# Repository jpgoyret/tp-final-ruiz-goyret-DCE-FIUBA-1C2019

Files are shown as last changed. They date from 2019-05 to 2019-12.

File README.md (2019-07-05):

# tp-final-ruiz-goyret-DCE-FIUBA-1C2019
Trabajo Práctico final de la materia Diseño de Circuitos Electrónicos en FIUBA - 1°C 2019

Integrantes del grupo:

  * Santiago Ruiz (98052)
  * Juan Pablo Goyret (99081)

## Resumen del trabajo práctico

El trabajo consiste en el diseño, simulación y armado en PCB de un amplificador de audio de potencia mayor a 40W. El tipo de amplificador diseñado es un clase H con etapa de salida en paralelo, realizando la conmutación propia de esta configuración mediante transistores MOSFET. Dada la necesidad de alimentar al amplificador clase H mediante dos valores distintos de tensión positiva y negativa, se diseñaron, por otra parte, dos fuente de switching de +12 y -12 V. 

## Descripción del repositorio

El repositorio de encuentra estructurado en 3 carpetas principales: 

- [Amplificador](https://github.com/jpgoyret/tp-final-ruiz-goyret-DCE-FIUBA-1C2019/tree/develop/Amplificador): documentación, simulaciones y proyecto en Kicad del amplificador.
- [Supply](https://github.com/jpgoyret/tp-final-ruiz-goyret-DCE-FIUBA-1C2019/tree/develop/Supply): documentación, simulaciones y proyecto en Kicad de las fuentes de switching.
- [DOC](https://github.com/jpgoyret/tp-final-ruiz-goyret-DCE-FIUBA-1C2019/tree/develop/DOC): referencias para el diseño de los circuitos, artículos útiles y hojas de datos de amplificadores comerciales que se usaron como referencia para el proyecto.

Cada subcarpeta cuenta con un archivo README.md propio describiendo su contenido y como debe ser analizado.

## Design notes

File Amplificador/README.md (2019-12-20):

## Amplificador

Para comenzar con la lectura de la documentación del circuito ir a [Resumen_y_especificaciones.md](Resumen_y_especificaciones.md). Si bien se recomienda comenzar con este útimo archivo, el cual irá dirigiendo al lector hacia otros documentos que permitirán comprender cada vez con mayor profudidad el diseño del circuito, a continuación se listan todos los archivos contenidos en esta carpeta relacionados con el desarrollo del circuito:

- [Resumen_y_especificaciones.md](Resumen_y_especificaciones.md): contiene un resumen de las características del amplificador y lista sus especificaciones. 
- [descripcion_detallada_amplificador.md](descripcion_detallada_amplificador.md): describe las etapas del amplificador y otros subcircuitos que lo componen.
- [determinacion_valores_componentes.md](determinacion_valores_componentes.md): detalla los criterios y cálculos utilizados en la determinación de los valores y tipos de componentes empleados en el circuito.
- [explicacion_conmutadores.md](explicacion_conmutadores.md): describe el funcionamiento de los conmutadores y la utilidad y valor de cada uno de los componentes involucrados en ellos.
- [Mediciones_salida_audio_celular.md](Mediciones_audio_celular.md): este documento no se encuentra relacionado directamente con el diseño del amplificador, pero en él se detallan mediciones que se realizaron con el fin de establece la especificación de ganancia a lazo cerrado del circuito.

Por otra parte, a continuación se listan las subcarpetas asociadas al diseño del amplificador:

- [simulaciones_amplificador](./simulaciones_amplificador): se encuentran los archivos para simular el amplificador completo por medio de LTSpice. Además, en [Mediciones_parametros_simulacion.md](simulaciones_amplificador/Mediciones_parametros_simulacion.md) es posible ver los resultados de las mediciones llevadas a cabo a partir de la simulación. Se han incluido simulaciones específicas para estudiar cada especificación del amplificador. Se han agregado también los modelos necesarios para realizar las simulaciones. Para que estas se lleven a cabo correctamente basta con descargar la carpeta completa y ejecutar los archivos localizados allí adentro. 
- [pcb_amplificador](./pcb_amplificador): diseño del PCB del amplificador. 
- [mediciones_amplificador](./mediciones_amplificador): registro de las mediciones que se realizaron durante el armado del amplificador
- [imagenes_amplificador](./imagenes_amplificador): imágenes varias para la elaboración de documentos como [Resumen_y_especificaciones.md](Resumen_y_especificaciones.md) y [Mediciones_parametros_simulacion.md](simulaciones_amplificador/Mediciones_parametros_simulacion.md) .
- [datasheets_componentes_amplificador](./datasheets_componentes_amplificador): hojas de datos de los transistores y diodos utilizados en el diseño del amplificador.
- [disipadores_amplificador](./disipadores_amplificador): se encuentra la información de los disipadores utilizados y sus fundamentos.

## Resumen de especificaciones
En la siguiente tabla se comparan las especificaciones que se habían establecido como objetivos de diseño con los resultados de las simulaciones y las mediciones. En los títulos de cada columna se encuentra un link a los archivos donde se detallan las especificaciones, y la forma en la que fueron realizadas las simulaciones y las mediciones.

| Parámetro| [Diseño](Resumen_y_especificaciones.md) | [Simulación ](simulaciones_amplificador/Mediciones_parametros_simulacion.md)| [Medición](mediciones_amplificador/mediciones_finales.md) |
|---|---|---|---|
| Potencia máxima |  (No especificado, solo se dio el valor nominal, que es 45W)  | 48W | 51W |
| Eficiencia máxima | 73% | 75% | 77% |
| Alimentación |+-30V/+-12V |  +-30V/+-12V |  +-30V/+-12V  |
| Resistencia de entrada  @1kHz | >20kΩ | 26kΩ | 25KΩ |
| Resistencia de salida | 0,04Ω  	| 0,001Ω | 0,01Ω |
| Máxima tensión de entrada  | 1,2V  | 1,2V  | 1,2V |
| Ganancia de lazo cerrado | 22,8 | 22,8 | 23  |
| Consumo sin señal | <2W | 1,8 | 1,9 |
| Ancho de banda | 10Hz-400kHz | 0,8Hz-1,4MHz |  2Hz-550kHz |
| Ancho de banda de potencia sin conmutación | 40kHz | 150kHz | 53kHz |
| THD (8Ω@1khz/10%potencia)  | 0,01% |  0,0009% | 0.009% |
| Factor de amortiguamiento (8Ω@1kHz)  |	200	| 8000 | 727 |
| PSNR| >-75dB | -76dB | >-66dB |

## Fotos del prototipo

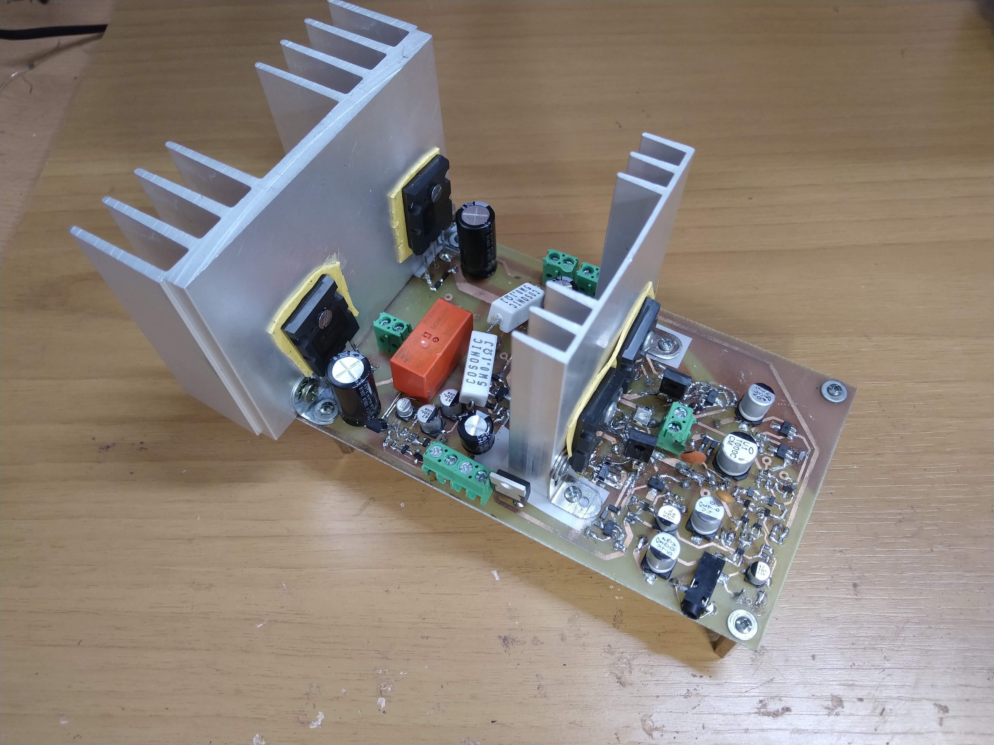
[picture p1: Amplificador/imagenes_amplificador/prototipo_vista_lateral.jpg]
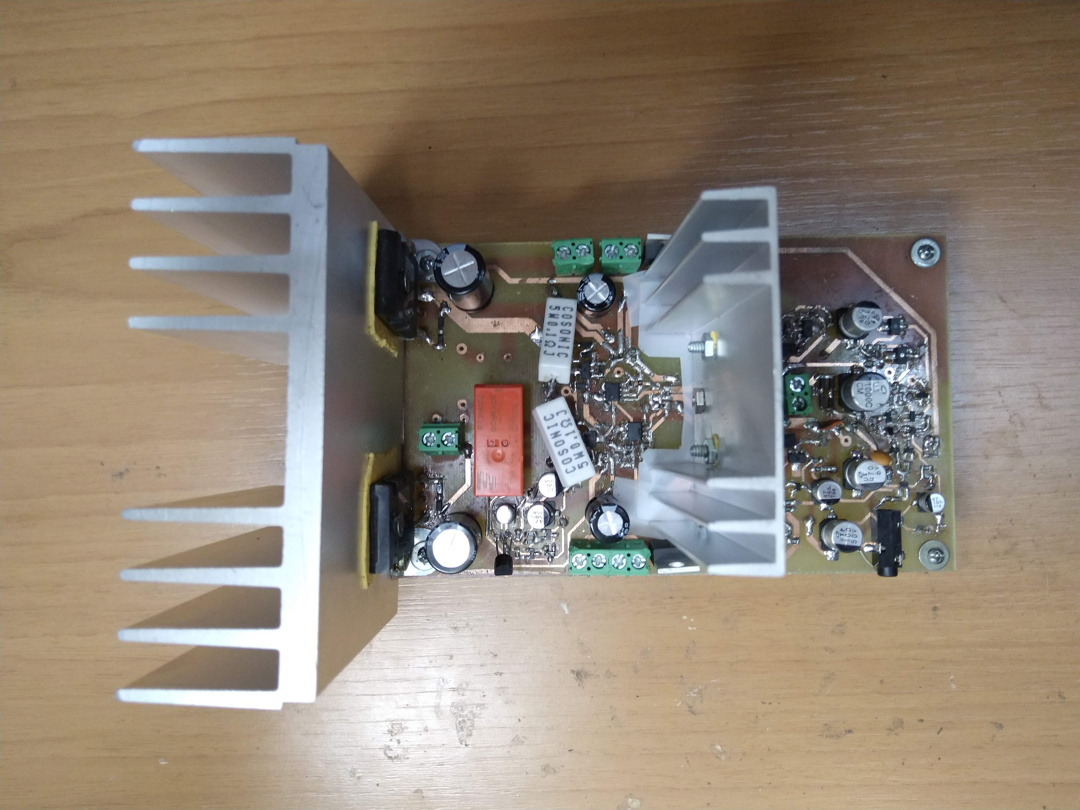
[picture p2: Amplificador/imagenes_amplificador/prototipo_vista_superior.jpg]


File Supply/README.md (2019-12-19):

## Fuente de alimentación

En esta carpeta podrán encontrase todo lo relacionado con el diseño de la fuente de alimentación. Para ver un resumen de la descripción del amplificador junto con sus especificaciones ir a [Resumen_y_especificaciones.md](Resumen_y_especificaciones.md):

- [simulaciones_supply](./simulaciones_supply): se encuentran los archivos para simular fuente de conmutación completa por medio de LTSpice.
- [mediciones_supply](./mediciones_supply): se encuentran los resultados de las mediciones del circuito armado y funcionando, al igual que mediciones intermedias durante el desarrollo. 
- [pcb_supply](./pcb_supply): proyecto en Kicad con el diseño del PCB de la fuente switching. Se incluyen las bibliotecas de componentes y "footprints" necesarios. Para visualizar correctamente el proyecto es suficiente con descargar la carpeta completa y ejecutar los archivos localizados allí adentro.
- [imagenes_supply](./imagenes_supply): imágenes varias para la elaboración de documentos como [Resumen_y_especificaciones.md](Resumen_y_especificaciones.md).

A continuación se resumen las especificaciones principales, comparando los valores en etapa de diseño, en simulación y en la medición del circuito armado:

| Parámetro | [Diseño](Resumen_y_especificaciones.md) | [Simulación](./simulaciones_supply) | [Medición ](./mediciones_supply) |
|---|---|---|---|
| Tensión de salida | 10V-20V | 0.8V-60V | 0.8-32V |
| Corriente máxima | 5A | 5.5A | 5.2A |
| Tensión de entrada | 30V | 3.5V-60V | 3.5V-32V |
| Eficiencia máxima | >80% | 98% | 92% |
| Ripple con carga (8ohm) | <100mVpp | 85mVpp | 40mVpp |
| Ripple sin carga | <100mVpp | (Despreciable) | 106mVpp |
| Frecuencia de operación | >100kHz | 350kHz | 300 - 340kHz |

## Fotos del prototipo

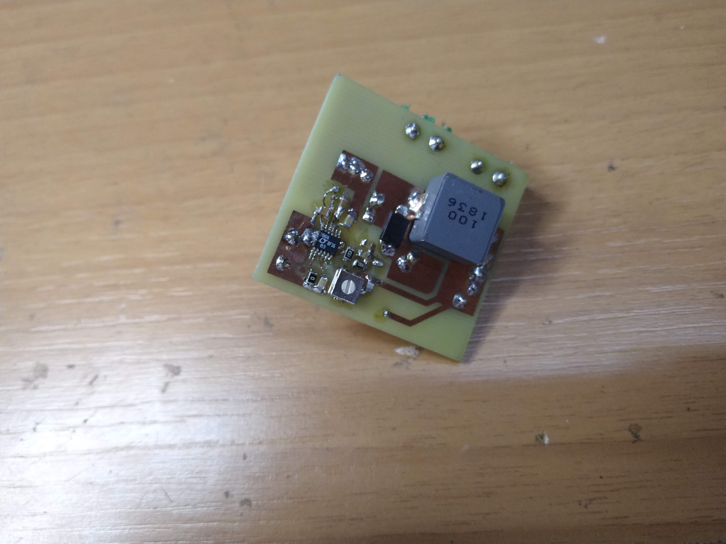
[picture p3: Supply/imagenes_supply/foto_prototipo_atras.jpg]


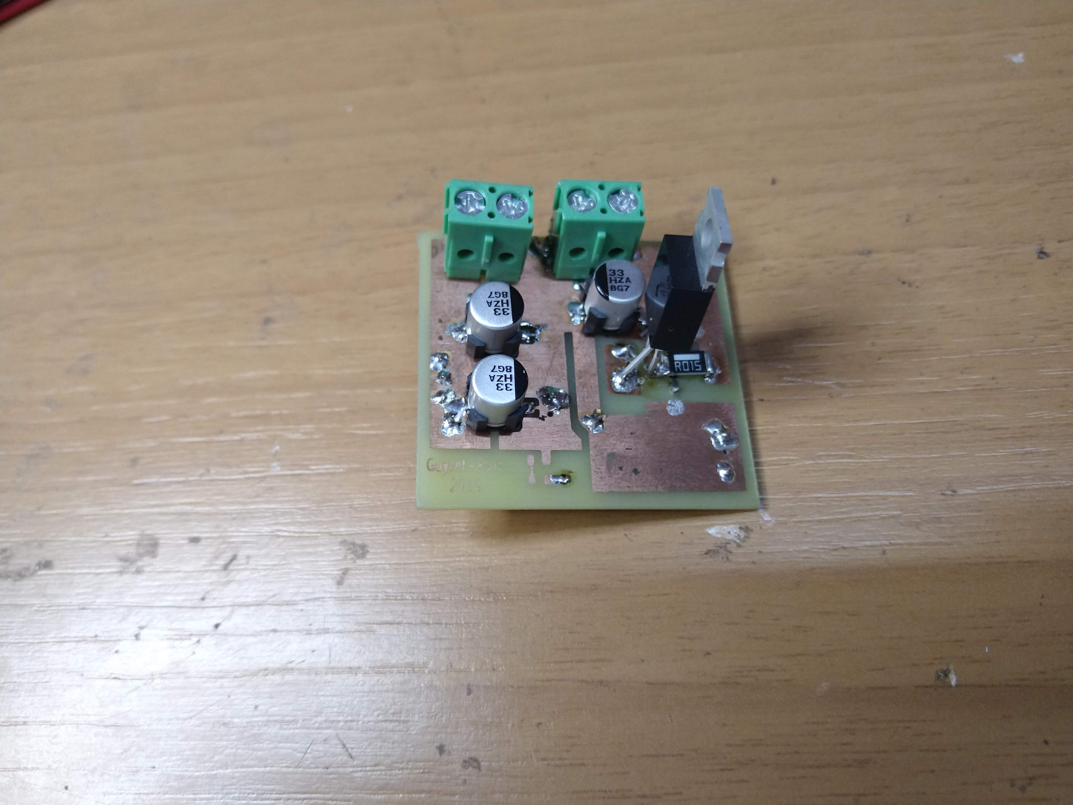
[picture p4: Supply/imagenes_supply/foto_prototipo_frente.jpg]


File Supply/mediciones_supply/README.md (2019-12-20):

## Registro de las mediciones realizadas durante el diseño de la fuente conmutadora

En esta carpeta se incluye un registro de las mediciones realizadas durante el armado de la fuente conmutadora, identificadas por fecha según el progreso realizado. Las fechas de las mediciones fueron las siguientes:

- [5/7/19](Mediciones_supply_5_7_19.md)
- [15/7/19](Mediciones_supply_15_7_19.md)

## Mediciones finales

### Regulación de linea
Se midió la salida de la fuente para distintos valores de alimentación. Las mediciones fueron realizadas con un multímetro UNI-T UT39B, con una incertidumbre de 0,5% + 3 dígitos.
Se obtuvieron los siguientes resultados:

| V_in | E(V_in) | V_out | E(V_out) |
| --- | --- | --- | --- |
| 29,9V | 0,5V | 12,00V | 0,1V  |
| 24,9V | 0,4V | 11,96V | 0,1V |
| 19,9V | 0,4V |  11,88V  | 0,1V |
| 16,9V | 0,4V |  11,83V | 0,1V |
| 12,98V | 0,1V |  11,83V | 0,1V |

Donde E(X) denota la incertidumbre del parámetro X.

Realizando el cálculo de la regulación de linea con la primer y la tercer fila de la tabla (ya que si se usara la segunda diferencia de los valores obtenidos caería dentro de la incertidumbre de medición) se obtiene:

 

No se reporta la incertidumbre del porcertaje de ripple ya que este resulta demasiado grande en comparación con el valor medio calculado.

### Regulación de carga
Se midió la tensión media de salida con una carga de 9,3ohm y con la salida en vacío. Las mediciones se llevaron a cabo con un multímetro UNI-T UT39B, con una incertidumbre de 0,5% + 3 dígitos. 
Con una tensión de alimentación de 30V se obtuvo:

- Sin carga:  
- Con carga:   

Se tuvo entonces una diferencia en la tensión media de salida de:

 

No se reporta una incertidumbre ya que esta mayor que el valor medido en sí. Entonces, el resultado obtenido solo representa una impresión de como se comporta la fuente conmutada en cuanto a su regulación de carga.

### Ripple
Se realizaron dos pruebas: en la primera se midió el ripple a la salida en vacio, es decir, sin carga. Las mediciones se realizaron con un osciloscopio RIGOL DS1302CA, con punta X10, filtro de 20MHz y modo de adquisición promediador en 8.

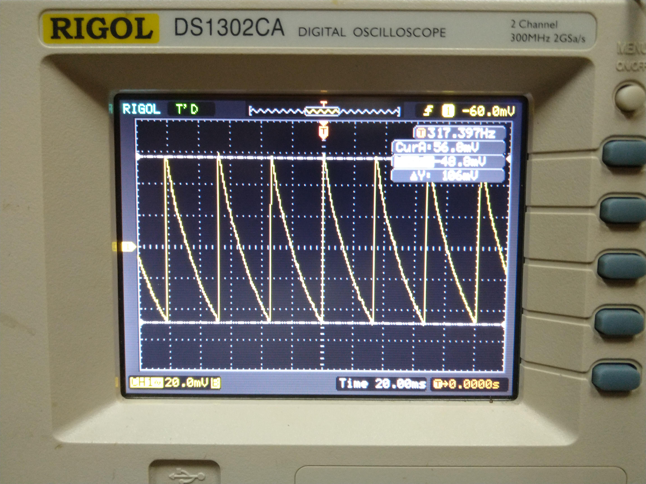
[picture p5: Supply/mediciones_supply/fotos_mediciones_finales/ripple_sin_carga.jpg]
 

Se obtuvo un ripple de  .

Luego, se midió el ripple con una carga de 8ohm.

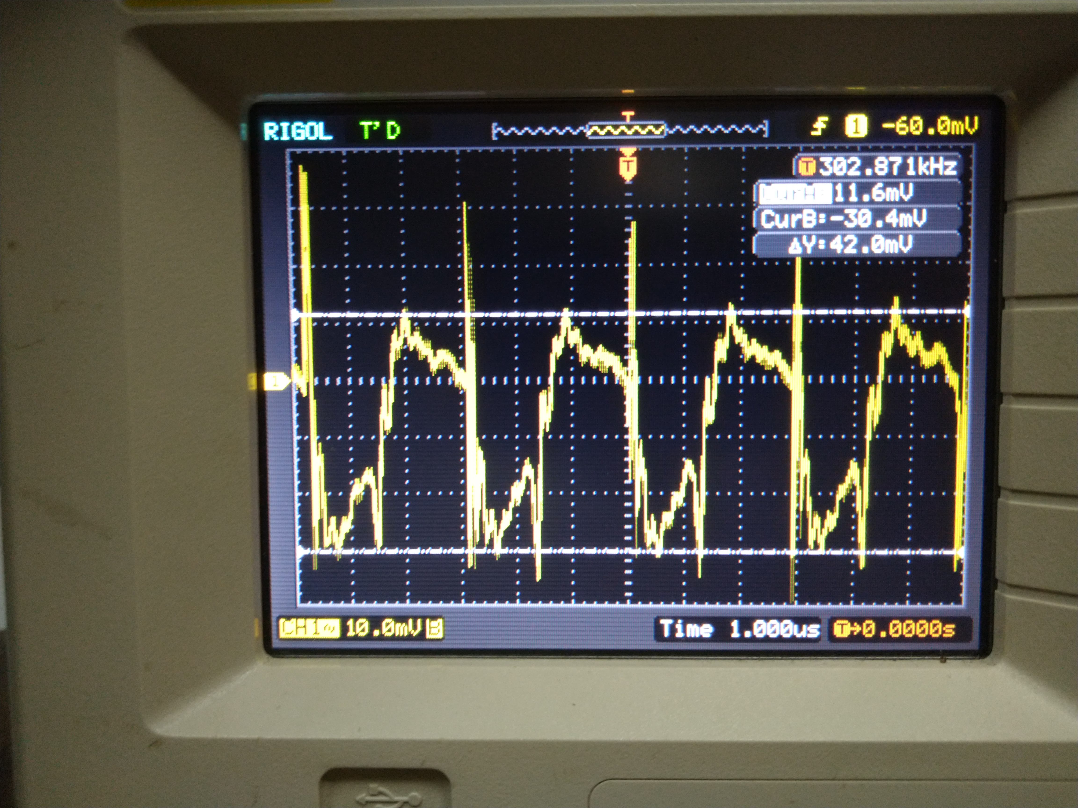
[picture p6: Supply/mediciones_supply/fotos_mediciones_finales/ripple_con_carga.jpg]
 

Se obtuvo un ripple de  .

### Eficiencia
Condición de medición: R_out=10.1ohm 25W

| V_in | I_in | V_out | I_out | Eff |
| --- | --- | --- | --- | --- |
| 29V | 0.59A | 11.98V | 1.19A | 83% |
| 20V | 0.83A | 12.1V  | 1.2A  | 87% |
| 15V | 1.1A  | 12.27V | 1.21A | 90% |
| 13V | 1.25A | 12.3V  | 1.22A | 92% |

### Emisiones
Se probó medir a simple vista y comparar las emisiones de la fuente cuando se encontraba cargada con 8ohm o sin ella. Para ello se conectó la punta del osciloscopio con si misma para formar una antena y se la acerco a 5cm del transistor de la fuente aproximadamente. Los resultados obtenidos fueron los siguientes:

Para emisiones con carga:

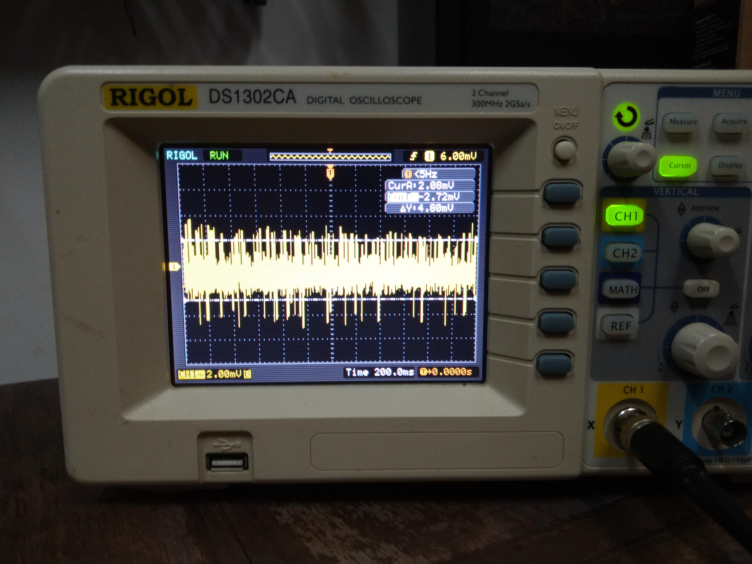
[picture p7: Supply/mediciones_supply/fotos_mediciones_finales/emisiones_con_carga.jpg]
 

Para emisiones con carga:

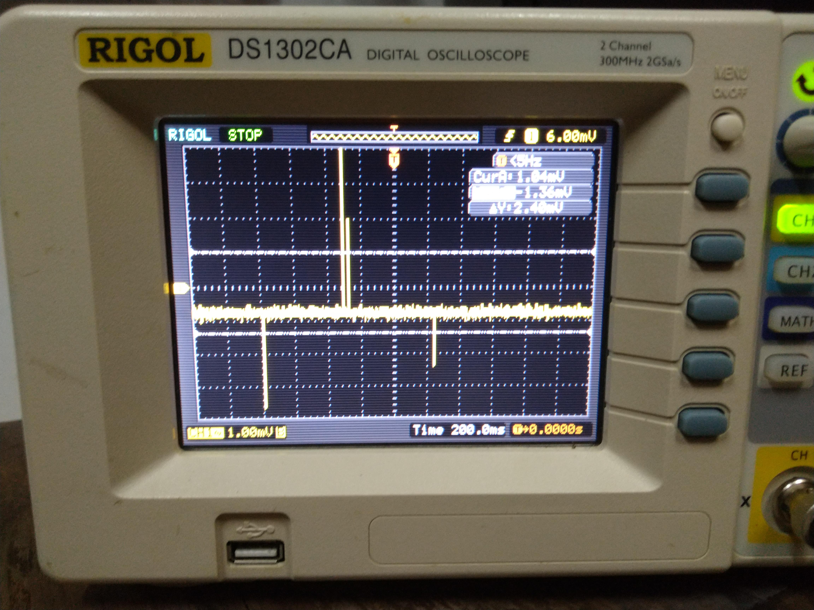
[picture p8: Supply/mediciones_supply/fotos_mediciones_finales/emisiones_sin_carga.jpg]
 

Se ve que las emisiones son mucho mayores en el primer caso ya que el consumo de corriente de la fuente es mucho menor. En consecuencia, el integrado que controla a la switching entra en un modo donde deja intervalos de tiempo en los que no conmuta, ya que no es necesario cargar al capacitor de salida. Por esto es que en la segunda imagen se obvservan pulsos espaciados, y no continuos como en la primer foto.

### Frecuencia de operación
Se realizaron varias mediciones y se observó que, con carga, la frecuencia de operación variaba entre aproximadamente 300kHz y 350kHz. Por ejemplo, en la imagen del ripple con carga que se mostró anteriormente, este era de 320kHz. Por otra parte, para mediciones sin carga, la fuente disminuye su frecuencia de operación ya que la corriente que se le pide a la salida es muy baja. Como se puede ver en la captura del ripple sin carga, esta frecuencia ronda los 300Hz.

Los valores de las frecuencias fueron obtenidos utilizando el contador interno de un osciloscopio RIGOL DS1302CA

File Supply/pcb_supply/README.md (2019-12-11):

## Fuente de alimentación

En esta carpeta se encuentra el proyecto de diseño del PCB realizado en _KiCad_.
Se observa a continuación el esquemático circuital y el diseño final del PCB.

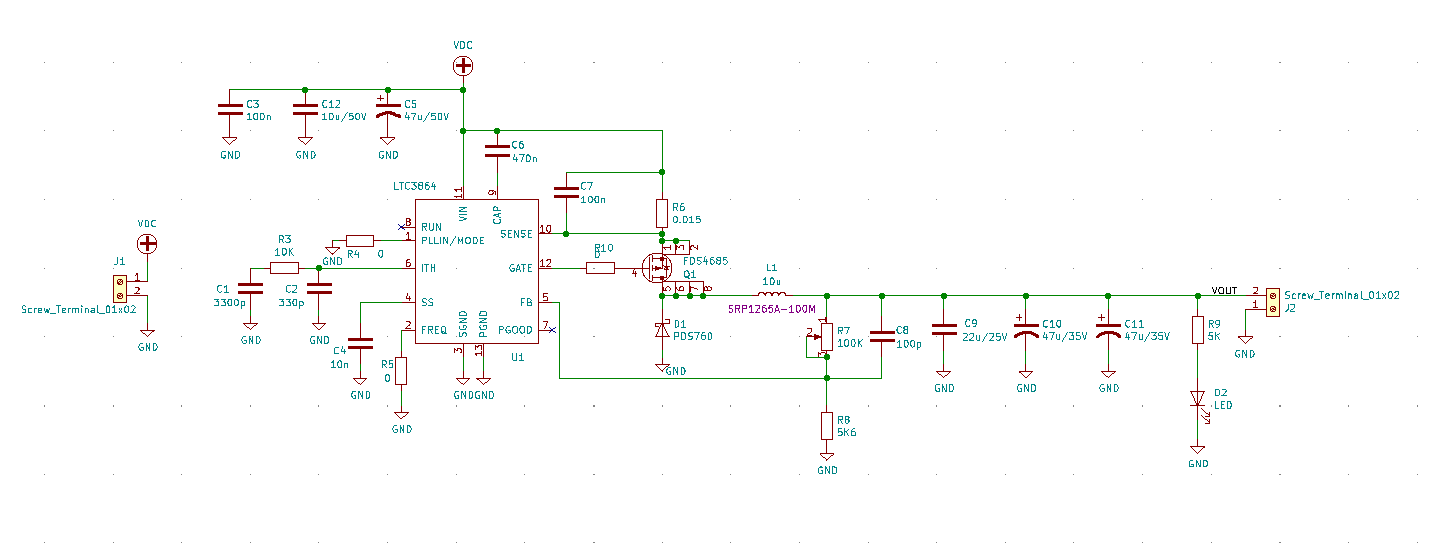
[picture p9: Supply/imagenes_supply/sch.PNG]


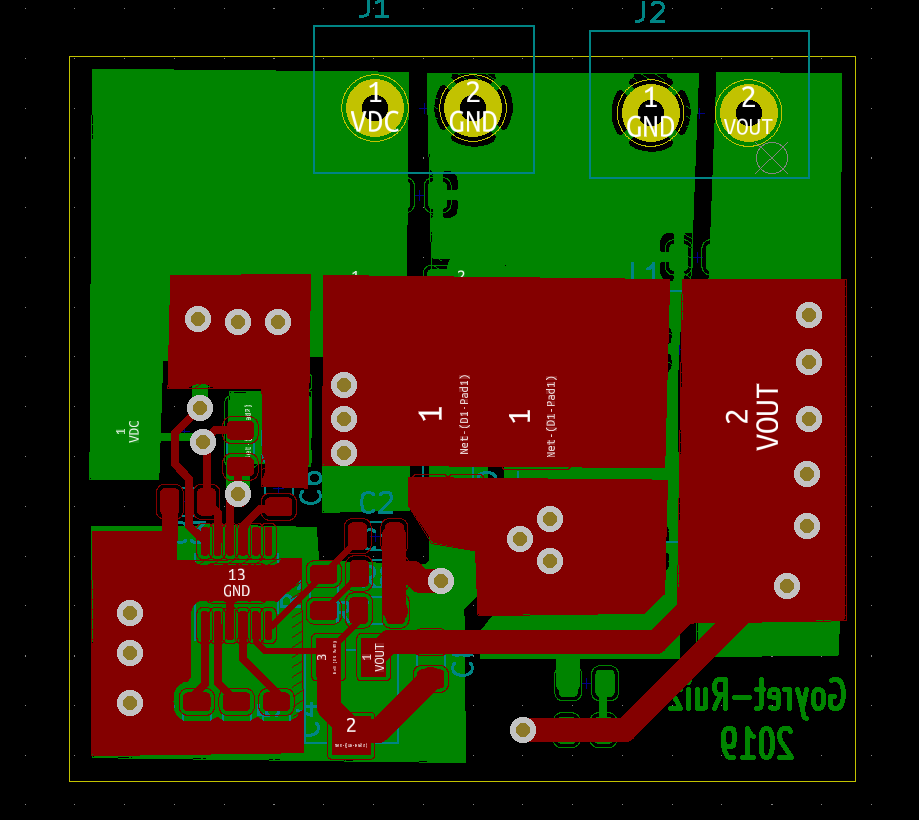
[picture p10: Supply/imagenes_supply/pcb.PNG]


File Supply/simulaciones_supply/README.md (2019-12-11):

## Mediciones de parámetros

### Regulación
Se realiza la simulación para Vin=28V, Vout=12V, RL=8Ω y se grafica Vout en función del tiempo:

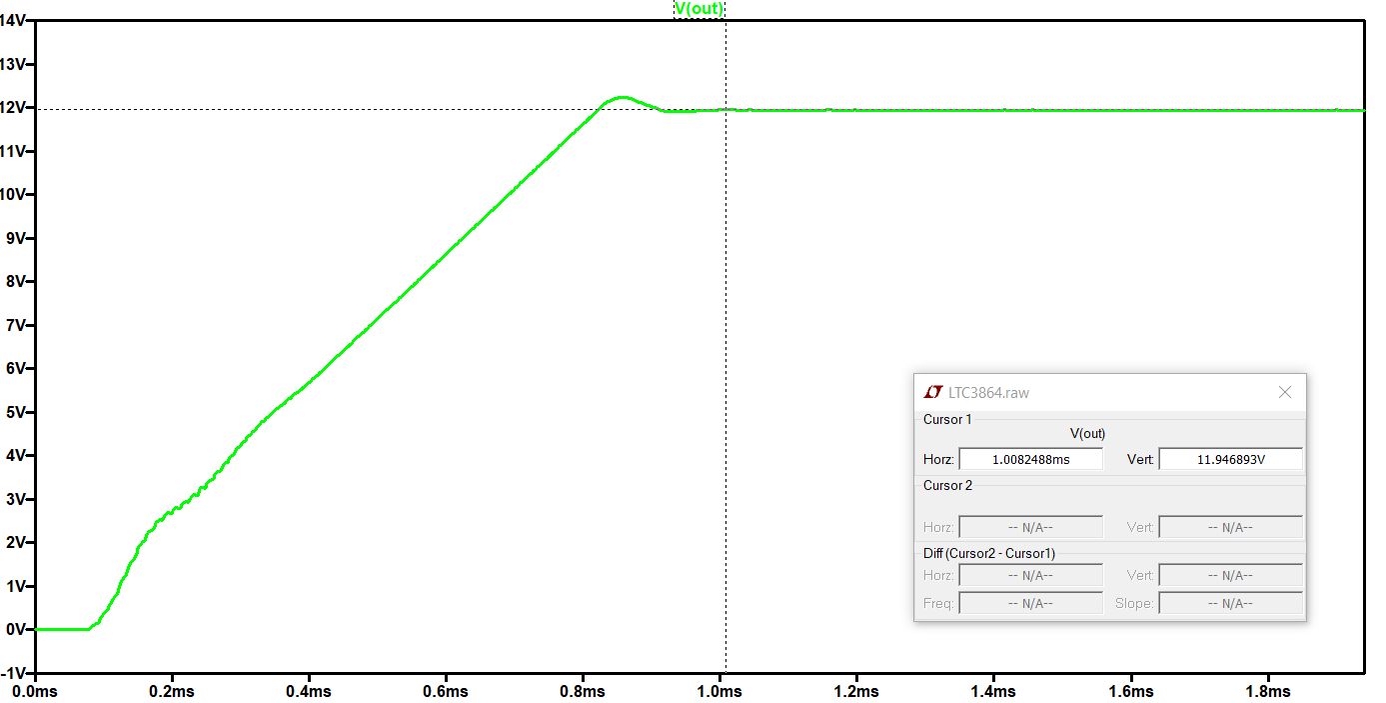
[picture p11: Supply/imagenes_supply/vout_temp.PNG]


Se observa una tensión de salida de 12V, con un tiempo de *soft-start* de 1ms. 

### Ripple
Se aumenta en el sector estable de Vout y se mide el ripple de salida para RL=8Ω

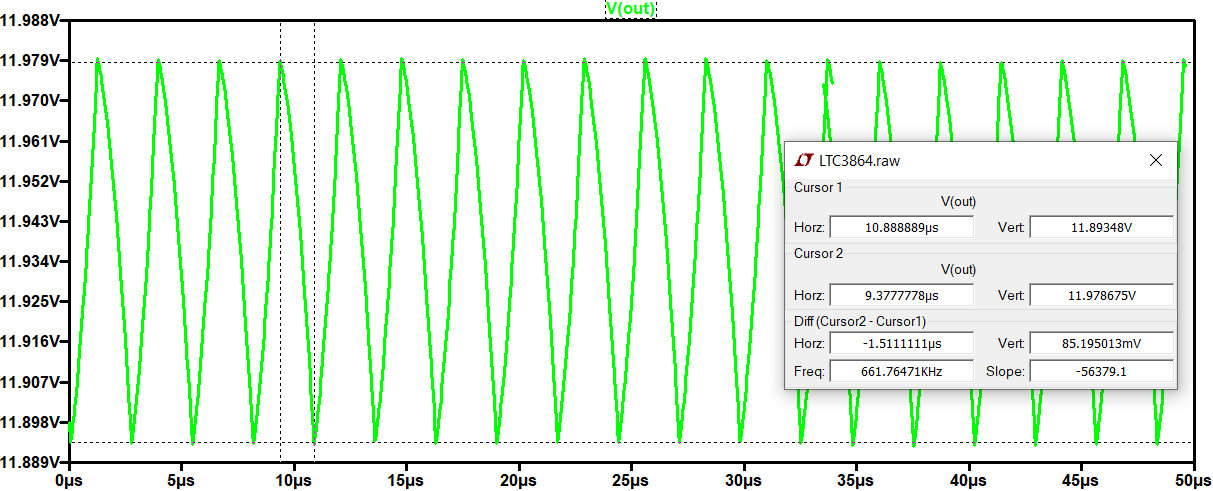
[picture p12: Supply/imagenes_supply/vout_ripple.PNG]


Se observa un ripple de 85mVpp.

### Corriente máxima
Para la siguiente simulación se colocó una carga de 0.001Ω (cortocircuito) y se graficó la corriente de salida:

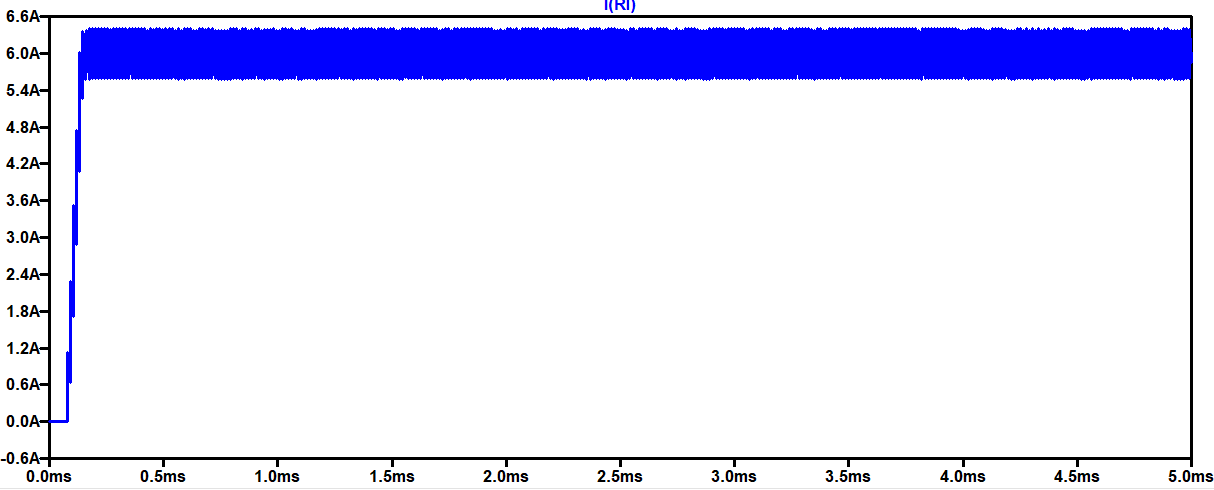
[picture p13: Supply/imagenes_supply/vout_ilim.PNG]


Se observa que la corriente de salida es de Iout=6A

### Eficiencia

Luego se mide la eficiencia del circuito con lel metodo explicado por *LTSpice* para este tipo de circuito ([link](https://www.analog.com/en/technical-articles/ltspice-using-meas-and-step-commands-to-calculate-efficiency.html)). Se obtienen los siguientes resultados:

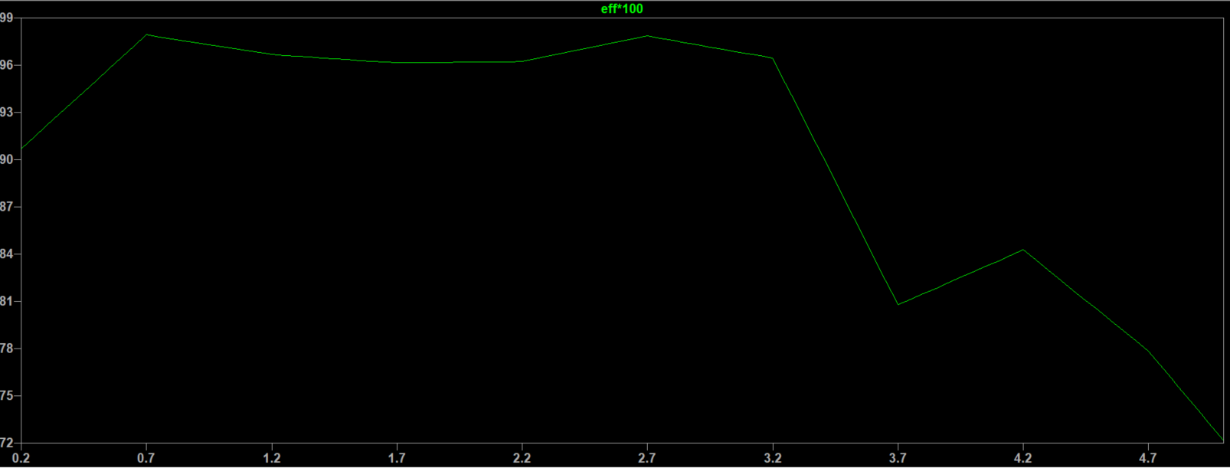
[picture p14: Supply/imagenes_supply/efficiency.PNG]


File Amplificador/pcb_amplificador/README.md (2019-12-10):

## Diseño del PCB del amplificador

En la carpeta [proyecto_kicad](./proyecto_kicad) se encuentran los archivos del proyecto en Kicad donde se diseñó el PCB del amplificador al mes de junio de 2019. Se incluyen las bibliotecas de componentes y "footprints" necesarios. Para visualizar correctamente el proyecto es suficiente con descargar la carpeta completa y ejecutar los archivos localizados allí adentro.

Por otra parte, en la carpeta [proyecto_kicad_actualizado](./proyecto_kicad_actualizado) se encuentra el proyecto de Kicad donde se han ido incluyendo las modificaciones hechas sobre el prototipo en un PCB rediseñado. El objetivo es que este sea una segunda resivisión del amplificador.

El diseño del PCB del amplificador fue realizado queriendo conservar el eje de simetría del amplificador con el fin facilitar su análisis. 

Los transistores de potencia que funcionan alimentados con +12V y -12V se encuentran colocados en la parte central de la placa, asociados a un mismo disipador (identificado por las líneas azules en el centro de placa en la captura que se observa más abajo) que el del multiplicador de Vbe para evitar un embalamiento térmico. Por otra parte, los transistores de potencia alimentados con +30V y -30V se situan  la derecha de la placa, asociados al disipador de mayores dimensiones. 

En entre unos y otros transistores de potencia se han colocado los conmutadores, cuyos transistores MOSFET son los integrados que se pueden observar en el PCB. A pesar de introducir mayores complejidades en el diseño del PCB, se han utilizado transistores MOSFET complementarios integrados con el fin de evitar distorsión por el hecho de que los NMOS y PMOS tuvieran distintas características e introdujeran asimetrías en el comportamiento de los conmutadores para el semiciclo positivo con respecto al negativo y viceversa.

La protección contra DC, incluyendo el relé, se encuentra a la derecha de los conmutadores y a la izquierda de los transistores de potencia que funcionan con +30V y -30V.

A la izquierda de la placa se encuentra el par diferencial, estando a su derecha la VAS.

En cuanto a los conectores, arriba a la izquierda se encuentra en puerto de audio de 3,5mm junto con con 3 pines para conectar un generador de funciones. En eje horizontal de placa y del lado izquierdo del disipador pequeño se encuentra una bornera utilizada para la conexión a tierra. Luego, sobre el eje vertical, arriba y abajo de la placa se encuentran las borneras de alimentación por las cuales ingresan +12V y +30V (arriba), y -12V y -30V (abajo). Finalmente, entre los transistores de potencia conectados a +30V y -30V se encuentra la bornera de salida de señal a el parlante. 

A continuación, de muestra una captura del PCB realizado en Kicad:

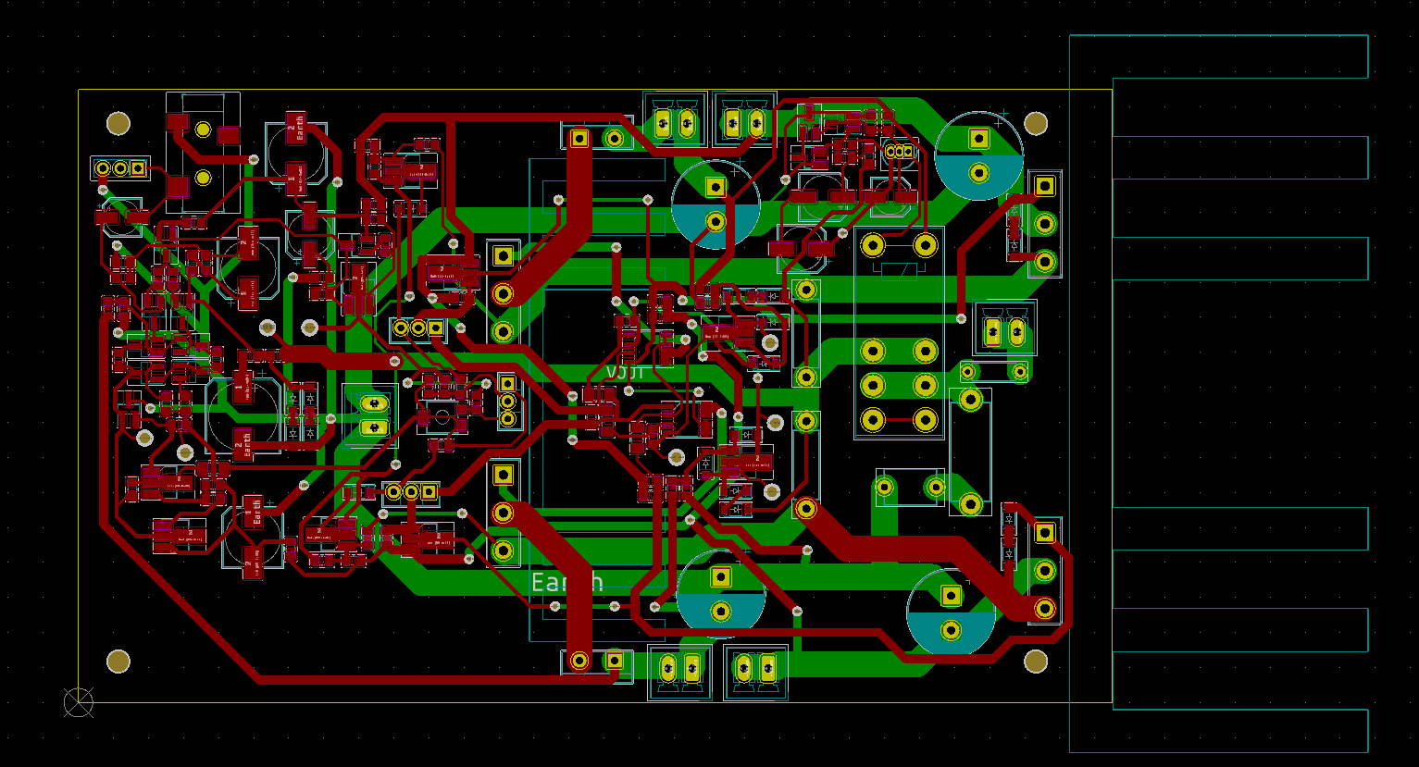
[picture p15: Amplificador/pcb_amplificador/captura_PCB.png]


Y una vista 3D:

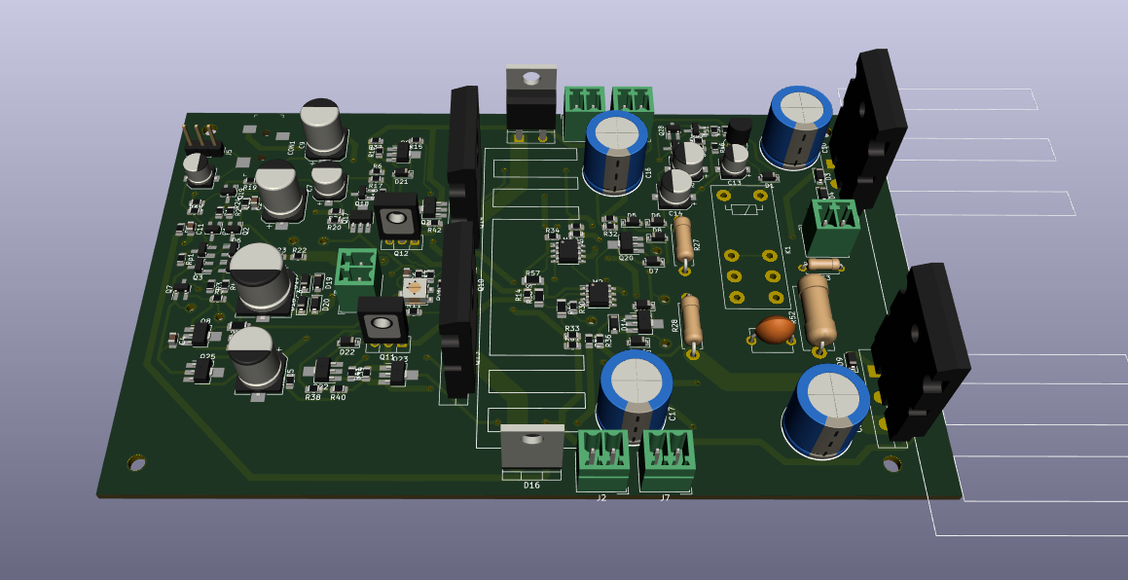
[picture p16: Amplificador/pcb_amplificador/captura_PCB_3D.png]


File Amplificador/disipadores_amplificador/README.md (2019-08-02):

## Disipadores del amplificador

Los disipadores fueron elegidos en función de los valores de máxima disipación en los transistores hallados a partir de la simulación en [Mediciones_parametros_amplificador.md](../simulaciones_amplificador/Mediciones_parametros_simulacion.md). De allí se obtuvo:

- Pot_max_U1 = 3,3W (transistores alimentados con +12V y -12V)
- Pot_max_U2 = 17W (transistores alimentados con +30V y -30V)

La resistencia térmica juntura-encapsulador de los transistores elegidos es 0,8°C/W y la máxima temperatura de juntura tolerable es 150°C. En consecuencia, los valores mínimos de resistencia térmica de un disipador para cada transistor deben ser:

- Res_U1 = 36 °C/W
- Res_U2 = 5,5 °C/W

Utilizando un solo disipador en común para los dos transistores alimentados con +12V y -12V (ya que deben ir acoplados térmicamente con el multiplicador de Vbe para evitar su embalamiento), se debe dividir la resistencia térmica por 2. De este modo, se requiere un disipador de como mínimo 18 °C/W.

Haciendo lo mismo para los transistores alimentados con +30V y -30V ya que se decidió darles un único disipador a los dos por motivos de espacio en el PCB a la hora de montarlos, se llega a que se requiere un disipador de como mínimo 2,75°C/W.

Analizando las opciones comerciales disponibles, se decidió optar por la siguientes alternativas:

###### Disipador baja potencia

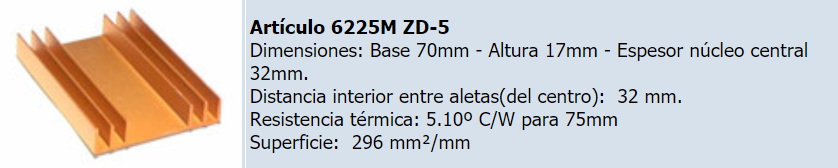
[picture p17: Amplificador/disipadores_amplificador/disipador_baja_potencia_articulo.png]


Con ello, la máxima temperatura alcanzada en los transistores de baja potencia será:

T = 3,3W x (0,8 °C/W + 2 x 5,1 °C/W) = 36°C

Se eligió este disipador ya que sus dimensiones a lo ancho permiten colocar los dos transistores de baja potencia y el del multiplicador de Vbe uno al lado del otro para mayor acoplamiento térmico.

###### Disipador alta potencia



Con ello, la máxima temperatura alcanzada en los transistores de alta potencia será:

T = 17 W x (0,8 °C/W + 2 x 1,8 °C/W) = 75 °C

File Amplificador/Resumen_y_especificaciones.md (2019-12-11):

# Resumen del amplificador amplificador diseñado y sus especificaciones

A continuación se hace una descripción del amplificador diseñado junto con sus especificaciones. Para ver las simulaciones en base a las cuales se fundamentan dichas especificaciones ir a [Mediciones_parametros_simulacion.md](simulaciones_amplificador/Mediciones_parametros_simulacion.md). Por otra parte, para una explicación más detallada de cada etapa y subcircuitos del amplificador ir a [descripcion_detallada_amplificador.md](descripcion_detallada_amplificador.md). Finalmente, en el archivo [determinacion_valores_componentes.md](determinacion_valores_componentes.md) se encuentran fundamentados los valores de los componentes utilizados en cada etapa/subcircuito del amplificador según se lo presenta en [descripcion_detallada_amplificador.md](descripcion_detallada_amplificador.md).

Se recomienda leer la documentación del amplificador comenzando por este archivo, para luego ir a [determinacion_valores_componentes.md](determinacion_valores_componentes.md) con el fin de obtener una perspectiva general de los componentes del amplificador, y finalmente a [descripcion_detallada_amplificador.md](descripcion_detallada_amplificador.md).

## Características generales del amplificador

 - Clase H con transistores de salida en paralelo y conmutación entre los drivers y los transistores de potencia realizada con transistores MOSFET.
 - Diseñado para recibir señal por medio de un celular o reproductor de música por medio de un conector de audio analógico de 3.5mm.
 - Apto para cargas de 4 u 8ohm. Los limitadores de corriente fueron diseñados para una carga de 3ohm como margen de seguridad para la correcta operación del amplificador.

## Esquema
Como base para el diseño se ha utilizado el amplificador clase G perteneciente a la página 307 del libro "Audio Power Amplifier Handbook" de Douglas Self.

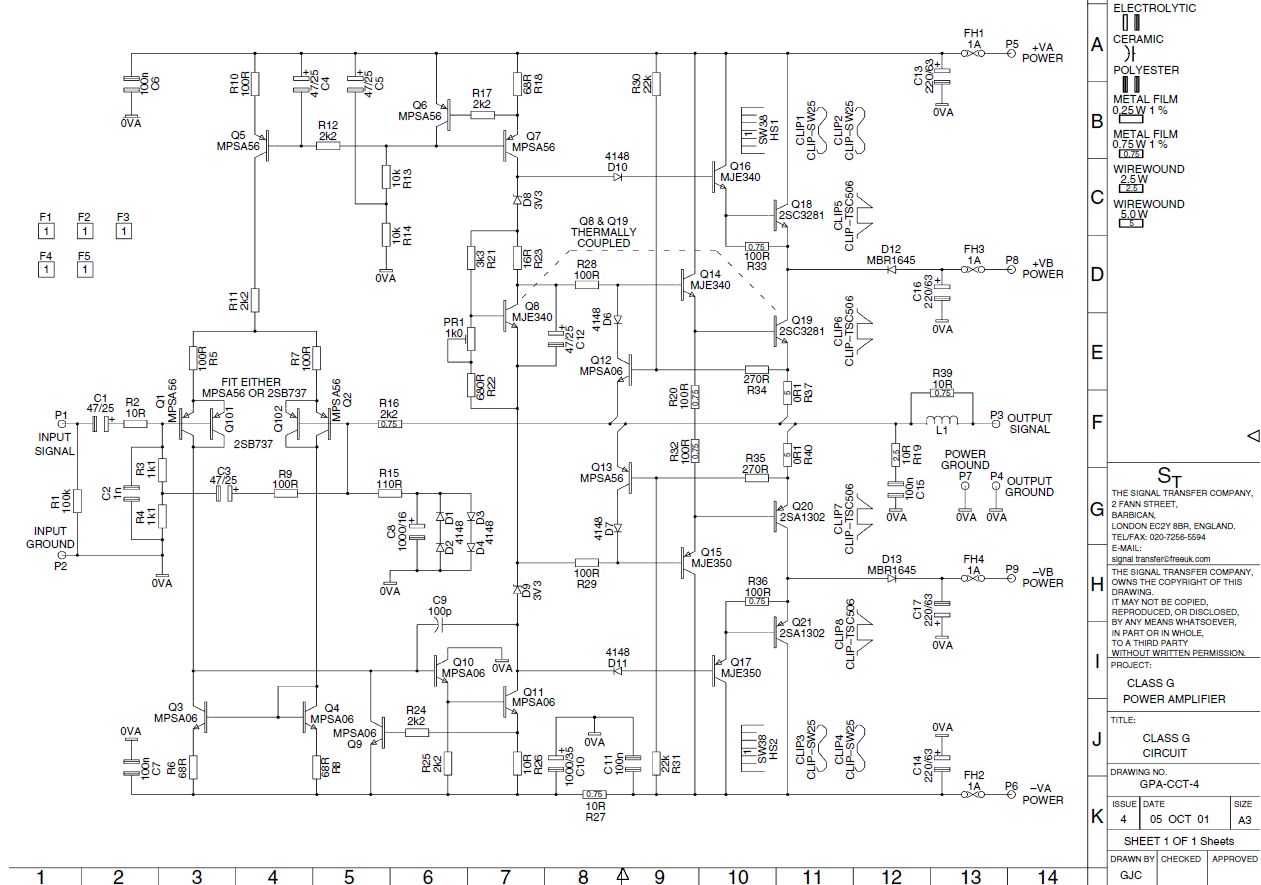
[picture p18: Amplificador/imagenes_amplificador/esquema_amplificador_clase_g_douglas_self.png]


A dicho amplificador se le ha reemplazado la etapa de salida serie clase G por una etapa clase H donde los transistores de salida que utilizan las tensiones de alimentación más baja y más alta operan en paralelo. También se modificó al etapa diferencial y se la hizo cascode para mejorar la PSRR con respecto a la fuente de alimentación de -30V  (-Vmax en la imagen) .  El diagrama original del amplificador diseñado se presenta a continuación (sin añadir la protección de DC, ni colocar la carga en el nodo de salida Vout):

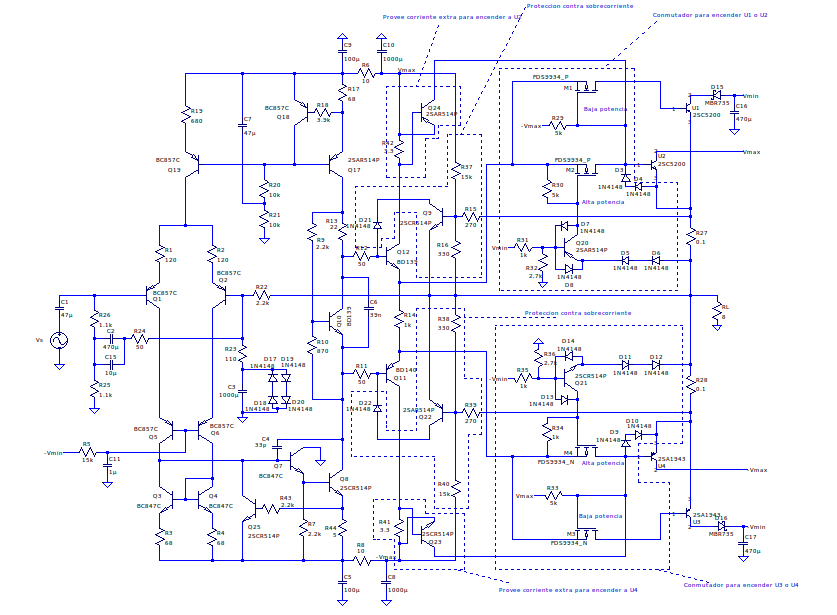
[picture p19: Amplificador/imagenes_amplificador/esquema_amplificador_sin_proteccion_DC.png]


En el esquema:
Vmax = 30V
-Vmax = -30V
Vmin = 12V
 -Vmin = -12V

## Especificaciones del amplificador
 - Máxima entrada de tensión: 1.2V. Se estima que la salida de audio máxima de un celular tiene un valor de 1V rms. Para realizar esta estimación se usaron las referencias en [5], [6] , [7] y [8] en el archivo [Referencias.md](../DOC/Referencias.md) y las mediciones en [Mediciones_salida_audio_celular.md](Mediciones_salida_audio_celular.md). En función de estos datos se decidió que el amplificador tendría una ganancia a lazo cerrado mayor a la necesaria para tener máxima excursión con 1Vrms a la entrada debido a la posibilidad de que algunos celulares no sean capaces de alcanzar este valor (ver el caso del Samsung Galaxy Note 4 en [Mediciones_salida_audio_celular.md](Mediciones_salida_audio_celular.md)).

 - Ganancia a lazo cerrado: 22.8.

 - Consumo sin señal: menor a 2 W (contemplando todas las corrientes consumidas por el circuito; incluyendo la polarización de los conmutadores de la etapa de salida y las protecciones).

 - Protecciones: 

      - Limitación de corriente de salida en función de la tensión máxima de salida. Esto protege a los transistores de potencia. En [Mediciones_parametros_simulacion.md](simulaciones_amplificador/Mediciones_parametros_simulacion.md) se presenta una análisis del comportamiento de estos limitadores. A continuación se presenta una esquema del limitador para los transistores de salida que operan con +12 y +30 V:
      
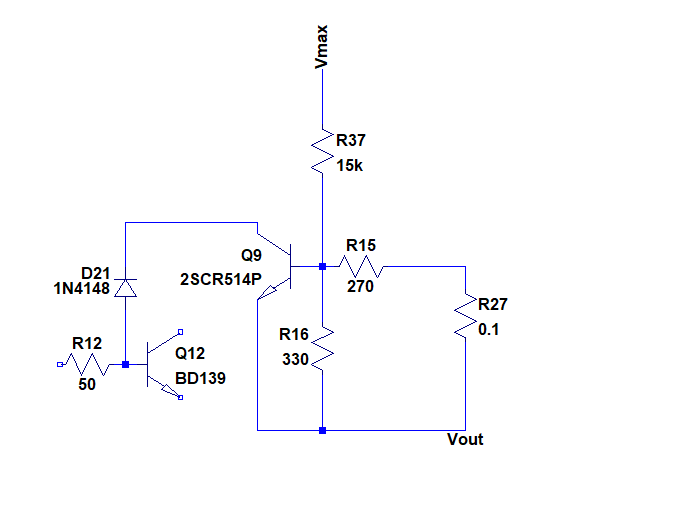
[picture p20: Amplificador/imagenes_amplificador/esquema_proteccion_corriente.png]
      
      
      - Contra la componente de continua en el nodo de salida. Esto protege a los parlantes de una eventual tensión de continua en dicho punto en caso de una falla del amplificador. Tensión de DC a a partir de la cual actúa el limitador: aproximadamente 0.6 V. Velocidad de respuesta del limitador: al menos 100ms. A continuación se muestra un esquema de dicha protección, la cual se conecta al nodo de salida del amplificador:

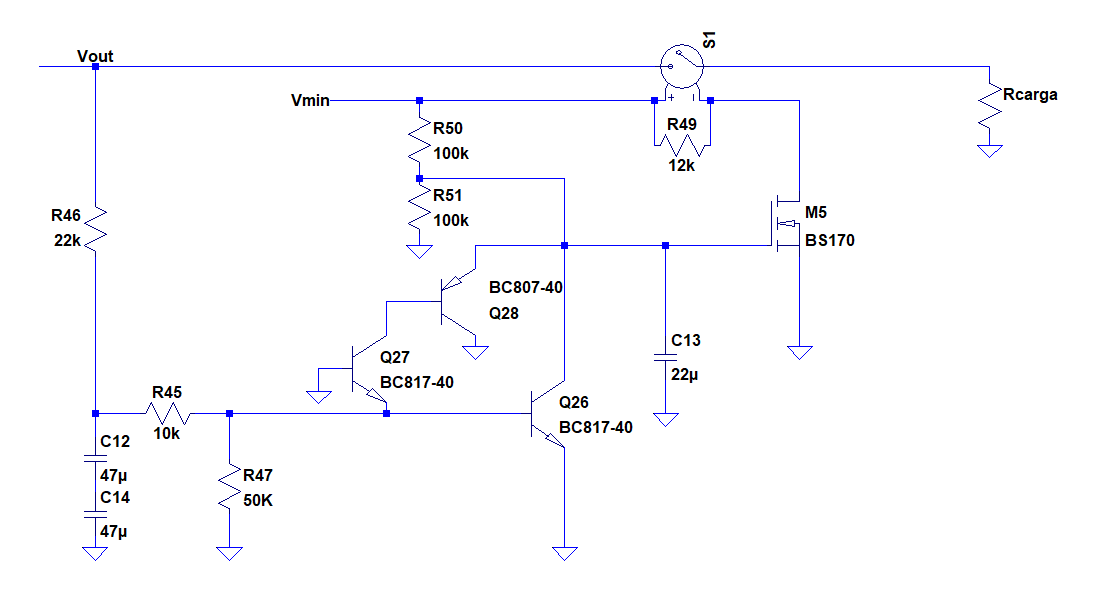
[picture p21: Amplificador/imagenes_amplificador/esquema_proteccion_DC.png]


 - Tensiones de alimentación:
	- V1 = 30 V
	- V2 = 12 V
	
 - Potencia nominal para las cargas especificadas:
    - 4ohm --> Pnom = 85 W
    - 8ohm --> Pnom = 45 W
    
 - Eficiencia máxima (carga de 4ohm): 73% (valor obtenido mediante simulación: 75%).

 - Factor de amortiguación (en el rango de 20Hz a 20kHz): 
   
     - 4ohm: 400 (valor simulado: 360)
     - 8ohm: 200 (valor simulador: 180).
     
 - Resistencia de entrada: al menos R_i = 20 kohm para frecuencias entre 20Hz y 20kHz (se simuló y se obtuvo este resultado).

 - Ancho de banda: f_i = 10Hz, f_h = 400KHz (valores simulados: f_i = 0.8Hz, f_h = 1.4MHz).

 - Ancho de banda de potencia: 40kHz  (valor simulado: 150kHz. No es posible determinarlo con precisión por análisis de la FFT porque antes se presenta la distorsión por la conmutación de la etapa de salida). Ver nota al final de este archivo para ver los motivos de la diferencia entre la especificación y el valor obtenido por simulación.

 - TDH: valores simulados entre paréntesis. La simulaciones se realizaron con una corriente de colector de la etapa de salida Ic = 10mA. Se utilizaron los primeros 9 armónicos de 5 periodos consecutivos de la señal de salida.
	- 8ohm y 1kHz:
	  - 90% pot. nominal (V_i = 1.16V): 0,05% (0.001591%)
	  - 50% pot. nominal (V_i = 860mV): 0.02% (0.002027%) 
	  - 10% pot. nominal (V_i = 385mV): 0,01% (0.0009%) 
	- 8ohm y 10kHz:
	  - 90% pot. nominal (V_i = 1.16V): 0,2% (0.021011%) 
	  - 50% pot. nominal (V_i = 860mV): 0,08% (0.030388%) 
	  - 10% pot. nominal (V_i = 385mV): 0,05% (0.008930%) 
	- 4ohm y 1kHz:
	  - 90% pot. nominal (V_i = 1.12V): 0,05% (0.001918%) 
	  - 50% pot. nominal (V_i = 840mV): 0.02% (0.002363%) 
	  - 10% pot. nominal (V_i = 375mV): 0.01% (0.001492%) 
	- 4ohm y 10kHz:
	  - 90% pot. nominal (V_i = 1.12V): 0.25% (0.027886%) 
	  - 50% pot. nominal (V_i = 840mV): 0.16%  (0.039084%) 
	  - 10% pot. nominal (V_i = 375mV): 0.08%  (0.014913%)
	
 - Distorsión por intermodulación: 0,02 % a 1W/8ohm (valor medido: 0.0092% ; señales de prueba de 100Hz-182 mV y 5kHz-46mV)

 - PSNR:  menor a -75dB para el rango de frecuencias medias. 

     Las simulaciones reportaron un valor de al menos -76dB para este rango. Este último valor se corresponde con el rechazo de ruido con respecto a la fuente de alimentación inferior suponiendo una resistencia nula en el cable que conecta la fuente de alimentación con el amplificador. Si se asume que dicha resistencia es de 1Ohm, la PSNR máxima es -79dB. El resto de las fuentes de alimentación reportan una PSNR menor a -90dB.

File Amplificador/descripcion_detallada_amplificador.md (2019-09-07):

# Descripción de las etapas y subcircuitos del amplificador

En este archivo se realiza una descripción más detallada y cualitativa de cada una de las etapas del amplificador y sus funciones. La justificación de los valores de los componentes del circuito llevadas a cabo tanto desde la teoría como desde la simulación puede verse en [determinacion_valores_componentes.md](determinacion_valores_componentes.md)

## Etapas

#### Etapa diferencial

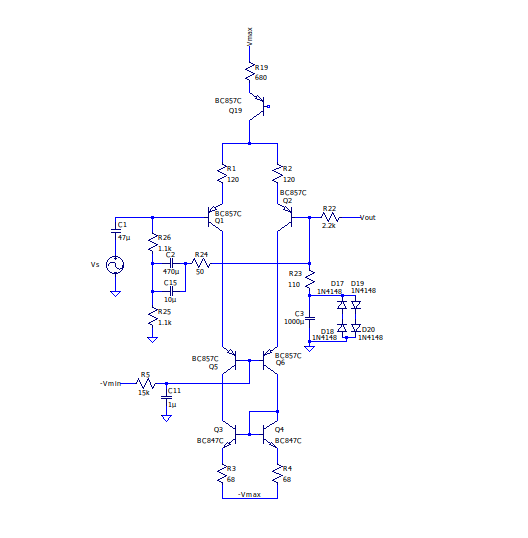
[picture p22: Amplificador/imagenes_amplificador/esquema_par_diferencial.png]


La etapa diferencial constan de un par cascode PNP con degeneración de emisor (mediante R1 y R2) para reducir la alinealidad de la etapa, disminuyendo la distorsión. Dicho par posee una carga espejo simple con emisores degenerados (mediante R3 y R4). 

Se eligió un par cascode debido a que se caracteriza por una mejor PSNR a bajas frecuencias con respecto a las alimentación de -30V.

La corriente de cola del par diferencial es de aproximadamente 1mA y no mayor (lo que permitiría mejorar, por ejemplo, la velocidad de crecimiento) para reducir los ruidos originados en la etapa.

#### Etapa de amplificación (VAS)

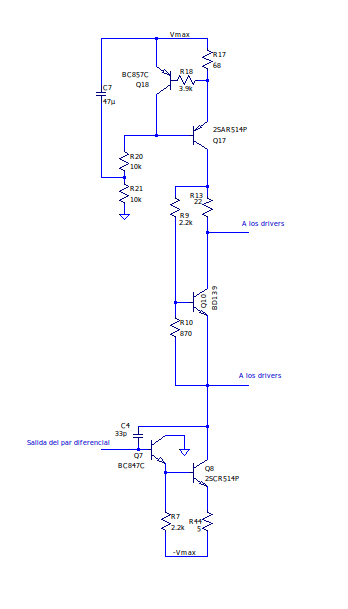
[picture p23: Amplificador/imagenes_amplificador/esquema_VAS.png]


Para esta etapa se eligió emisor común (Q7) seguido por un colector común (Q8) con carga activa (Q17). Esta configuración permite incrementar la ganancia a lazo abierto, ya que la relación entre la tensión  del nodo de salida de la VAS y la corriente de salida de la etapa diferencial es proporcional a la resistencia que ve esta última etapa hacia Q7. Entonces, la presencia de este último transistor, que incrementa dicha resistencia, logra aumentar la ganancia a lazo abierto. Además, esta configuración logra una baja alinealidad (frente una etapa sin un emisor común antecediendo al Q8, o sin tener carga activa) ya que consigue una alta ganancia de lazo en la realimentación negativa creada por C4.

#### Drivers

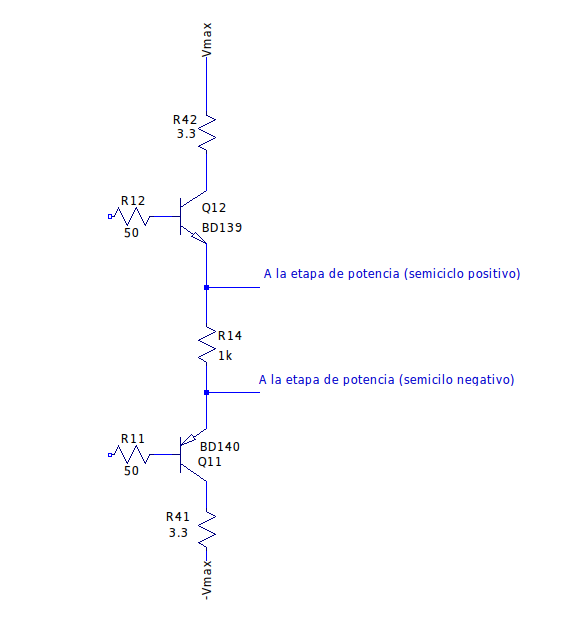
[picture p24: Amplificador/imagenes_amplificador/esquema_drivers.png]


Los drivers (Q11 y Q12)  poseen resistencias de base de 50ohm que permite reducir la variación de Vbe con la temperatura y protegen las bases de sobrepico de tensión, sin ser lo suficientemente grandes como para reducir la ganancia a lazo abierto por las caídas generadas por las corriente de base de Q11 y Q12.

#### Etapa de salida



Para la etapa de salida se eligió una clase H con los transistores de salida en paralelo. En esta configuración, dos llaves conmutan redirigiendo el camino de la señal a la base un transistor conectado a 12V en su colector o a otro conectado a 30V según la excursión de salida. De esta forma, se optimiza el consumo en señal ya que se logra que esta se dirija solamente a la base del transistor alimentado con 30V cuando se requiera una excursión de salida mayor a 12V aproximadamente.

Las llaves de conmutación fueron realizadas por medio de transistores MOSFET de baja resistencia Rds, que a diferencia de los TBJ posee un caída despreciable entre source y drain al activarse. Esto permite maximizar la excursión con los valores de alimentación disponibles y minimizar la disipación de potencia en las llaves. El circuito de comparación se realizó un transistor TBJ, que satura cuando se excede un valor de tensión ligeramente inferior a 12V, el cual está ajustado por el divisor resistivo que se encuentra en su base.

Los conmutadores emplean diodos rápidos 1N4148 para conseguir las diferencias de potencial Vgs suficientes (aproximadamente 2V) como para lograr que los transistores MOSFET conduzcan completamente.

Se eligió una salida paralelo ya que posee una máxima excursión mayor a la que brinda una salida serie. Esto se debe a que en esta última, la máxima excursión esta limitada por la saturación de 2 transistores. Estos, por la relación de corrientes entre su base y su colector requerida por la etapa de salida, saturan con una tensión Vce del orden de los 1,5V. En consecuencia, la máxima excursión obtenible con 30V de alimentación serían aproximadamente 27V (si considerar las caídas en resiistencias en el camino de la señal y la saturación/corte de otros transistores). Con una salida paralelo la limitación está impuesta por la saturación de un solo transistor, por lo que la máxima excursión ronda los 28,5V (con carga de 8ohm).

Los diodos Schottky D15 y D16 separan las alimentaciones de +12  y -12V respectivamente cuando los conmutadores comienzan a actuar, evitando un cortocircuito de las fuentes, y que los transistores U1 y U3 conduzcan equivocadamente cuando debieran encontrarse desactivados. Se han elegido diodos Schottky ya que su baja caída al encontrarse activados reduce la disipación de potencia.

Los resistores de degeneración de emisor de 0.1ohm fueron elegidos siguiendo la guía presentada por Douglas Self en la página 153 de "Audio Power Amplifier Handbook". Allí se realizaron mediciones que demuestran que para este valor, con transistores de salida de similares características a los empleados en este trabajo, la alinealidad es minimizada.

Una explicación del funcionamiento de los conmutadores se encuentra en el archivo [explicacion_conmutadores.md](explicacion_conmutadores.md).

## Subcircuitos

#### Fuente de corriente



La VAS cuenta con una fuente de corriente definida por Q18 y Q17 , la cual crea una corriente de polarización de la etapa de 9,5mA aproximadamente. El resistor R18 permite reducir las variaciones de dicha corriente con la temperatura, mientras que R20 y R21 polarizan a Q18.

R17 define el valor de la corriente de reposo de la VAS (9,5 mA) ya que esta es aproximadamente VbeQ18/R17. Además, la relación entre R17 y R19 define la corriente de cola del par diferencial.

El capacitor C7 logra reducir la PSNR del amplificador con respecto a +30V, ya que en señal funciona como un componentes de baja impedancia que hace que la base y el emisor de Q19 y Q17 aumenten y disminuyan a la par con las variaciones de +30V.

#### Filtros de ruido de las fuente alimentación



Se han incorporado filtros para reducir la PSNR. Esto son C9 y R6 para +30V y C5 y R8 para -30V. R6 y R8 valen 10ohm y no poseen un valor mayor (mejorando el filtro) debido a que limitarían la máxima excursión obtenible por la VAS, la cual, en esta topología, es el factor limitante de la máxima excursión de todo el amplificador. Para una mejor justificación de los valores de estos componentes ver [determinacion_valores_componentes.md](determinacion_valores_componentes.md)

#### Multiplicador de Vbe

El multiplicador de Vbe elegido ha sido uno de tipo convencional, donde se ha incorporado R13 para aumentar la linealidad de este bloque con la excursión. También se añadió C6 para eliminar el pico en altas frecuencias de la impedancia equivalente del multiplicador.

#### Ayudas de corriente de los conmutadores



Los transistores Q23 y Q24 actúan durante la conmutación, donde los transistores alimentados con +30V y -30V requieren de cargas en un corto intervalo de tiempo para polarizarse y transmitir señal. Dichas cargas que deben ser entregadas de forma rápida se traducen en picos de corriente que exceden los máximo permitidos por los drivers. En consecuencia Q23 y Q24 aportan parte de esta corriente para compartir los picos de corriente con los drivers y reducir el estrés que estos puedan sufrir.

#### Entrada bootstrap



El uso de resistores de pequeño valor para la realimentación (R22 y R23) con el fin de minimizar el ruido inducido por estos lleva a que se tenga una resistencia entrada muy baja si se desea que las base de Q1 y Q2 vean la misma resistencia para reducir las disparidades por las corrientes por las corrientes de base de reposo. En consecuencia, se ha incorporado un "bootstrap" a la entrada, constituido por C2 y C15 (este último para mejorar la respuesta en altas frecuencias por ser cerámico) y R24. Este se aprovecha de que la diferencia de tensiones entre las bases de Q1 y Q2 es muy pequeña, incrementando la resistencia que se ve desde R26. De este modo, se logra que la impedancia vista desde la entrada del amplificador sea aproximadamente la de la entrada del par diferencial.

#### Capacitor de la realimentación y sus protecciones

A la capacidad de la realimentación C3, que genera realimentación unitaria en continua, se le ha dado un valor de 1000u con el fin de que la frecuencia de corte inferior a lazo cerrado sea aproximadamente 1Hz. De esta forma, el giro de fase asociado a esta frecuencia de corte llega hasta los 10Hz, sin afectar la región de frecuencias audibles, que comienza en 20Hz. 

A este capacitor se le han colocado protecciones con diodos rápidos 1N4148 para anclar la tensión en el nodo compartido con R23 en caso de que haya un problema en el amplificador, el lazo de realimentación se corte, y hayan 30V o -30V en el nodo de salida (lo cual dañaría definitivamente al capacitor sin estar protegido).

#### Limitadores de corriente de salida



Compuestos por Q9 y Q22, evitan que la corriente y la tensión Vce de los transistores de potencia exceda la permitida por su SOA. La red de resistores conectada a la base de los transistores (R15, R16 y R37) para el caso de Q9 garantiza el límite de corriente admisible en función de la Vce de los transistores de salida.

Los limitadores obtienen información de las corrientes y de la Vce a partir de los resistores de degeneración de emisor de la etapa de salida R27 y R28.

Por otra parte, los diodos D21 y D22 evitar la activación indeseada de los limitadores de corriente basados en Q9 y Q22 respectivamente, durante el semiciclo de salida opuesto a aquel en el que circula señal por la rama que deben proteger. Por ejemplo, si se observa el limitador de Q9, se verá que para cualquier señal de salida la tensión Vbe de Q9 será siempre mayor que cero sin importar el semiciclo. Por otro lado, la tensión Vce de Q9 debiera ser negativa y no activarse durante el semiciclo negativo. Sin embargo, debido a la presencia del multiplicador de Vbe (que hace que la base de Q12 posea una tensión de más de 2V mayor a la de Q11), la tensión Vce de Q9 sin el diodo D21 sería positiva para parte del semiciclo negativo, y esto podría llevar a la activación de los transistores. El diodo incrementa entonces la diferencia de potencial que debe existir entre la base de Q12 y la salida para que el transistor Q9 se active. Todo lo explicado anteriormente aplica también para el limitador de corriente del semicilo negativo

Una caracterización de los limitadores de corriente puede encontrarse en  [Mediciones_parametros_simulacion.md](simulaciones_amplificador/Mediciones_parametros_simulacion.md).

*Limitador de corriente de la VAS*



A lo explicado anteriormente se debería sumar que el limitador de corriente en el semiciclo negativo no funcionaría si no fuera por el segundo limitador compuesto por Q25, R43 y R44. 

El funcionamiento del limitador de Q9 en el semiciclo positivo está fundamentado en el hecho de que, al conducir este transistor circula por su colector toda la corriente corriente disponible en la VAS para entregar al driver (aprox. 10mA). Por lo tanto, los drivers dejan de tener corriente para activar a los transistores de potencia y la excursión queda recortada. 

Por el contrario, en el semiciclo negativo, el transistor Q22 toma corriente de la salida, la cual puede ser absorbida por la VAS sin una limitación propia de esta etapa. Es entonces que el límite es impuesto por la red de Q25, R43 y R44. Cuando circula una corriente del orden de los 100mA por R44, se forma una diferencia de potencial en ella de modo de activar a Q25, quien le quita corriente a la entrada de la VAS, logrando limitar la excursión de salida.

Es entonces que la limitación de sobrecorriente en el semiciclo negativo depende de dos variables: 

- La corriente necesaria en R44 para activar a Q25 (la cual queda definida por el valor de R44)
- La corriente necesaria en la etapa de salida para que Q22 deje circular la corriente del item anterior. Cuanta corriente a la salida activará a Q22 está determinada por R38, R39 y R40.

R44 no puede tomar valores demasiado elevados ya que conduce a: reducir la ganancia de la VAS en señal; recortar la máxima excursión obtenible a la salida en un modo de funcionamiento normal. Tampoco puede ser demasiado baja ya que ello elevaría el umbral de activación de la limitación, al igual que haría que demasiada corriente circulase por la VAS (generando un daño en Q8) en el caso de un cortocircuito a la salida.

#### Protección contra DC en el nodo de salida



Su entrada se encuentra constituida por un filtro pasa bajos conformado por R46, C12 y C14, de forma que solamente se active la protección para la componente de DC o para frecuencias por debajo del rango audible. La componente de DC filtrada de dirige al nodo que conecta R45 con R47, activando a Q27 y Q28 si es negativa y  menor a aproximadamente  -900mV, o a Q26 si es positiva y mayor a aproximadamente 900mV. En cualquiera de los casos, esto coloca a tierra el nodo de base de M5, llevándolo a corte y desactivando el relé, que acto seguido desconecta la carga de la salida del amplificador.

Los resistores R45 y R46 limitan la corriente que circula por Q26 y Q27, así como la tensión en ese nodo (ya que la salida del amplificador, fuera de la operación normal, podría llegar a los +30V o -30V).

Una caracterización de la protección dee DC puede encontrarse en  [Mediciones_parametros_simulacion.md](simulaciones_amplificador/Mediciones_parametros_simulacion.md).

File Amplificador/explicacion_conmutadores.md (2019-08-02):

# Funcionamiento de los conmutadores
La finalidad de este documento es explicar el funcionamiento de los conmutadores de la etapa de salida del amplificador. Una introducción sobre su funcionamiento de encuentra en [descripcion_detallada_amplificador.md](descripcion_detallada_amplificador.md), pero aquí se muestra en detalle el proceso de conmutación.

A continuación se muestra el esquema del conmutador de la rama que funciona durante el semiciclo positivo:

 

El transistor Q20 tiene como finalidad comparar la tensión que se encuentra en su base y la del nodo de salida. Cuando la tensión del nodo de salida menos tres caídas de diodo (la tensión en el emisor de Q20) es mayor a la tensión en la base de Q20, entonces este satura y la tensión en su colector (el gate de M2) pasa a ser aproximadamente Vout - 2,1V. Se dice que la salida "menos tres caídas de diodo" debe ser mayor a la tensión en el nodo de base debido a que se tienen dos diodos 1N4148 entre el emisor y Vout (que totalizan aproximadamente 1,4V de caída) y, a su vez, la tensión base-emisor de Q20 debe ser aproximadamente -0,7V para que el transistor pueda saturar. 

Mientras Q20 no haya saturado, la tensión en el gate de M2 dependerá no de la salida, sino de aquella en el source de este transistor. Debido a que en este caso Q20 se encuentra en corte, no circula corriente por R30 y, por lo tanto, la tensión en el gate de Q20 es igual a la del source. Entonces, la tensigón Vgs de M2 es nula y este no conduce corriente. Debido a esto, la tensión en su source dependerá de la rama compuesta por -Vmax, R29, los diodos D3 y D4 y la salida. Como el amplificador se encuentra en el semiciclo positivo de salida (porque estamos tratando el conmutador de los transistores que actuan en este semiciclo), Vout es necesariamente mayor a -Vmax. de esta forma, circulará una corriente a través de los diodos y pasando por R29 hasta -Vmax. Además, U2 se encontrará en corte, ya que su tensión Vbe será menor a cero por la diferencia de potencial inducida por los diodos. Por otra parte, la tensión en el gate de M1 será la tensión del nodo de salida menos dos diodos (aproximadamente 1,4V). A su vez, suponiendo que U1 se encuentra conduciendo porque M1 está activado (que es lo que se desea cuando todavía Vout no ha superado el umbral de conmutación), la tensión en el nodo de salida será aproximadamente 0,7V menor a la del source de M1, ya que al estar este último conduciendo, su diferecia de potencial drain-source será aproximadamente nula y U1 induce una diferencia de potencial de aproximadamente 0,7V entre su base y su emisor (el nodo de salida) al conducir. Entonces, la tensión Vgs de M1 será de -2,1V, de forma que se asegura que este entrará en modo de conducción (como se lo había supuesto inicialmente).

El valor elegido para R29 depende de una relación de compromiso entre la corriente consumida por el conmutador (y la potencia disipada por este) cuando el amplificador se encuentra en reposo y la velocidad con la que pueden actuar los conmutadores. A menor valor de R29, mayor será la corriente por ella y mayor el consumo y disipasión en reposo del amplificador. Sin embargo, al forzarse más corriente por los diodos D3 y D4, la tensión entre estos será mayor, por lo que la tensión Vgs de M1 tenderá a ser mayor cuando se desee que este transistor conduzca, lo que acelerará la conmutación; y cuanto más rápida sea la conmutación, menor tenderá a ser la distorsión generada en la señal de salida. En base a esta relación de compromiso se adoptó R29=5kohm ya que garantiza los valores de distorsión deseados en las especificaciones, al igual que mantiene la disipación en ella por debajo de los 0,25W en reposo, y conseva el consumo de todo el amplificador en reposo por debajo de los 2W. 

Volviendo sobre el transistor Q20 que actua como comparador, cuando este sature porque la salida menos 2,1V haya sobrepasado la tensión en su base, la tensión en el gate de M2 será Vout - 2,1V. Suponiendo ahora que M2 y U2 conducen porque se ha producido la conmutación, se tiene que la tensión Vgs de M2 será -2,1V ya que su tensión de Vds es nula y recorriendo la malla desde el drain hasta el gate de M2 se tienen tres caídas de diodo (la Vbe de U2 y los dos diodos D5 y D6). Como la tensión Vgs es -2,1V, se comprueba que M2 debe conducir (y además habrá una corriente por R30). Además, como se supuso que U2 conduce, los diodos D3 y D4 no lo harán y puede establecerse el camino de señal que comunica los drivers con el nodo de salida a través de U2.

El valor de R30 establece cuanta corriente circulará desde el colector de Q20 al source de M2 cuando el comparador sature. Si esta corriente es muy baja, la corriente por los diodos D5 y D6 también lo será, de forma que, del mismo modo que para D3 y D4, la tensión de los diodos en directa no crecerá con la suficiente rapidez y se introducirá distorsión en la señal de salida. Si, en cambio, la corriente es muy alta, esta influye sobre la que circula por el canal de M2 hacia U2 y afecta considerablemente al camino de señal, introduciendo nuevamente distorsión. Por lo tanto, el punto adecuado para el valor de R30 se encuentra entre estos dos casos, y por simulación se llegó a que este se da para R30=1kohm. Por lo tanto, ese fue el valor que se le dió a esa resistencia.

Dado que cuando Q20 no se encuentra saturado está, en cambio, en corte y su base no conduce corriente, el divisor compuesto por R31 y R32 define el umbral que el comparador contrastará con la salida. Para los valores R31=1kohm y R32=2,7kohm, este umbral se encuentra en 9V aproximadamente. Si bien este valor es 3V menor a la tensión de alimentación inferior, la conmutación de los transistores M1 y M2 se completará para valores de excursión de salida mayores a 9V porque algunos componentes de los conmutadores (por ejemplo, lo diodos D5, D6) se polarizan totalmente para una excursión de salida algo mayor a la necesaria para que Q20 sature. Entonces, la activación/desactivación de los transistores U1 y U2 tendrá lugar para el rango de tensiones entre 11V y 12V de salida. En la siguiente imagen se muestran las corrientes de emisor de U1 (verde) y U2 (rojo) en función de la tensión de salida para una simulación realizada sobre los conmutadores:

 
 
Las corrientes son negativas ya que la referencia de las corrientes de emisor se considera entrante al terminal.

Por último, el diodo D8 protege la juntura base-emisor de Q20 de la ruptura cuando la salida se encuentra en el semiciclo negativo. D7, en cambio, ha sido colocado ya que se determinó por simulación que mejora la distorsión para amplitudes de salida de valores cercanos a los correspondientes a la potencial nominal sobre la carga.

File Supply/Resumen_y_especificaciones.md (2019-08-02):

# Diseño fuente de alimentación
---
En base a las especificaciones del diseño del amplificador clase G, se extraen especificaciones para la fuente de alimentación:

## Caracteristicas clase G:
* **Potencia:** 100W para 4Ω. De este valor se sabe que se exige a la fuente una tensión de 28V (RMS) y una corriente de 7A (RMS). La alimentación se puede lograr con las fuentes lineales disponibles en el laboratorio de electrónica de la FIUBA. Estas fuentes son capaces de 32V a 10A. Como la fuente es partida (+-28V), es necesario utilizar dos de estas fuentes. Entonces, el diseño a realizar es para la fuente de alimenteación de menor tensión del clase G. Esta fuente tiene que ser capaz de entregar una tensión menor, de aproximadamente 8V. Como este último valor no está fijado aún, la fuente debe ser capaz de ser ajustable de 3V hasta 15V aproximadamente. Entonces la corriente a entregar debe ser  de 15V/4Ω=3.75A. 
* **PSNR** Entendiendo que el diseño alimentará a un amplificador de audio, se busca que el ripple en la salida sea el menor posible, preferentemente menor de 50mV para la carga de 4Ω. 
* **Espacio** Se buscara lograr un diseño que ocupe poco espacio fisico, debiendo conseguir un alta eficiencia (>90%) para reducir el tamaño de los componentes disipativos.

A partir de las caracteristicas se opta por una fuente de tipo *switching* por los siguientes motivos:
* Eficiencia muy superior a fuentes lineales
* Menor tamaño debido a la utilización de dispositivos más chicos
* Alto rango de tensión de entrada y de salida

Sin embargo vale aclarar las siguientes desventajas:
* Mayor complejidad de diseño
* Mayor ruido a la salida
* Mayor costo
---
## Opciones de controladores switching
Luego de investigar la amplia oferta de controladores swithching por distintos fabricantes, se reduce las opciones a las ofertas de ***Linear Technology*** (actualmente Analog Devices). Este fabricante ofrece muchas opciones viables, hojas de datos bien documentadas (diseño de PCB, aplicaciones típicas) y modelos de *SPICE* de alta calidad (mejor proceso de simulación). La elección se realiza en base al catalogo  [*High Performance DC/DC Controllers*](https://www.analog.com/media/en/news-marketing-collateral/solutions-bulletins-brochures/linear_highperformancedc-dc_controllers_2015.pdf) .
Entre los parámetros a elegir para reducir las opciones, se prioriza:
* Salida única
* Corriente de salida máxima de 5A
* Tensión de entrada de al menos 32V
* Tensión de salida de al menos de 3V hasta 15V
* Encapsulado fácil de soldar: *SO*, *SSOP*, etc de bajo *count-pin*

Luego de evaluar las opciones, se elige el controlador *switching* ***LTC3864***.
### Caracteristicas LTC3864
* Controlador *BUCK*
* Salida positiva y negativa
* Vin de 3.5V a 60V
* Vout de 0.8 a Vin
* Frecuencia *switching* de 50kHz hasta 850Khz
* 12-MSOP
* Soft-start programable
* Protección de sobretensión
* Resistencia de sensado para protección por sobrecorriente
* Protección por tensión de entrada baja
* Eficiencia mayor al 90%

---
## Circuito
A partir del [datasheet](https://www.analog.com/media/en/technical-documentation/data-sheets/3864fa.pdf) se extrae la topología que funciona con las características requeridas:

Para la elección de los componentes se acude a la sección de diseño del *datasheet* (pag.10). El diseño se realiza en base a las siguientes especificaciones:
* Vin = 16V a 30V
* Vout = 15V
* Iout(max)=5A
* f=350kHz

La tensión de salida se programa como:



Por este motivo se elige RFB1=56K y RFB2=100K (variable). Entonces la tensión de salida es de 15.1V a 800mV.

El pin FREQ se une a masa para configurarlo en f=350Khz, aunque se deja la posibilidad de cambiar el valor con una resistencia serie.
Luego se selecciona el tamaño del inductor segun la siguiente fórmula:



Considerando un ripple máximo del 60% como peor caso se obtiene un valor de L1 de 7.1uH, el cual se lo lleva a 10uH ya que es un valor estandar. 
La corriente de ripple máxima es entonces:



Entonces ∆IL=2.7A.
Luego se selecciona Rsense para que el controlador pueda entregar la maxima corriente de 5A considerando márgen suficiente por la variacion de los componentes y considerando las peores condiciones de trabajo. Usando un márgen de error del 15% y con la siguiente fármula se obtiene que Rsense=13mΩ. La resistencia se lleva a Rsense=15mΩ por ser este último un valor comercial, se recalcula la corriente máxima y se obtiene Ilimite=5.3A.



El siguiente paso es hallar el transistor PMOS-FET correcto. Entre los parámetros que se deben considerar esta la tensión de ruptura BVDSs, corriente máxima de drain, la resistencia RDSon. Luego es necesario comprobar que la tensión V_DS que soporte el MOSFET sea mayor que la tensión de entrada del regulador. Por último hay que tener en cuenta la inductancia de los pines asociada con el *package* del MOSFET. La *datasheet* ofrece valores estandar, que se muestra a continuación:

| *Package* | Inductancia de pines |
| --- | --- |
| TO-220 | 4nH a 12nH |
| D2PAK | 4nH |
| DPAK | 1.5nH |
| SO-8 | 1nH |

Luego de examinar entre la basta oferta de transistores se optó por ***FDS4685***, cuyas características son:
* BVDSs = -40V
* ID = 8.2A continuo, 50A pulsado
* RDSon = 27mΩ
* Package: SO-8

La potencia disipada esperada se calcula como:

Como capacitancia se eligió una combinación de capacitor electrolítico y cerámico, en paralelo. Para la capacitancia de salida se utiliza el mismo diseño. En este caso, se observa que es vital la ESR del capacitor equivalente ya que definirá el ripple de la tensión de salida:



Luego de realizar cálculos y simulaciones se llegó a que la mejor opción son dos capacitores electrolíticos de 47uF y uno cerámico. Si bien se sabe que el valor del ESR del cerámico es mucho más bajo, para elegir el valor de la capacitancia que debe tener dicho capacitor se investigó y se halló un [sitio](https://www.powerelectronictips.com/how-mixed-type-output-capacitors-affect-dcdc-converter-stability/) que investigo esta relación. Del mismo se extrae que la capacitancia del cerámico, para que se observe el fenómeno de baja del ripple de salida, debe ser de al menos del 20%, como se observa en el siguiente gráfico:


Por eso es que se opta por un capacitor cerámico de 22uf.
El controlador permite un arranque suave proporcional al capacitor conectado al pin SS (*soft-start*):



Se elige un capacitor de 10nF, teniendo una arranque suave de aproximadamente 1 mS.
Luego se realiza un divisor resistivo de la tensión de alimentación, unido al pin RUN, el cual se utiliza como protección por tensión baja.

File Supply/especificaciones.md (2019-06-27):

# Diseño fuente de alimentación
---
En base a las especificaciones del diseño del amplificador clase G, se extraen especificaciones para la fuente de alimentación:

## Caracteristicas clase G:
* **Potencia:** 100W para 4 ohm. De este valor se sabe que se exige a la fuente una tensión de 28V (RMS) y una corriente de 7A (RMS). La alimentación se puede lograr con las fuentes lineales disponibles en el laboratorio de electrónica de la FIUBA. Estas fuentes son capaces de 32V a 10A. Como la fuente es partida (+-28V), es necesario utilizar dos de estas fuentes. Entonces, el diseño a realizar es para la fuente de alimenteación de menor tensión del clase G. Esta fuente tiene que ser capaz de entregar una tensión menor, de aproximadamente 8V. Como este último valor no está fijado aún, la fuente debe ser capaz de ser ajustable de 3V hasta 15V aproximadamente. Entonces la corriente a entregar debe ser  de 15V/4Ω=3.75A. 
* **PSNR** Entendiendo que el diseño alimentará a un amplificador de audio, se busca que el ripple en la salida sea el menor posible, preferentemente menor de 50mV para la carga de 4ohm. 
* **Espacio** Se buscara lograr un diseño que ocupe poco espacio fisico, debiendo conseguir un alta eficiencia (>90%) para reducir el tamaño de los componentes disipativos.

A partir de las caracteristicas se opta por una fuente de tipo *switching* por los siguientes motivos:
* Eficiencia muy superior a fuentes lineales
* Menor tamaño debido a la utilización de dispositivos más chicos
* Alto rango de tensión de entrada y de salida

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

Luego de evaluar las opciones, se elige el controlador *switching* ***LTC3864***.
### Caracteristicas LTC3864
* Controlador *BUCK*
* Salida positiva y negativa
* Vin de 3.5V a 60V
* Vout de 0.8 a Vin
* Frecuencia *switching* de 50kHz hasta 850Khz
* 12-MSOP
* Soft-start programable
* Protección de sobretensión
* Resistencia de sensado para protección por sobrecorriente
* Protección por tensión de entrada baja
* Eficiencia mayor al 90%

---
## Circuito
A partir del [datasheet](https://www.analog.com/media/en/technical-documentation/data-sheets/3864fa.pdf) se extrae la topología que funciona con las características requeridas:

Para la elección de los componentes se acude a la sección de diseño del *datasheet* (pag.10). El diseño se realiza en base a las siguientes especificaciones:
* Vin = 16V a 30V
* Vout = 15V
* Iout(max)=5A
* f=350kHz

La tension de salida se programa como:

Por este motivo se elige RFB1=56K y RFB2=100K (variable). Entonces la tensión de salida es de 15.1V a 800mV.

El pin FREQ se une a masa para configurarlo en f=350Khz, aunque se deja la posibilidad de cambiar el valor con una resistencia serie.
Luego se selecciona el tamano del inductor segun la siguiente formula:

Considerando un ripple maximo del 60% como peor caso se obtiene un valor de L1 de 7.1uH, el cual se lo lleva a 10uH ya que es un valor estandar. 
La corriente de ripple maxima es entonces:

Entonces ∆IL=2.7A.
Luego se selecciona Rsense para que el controlador pueda entregar la maxima corriente de 5A considerando margen suficiente por la variacion de los componentes y considerando las peores condiciones de trabajo. Usando un margen de error del 15% y con la siguiente formula se obtiene que Rsense=13mΩ. La resistencia se lleva a Rsense=15mΩ por ser este ultimo un valor comercial, se recalcula la corriente maxima y se obtiene Ilimite=5.3A.

El siguiente paso es hallar el transistor PMOS-FET correcto. Entre los parametros que se deben considerar esta la tension de ruptura BVDSs, corriente maxima de drain, la resistencia RDSon. Luego es necesario comprobar que la tension V_DS que soporte el MOSFET sea mayor que la tensión de entrada del regulador. Por último hay que tener en cuenta la inductancia de los pines asociada con el *package* del MOSFET. La *datasheet* ofrece valores estandar, que se muestra a continuación:

| *Package* | Inductancia de pines |
| --- | --- |
| TO-220 | 4nH a 12nH |
| D2PAK | 4nH |
| DPAK | 1.5nH |
| SO-8 | 1nH |
 Luego de examinar entre la basta oferta de transistores se opto por ***FDS4685***, cuyas caracterisiticas son:
* BVDSs = -40V
* ID = 8.2A continuo, 50A pulsado
* RDSon = 27mΩ
* S0-8 Package

La potencia disipada esperada se calcula como:

Como capacitancia se eligió una combinación de capacitor electrolítico y cerámico, en paralelo. Para la capacitancia de salida se utiliza el mismo diseño. En este caso, se observa que es vital la ESR del capacitor equivalente ya que definirá el ripple de la tensión de salida:

Luego de realizar cálculos y simulaciones se llegó a que la mejor opción son dos capacitores electrolíticos de 47uF y uno cerámico. Si bien se sabe que el valor del ESR del cerámico es mucho más bajo, para elegir el valor de la capacitancia que debe tener dicho capacitor se investigó y se halló un [sitio](https://www.powerelectronictips.com/how-mixed-type-output-capacitors-affect-dcdc-converter-stability/) que investigo esta relación. Del mismo se extrae que la capacitancia del cerámico, para que se observe el fenómeno de baja del ripple de salida, debe ser de al menos del 20%, como se observa en el siguiente gráfico:

Por eso es que se opta por un capacitor cerámico de 22uf.
El controlador permite un arranque suave proporcional al capacitor conectado al pin SS (*soft-start*):

Se elige un capacitor de 10nF.
Luego se realiza un divisor resistivo de la tensión de alimentación, unido al pin RUN, el cual se utiliza como protección por tensión baja.

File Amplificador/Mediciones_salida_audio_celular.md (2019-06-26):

## Mediciones de la tensión pico de salida de un celular a máximo volumen

Las siguientes mediciones fueron realizadas con el fin de determinar la ganancia a lazo cerrado del amplificador partiendo de la especificación de una tensión de alimentación máxima de 30V (habiendo entonces una excursión máxima de 28V aproximadamente). Si bien se consultaron fuentes que se pueden ver en el archivo [referencias.md](../DOC/Referencias.md).

Se realizaron mediciones con dos modelos distintos de celular:

1. Samsung Galaxy Note 4
2. Motorola Moto G7 Plus

Realizaron pruebas reproduciendo tonos de distintas frecuencias al volumen máximo que permitía el terminal.

Las mediciones se realizaron con osciloscopio conectando plug a la salida de 3.5mm del celular y luego conectando una resistencia de 47kOhm de carbón (tolerancia 5%) entre la masa del conector y una de la señales (izquierda o derecha). El conexionado fue realizado en una "protoboard".

Mediciones realizadas con osciloscopio Atten ADS1102CAL+. Configuración: Promedio X4, filtro pasabajos de 20MHz. Amplitud del ruido ruido medido al no aplicar señal 8 Vpico_pico.

##### Samsung Galaxy Note 4

Impedancia de salida medida entre uno de los terminales de señal y masa del plug: 200ohm. Medición realizada con multímetro UNI-T UT33A.

| Frecuencia | Tensión pico a pico |
| --- | --- |
| 40 Hz | 1.05 V |
| 50 Hz | 1.24 V |
| 1 kHz | 1.2 V |

Las mediciones con 50Hz y 1kHz se llevaron a cabo reproduciendo un tono de 0dB, el cual se debiera traducirse en 1Vrms = 1.41V (pico) a la salida. Sin embargo, se midieron valores menores de aproximadamente 1.2V pico_pico, es decir, 0.6Vpico. Por lo tanto, se estima que el límite de amplitud de tensión a la salida de este celular se encuentra en ese valor.

##### Motorola Moto G7 Plus

| Frecuencia | Tensión pico a pico |
| --- | --- |
| 50 Hz | 2.9 |
| 1 kHz | 2.6 |

El tono de 50 Hz se correspondió con el mismo armónico de 0dB que se utilizó para medir con el Samsung Galaxy Note 4. En este caso, se obtuvo una salida de 2.9 Vpico_pico , es decir, 1.45 Vpico = 1Vrms. Entonces, para este dispositivo se logró obtener efectivamente la tensión esperada para un señal de 0dB. 

A continuación se muestra una captura del osciloscopio de la señal medida para la armónica de 50Hz.



##### Conclusiones

Si bien podrían haberse llevado a cabo un mayor número de mediciones con más modelos distintos de celular, a lo que las realizadas no garantizar que 1Vrms sea efectivamente el mayor valor obtenible a la salida en un celular; ante la imposibilidad de encontrar documentación/estándares de los cuales obtener un valor exacto de dicha tensión, se decidió adoptar el mayor valor obtenido en estás mediciones. En consecuencia, se determinó la ganancia del amplificador suponiendo que la señal máxima de salida de jack 3.5mm de un celular es una amplitud de 1Vrms.

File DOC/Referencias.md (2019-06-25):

## Referencias

1. D. Self. "Audio Power Amplifier Design Handbook", 4ta edición. Newnes, 2006
2. P.R. Gray,  R.G. Meyer. "Analysis and Design of Analog Integrated Circuits", 5ta edición. Wiley, 2009.
3. F. H. Raab. "Average efficiency of Class-G power amplifiers".  IEEE Transactions on Consumer Electronics, vol. CE-32, no. 2, p. 145-150, 1986.
4. T. Sampei, S. Ohashi, Y. Ohta and S. Inoue, "Highest Efficiency and Super Quality Audio Amplifier using MOS Power FETS in Class G Operation," IEEE Transactions on Consumer Electronics, vol. CE-24, no. 3, p. 300-307, 1978.
5. E. Winer, "The Audio Expert: Everything You Need to Know About Audio". Elsiever, 2012.
6. R. Elliott. "Class-G Amplifiers". 2009. Disponible en: <http://sound.whsites.net/articles/class-g.htm>. Accedido: 25/6/19
7. "Understanding Audio Levels", Geoff the Grey Geek. Disponible en: https://geoffthegreygeek.com/audio-levels/. Accedido: 25/6/19
8. "Commonly used Voltage and Audio Levels". Disponible en: <https://www.kfs.oeaw.ac.at/manual/3.8/html/userguide/461.htm>. Accedido: 25/6/19.
9. B. Mak. "Basics of Load Switches", Application Report, Texas Instruments, 2009.
10. "Features of the AAT4285 12V Slew Rate Controlled Load Switch", Application Note, Skyworks, 2012.
11. "Using MOSFETs in Load Switch Applications". Application Note, On Semiconductor, 2014.

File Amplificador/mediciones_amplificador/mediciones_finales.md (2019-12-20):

## Mediciones finales del amplificador
En este archivo se incluyen las mediciones finales llevadas a cabo para caracterizar el amplificador.

#### Polarización
Se midieron las corrientes y tensiones de polarización con su respectivo error. Dichas mediciones fueron realizadas con un multímetro Proskit MT-1707 con una incertidumbre de 0,5% + 3 dígitos para las mediciones de tensión continua y 0,5% + 3 dígitos para las de alterna. 

###### Corrientes
| Referencia | Teórico [mA] | Simulado [mA] | Medido [mA] | Error del valor medido [mA] |
| ---- | ---- | ---- | ---- | ---- |
| Ivas/Icq17  | 10,2 | 9,5 | 9 | 0,05 |
| Icola/Icq19 | 1 | 0,98 | 0,87 | 0,005 |
| Icq1 | 0,5 | 0,49 | 0,43 | 0,005 |
| Icq2 | 0,5 | 0,49 | 0,43 | 0,005 |
| Icq3 | 0,5 | 0,49 | 0,37 | 0,006 |
| Icq4 | 0,5 | 0,48 | 0,41 | 0,006 |
| Icq18 | 1,4 | 1,4 | 1,44 | 0,009 |
| Ieq7 | 0,3 | 0,34 | 0,30 | 0,003 |
| Ir14 | 1 | 1,1 | 1,08 | 0,009 |
| IcU1 | 10 | 9,4 | 20 | 0,2  |
| IcU3 | 10 | 9,4 | 20 | 0,2 |

###### Tensiones
| Referencia | Teórico [V] | Simulado [V] | Medido [mA] | Error del valor medido [mA] |
| ---- | ---- | ---- | ---- | ---- |
| Vo | 0 | 0,2m | 0,3m |  |
| VbeQ18 | -0,7 | -0,64 | -0,61 | 0,003 |
| VbeQ17 | -0,7 | -0,62 | -0,56 | 0,003 |
| VbeQ19 | -0,7 | -0,6 | -0,57 | 0,003 |
| VbeQ7 | 0,7 | 0,59 | 0,56 | 0,003 |
| VbeQ8 | 0,7 | 0,63 | 0,58 | 0,003 |
| VbeQ10 | 0,7 | 0,63 | 0,61 | 0,003 |
| VbeQ12 | 0,65 | 0,57 | 0,55 | 0,003 |
| VbeQ11 | -0,65 | -0,57 | 0,57 | 0,003 |
| VbeU1 | 0,5 | 0,56 | 0,54 | 0,003 |
| VbeU3 | -0,5 | -0,54 | -0,54 | 0,003 |

#### Potencia máxima de salida
Se introdujo una señal armónica de 1kHz a la entrada del amplificador y se la aumentó hasta observar en el osciloscopio que la señal de salida sufriera un achatamiento producto de una limitación en la excursión. 
La tensión pico fue medida con un tester Proskit MT1707 de incertidumbre 0.8% + 3 dígitos. 
Esto ocurrió para:

 

Por lo tanto, la potencia máxima obenible sobre una carga de 8ohm s:

 

A continuación se muestra una captura de la meódicin de la potencia máxima obtenible sobre la carga:

 

#### Sensibilidad
Se buscó hallar la tensión de entrada tal que se obtuviera la potencia nominal especificada para una carga de 8ohm. Siendo la potencia nominal igual a 45W, la tensión de entrada obtenida para conseguir dicha potencia fue de:

 

Este valor fue medido con un osciloscopio RIGOL DS1302CA.

Dicho valor transformado a valor eficaz implica que:

 

#### Distorsión armónica
Esta medición fue realizada utilizando el programa SpectraPLUS-RT para PC. Se generó una señal de salida desde el "line out" de la PC, la cual fue introducida a la entrada del amplificador por medio de un cable hallado con conectores de 3.5mm. Por otra parte, se hizo pasar a la señal de salida del amplificador a través de un divisor resistivo variable generado con un _preset_, el cual permitía que las amplitudes de salida de hasta 28V pudieran ser dirigidas a la entrada "line in" de la PC, con el fin de que la distorsión de las señales fuera calculada por el programa SpectraPLUS.

Las mediciones se realizaron con una carga de 8ohm en el amplificador.

Con una armónica de 1kHz:

| Porcentaje de la potencia máxima | Distorsión |
| ---- | --- |
| 10% | 0,009% |
| 50% | 0,020% |
| 90% | 0,024% |

Con una armónica de 10kHz:

| Porcentaje de la potencia máxima | Distorsión |
| ---- | --- |
| 10% | 0,023% |
| 50% | 0,032% |
| 90% | 0,030% |

El piso de distorsión medido con SpectraPLUS-RT conectando el line out de la PC a su propio line in fue de 0,006%.

#### Linealidad
Se midió la variación de ganancia del amplificador con la amplitud de la señal de entrada para una frecuencia fija de 1kHz. Las mediciones fueron realizadas con una carga de 8ohm.

La tensiones fueron medidas con un tester Proskit MT1707 de incertidumbre 0.8% + 3 dígitos. 

A continuación de muestra una tabla con los resultados 

| Vin[V] | Vo[V] | Ganancia |
| ---- | --- | --- |
| 0,033 | 0,778 | 23,56 |
| 0,168 |  3,8534 | 22,94 |
| 0,338 |  7,778 |  23,01 |
| 0,506 |11,625 |  22,97 |
| 0,672 |  15,449 | 22,99 |

#### Ancho de banda
Se conectó una señal a la entrada del amplificador y se fue variando su frecuencia para observar el cambio en la ganancia. La medición fue realizada con una carga de 8ohm conectada a la salida.
Las mediciones se realizaron con un osciloscopio RIGOL1302CA de 300MHz de ancho de banda.

Los resultados se muestran en la tabla a continuación:

| Frecuencia[Hz] | Vout[V] | Vin[mV] | Ganancia |
| ---- | --- | --- | ---- |
| 2 | 1,1 | 60 | 18,3  |
| 20 | 1,1 | 58 | 19 |
| 200 | 1,1 | 55 | 20 |
| 500 | 1,1 | 55 | 20 |
| 600 | 1,1 | 55 | 20 |
| 1k | 1,1 | 57 | 20 |
| 2k | 1,1 | 55 | 20 |
| 5k | 1,1 | 55 | 20 |
| 10k | 1,1 | 55 | 20 |
| 15k | 1,1 | 55 | 20 |
| 20k | 1,1 | 55 | 20 |
| 30k | 1,1 | 55 | 20 |
| 50k | 1,1 | 46 | 24 |
| 100k | 1,2 | 58 | 21 |
| 200k | 1,4 | 86 | 16 |

Por otra parte, se buscaron las frecuencias de corte inferior y superior observando los puntos donde se producía un desfase de 45° entre la señal de entrada y la de salida. Ambas mediciones se hicieron con el modo de captura del osciloscopio como promediador de 32 muestras.

Por último, la ganancia resultó ser aproximadamente de 20 para estas mediciones, lo que la hace menor a los valores medidos para linealidad y los estimados teóricamente y por simulación, aunque aproximadamente constante a lo largo del todo el ancho de banda. Se atribuye esto a un error sistemático de medición, que aun así permite conocer el alcance del ancho de banda del amplificador.

##### Frecuencia de corte baja
No se llegó a observar la frecuencia de corte inferior debido a que el relé de la protección contra DC actuaba y desconectaba a la carga del amplificador. Sin embargo, se llegó a observar que a 2Hz todavía no se producía la rotación de fase de 45°. Esto es suficiente como para afirma que la frecuencia de corte inferior se halla por debajo de los 20Hz, que es lo que se desea.

Foto de la pantalla del osciloscopio con una señal de 2Hz:

 

##### Frecuencia de corte alta
Dado que conseguir amplitudes menores con el generador de entrada no era posible, para frecuencias mayores a los 200kHz se comenzó a notar el efecto del slew rate. Es por esto que resultó dificil observar la frecuencia donde se daba el desfase de 45° con claridad. Sin embargo, esta se estimó en 550kHz, según como se ve en la imagen:

 

En la tabla agregada más arriba en esta sección se han removido los casos mayores a 200kHz debido a que la deformación en la señal de salida impedía obtener valores coeherentes de ganancia.

#### Slew rate
Se colocó una señal cuadrada a la entrada del amplificador y se observó la señal de salida. Debido a que el ancho de banda de potencia se encuentra limitado por el slew rate, por encima de cierta frecuencia de la cuadrada (con una amplitud lo suficientemente grande) se podrá ver que su pendiente a la salida es constante y de un valor que permite conocer el slew rate.

Las mediciones se realizaron con una carga de 8ohm y una señal de entrada de 20kHz. El osciloscopio empleado fue un RIGOL1302CA de 300MHz de ancho de banda.

Para una amplitud de entrada de 300mVpp (de forma que el amplificador no comutase) se obtuvieron los iguientes valores de slew rate:

-  
-  

Medicion del SR+ sin conmutar:
 

 

Medicion del SR- sin conmutar:
 

 

Y con una amplitud de entrada de 1,85Vpp (de modo que el amplificador sí conmutase):

-  
-  

Medicion del SR+ conmutando:
 

 

Medicion del SR- sin conmutando:
 

 

En las imágenes se ve que la conmutación complica la adopción de un criterio para definir cual es el slew rate. Es por esto que resulta complicado adoptar un criterio para determinar la incertidumbre de la medición, por lo que se interpreta a los valores obtenidos solamente como una aproximación al verdadero valor del _slew rate_.

#### Ancho de banda de potencia
De los valores medidos del slew rate se extrae, por el mismo método que el utilizado en los cálculos teóricos del amplificador, que el ancho de anda de resolución en conmutación y fuera de conmutación es:

- Sin conmutación:  
- En conmutación:  

Donde para cada caso se ha utilizado el peor _slew rate_, que en ambos resultó ser el del flanco ascendente. Además, se ha aproximado a la excursión máxima del amplificador como de 30V (aunque se ha concluido de las mediciones que esta no supera los 28V).

Notar que para el ancho de banda de potencia en conmutación no se ha reportado una incertidumbre por el hecho de que tampoco pudo hacérselo con seguridad en el apartado de SR. Finalmente, la incertidumbre para el caso sin conmutación resulta ser elevada y se deriva de la propagación de errores que se realizó. Sin embargo, dado que se llevaron a cabo varias mediciones del slew rate a lo largo del armado y puesta a prueba del amplificador, se confía en que el ancho de banda de potencia sea mayor a 40kHz.

#### Impedancia de entrada
Para medir la impedancia de entrada (que en adelante trataremos como resistencia de entrada debido a que se supondrá para los cálculos que esta es real) del amplificador se conectó en serie entre el generador de señal y la entrada en sí una resistencia de 9,9kohm como se muestra en la siguiente imagen:

 

Se utilizó dicho valor de resistencia ya que se encuentra en el mismo orden de magnitud que se espera que tenga la resistencia de entrada.

Colocando una armónica dentro del rango de frecuencias audibles como señal de entrada y comparando su valor pico o RMS con el de la misma armónica observada en el nodo entre la entrada del amplificador y la resistencia de 9,9kohm es posible despejar el valor de la resistencia de entrada de la siguiente forma:

 

La mediciones de las tensiones se realizaron con un multímetro Proskit MT1707 True RMS con una incertidumbre de 0.8% + 3 dígitos. A continuación se muestra una tabla con la resistencia de entrada medida entre 100Hz y 20kHz. No se logró alcanzar valores más bajos en frecuencia debido a que el generador experimentaba problemas para proveer una amplitud constante.

E(X) representa la incertidumbre del parámetro X.

| Frecuencia[Hz] | Vin[mV] |  E[Vin][mV] | Vn[mV] | E[Vn][mV] | Rin[kohm] | E(Rin)[kohm] |
| ---- | --- | ---- | --- | ---- | --- | ---- |
| 100 | 103 | 2 | 76 | 2 | 27 | 5 |
| 200 | 101 | 2 | 77 | 2 | 34 | 5 |
| 300 | 101 | 2 | 76 | 2 | 30 | 5 |
| 400 | 101 | 2 | 74 | 2 | 27 | 5 |
| 500 | 100 | 2 | 73 | 2 | 26 | 5 |
| 1k | 96 | 2 | 69 | 2 | 25 | 5 |
| 2k | 102 | 2 | 73 | 2 | 25 | 5 |
| 3k | 100 | 2 | 70 | 2 | 23 | 5 |
| 5k | 103 | 2 | 73 | 2 | 24 | 5 |
| 8k | 103 | 2 | 73 | 2 | 24 | 5 |
| 10k | 103 | 2 | 73 | 2 | 24 | 5 |
| 15k | 103 | 2 | 72 | 2 | 23 | 5 |
| 18k | 103 | 2 | 73 | 2 | 23 | 5 |
| 20k | 102 | 2 | 71 | 2 | 22 | 5 |

Se ve que la incertidumbre en las mediciones es grande producto de la cancelación que se da en el denominador de la expresión que se mostró anteriormente para realizar los cálculos.

#### Impedancia de salida

La medición de la impedancia de salida del amplificador consistió en suponer que este se comporta a su salida como el siguiente equivalente:



Donde Vg es función de señal de entrada del amplificador y Zo es su impedancia de impedancia de salida, la cual se desea hallar. En la imagen se han incluido resistencias para representar a las impedancias ya que para la medición se asumirá que estas son reales.  Al colocar una carga ZL se obtiene la situación:



Donde la tensión de salida Vo queda expresada por el divisor de tensión:



Y de allí puede despejarse la impedancia de salida como:



Colocando una señal armónica de entrada de amplitud determinada en el amplificador y dejando abierta su salida (sin carga), en el nodo de salida se mide tensión Vg (para esa dada tensión de entrada) ya que no hay corriente por la malla de la primera figura. Luego, con la misma señal de entrada del amplificador y colocando una carga ZL de forma de cerrar la malla en el nodo de salida se mide la tensión Vo para esa dada carga. Asumiendo que Vg se mantuvo igual para el segundo caso, se puede despejar Zo de la segunda ecuación. Para esta medición se supuso, además, que la impedancia de salida del amplificador es real.

Las condiciones de la medición fueron:

- Amplitud de entrada del amplificador 100mV
- Frecuencia de la señal de entrada: 100Hz, 1kHz, 10kHz.
- Carga de 8,6 ohm medida con multímetro Proskit MT1707. La incertidumbre del multímetro para esta medición es de 0.8% + 3 dígitos, entonces:



El instrumento utilizado para medir las tensiones fue un adquisidor de datos Agilent 34970A  y se midieron tensiones RMS. Los resultados fueron, sin considerar en un principio sus incertidumbres:

| Frecuencia [Hz] | V_open [V] | V_load [V] | Zo [ohm] |
|---|---|---|---|
| 100 | 1,536 | 1,533 | 0,017 |
| 1000 | 1,54 | 1,538 | 0,011 |
| 10000 | 1,535 | 1,533 | 0,011 |

#### Factor de amortiguamiento

El factor de amortiguamiento viene dado por:



Con los valores medios de la impedancia de salida obtenidos en el apartado anterior se llega a los siguientes valores medios del factor de amortiguamiento para una carga de 8ohm:

| Frecuencia [Hz] |F_amort_med |
| ---- | --- |
| 100 | 471 |
| 1000 | 727 |
| 10000 | 727 |

#### Overshoot de respuesta al escalón
Se introdujo una señal cuadrada a la entrada del amplificador tal que a la salida se produjeran escalones de 2V aproximadamente con el fin de observar el overshoot y el ringing ocasionados. A continuación se muestra una captura de la medición:

 

En la imagen se observa que el sobrepico es de 200mV aproximadamente, lo que denota un overshoot del 10%. A su vez, se llega a observar un poco más de un ciclo y medio de oscilación (ringing) sobre la cuadrada. Esto lleva a concluir que el margen de fase se ha de encontrar cercano a 60° pero algo menor, ya que dicha condición exige un overshoot del 10% y un solo ciclo completo de oscilación.

#### Eficiencia
Se conectaron multimetros en modo amperímetro en la salida de las fuentes de +30V y +12V, mientras que se midió la amplitud RMS de salida con un osciloscopio. De esta forma, variando la amplitud de salida se fue relevando la eficiencia para distintos valores de excursión.
La potencia entregada por cada fuente de puede calcular como:

 

Y la potencia entregada a la carga se calcula como:

 

Teniendo en cuenta que hay dos fuentes de cada valor de tensión (una positiva y otra negativa), y asumiendo que ambas entregan la misma corriente, se tiene que la potencia total entregada por todas las fuentes es:

![](https://latex.codecogs.com/gif.latex?P_{total}&space;=&space;2&space;\times&space;(12V&space;\times&space;I_{avg&space;\&space;12V}&space;&plus;&space;30V&space;\times&space;I_{avg&space;\&space;30V})) 

Y la eficiencia se calculó finalmente como:

 

A continuación se muestran fotos del banco de trabajo con los dos multímetros:

 

 

Finalmente, los valores relevados fueron:

| V_carga_rms [V] | I_avg_12V [A] | I_avg_30V [A] | P_fuentes [W] | E(P_fuentes) [W] | Eficiencia |
| ---- | --- | --- | --- | --- | --- |
| 3,0 | 0,08 | 0,03 | 3,7 | 1 | 26% |
| 4,0 | 0,10 | 0,03 | 4,2 | 1 | 41% |
| 5,0 | 0,12 | 0,03 | 4,7 | 1 | 57% |
| 6,5 | 0,32 | 0,03 | 5,4 | 1 | 56%  |
| 7,0 | 0,34 | 0,03 | 5,6 | 1 | 55% |
| 8,3 | 0,10 | 0,21 | 15,0 | 3 | 49% |
| 10,0 | 0,08 | 0,33 | 21,7 | 3 | 49% |
| 11,1 | 0,08 | 0,40 | 25,9 | 3 | 51% |
| 14,8 | 0,06 | 0,60 | 37,4 | 3 | 63% |
| 17,2 | 0,05 | 0,73 | 45,2 | 3 | 70% |
| 19,0 | 0,05 | 0,81 | 49,8 | 3 | 77% |

La carga para todas las mediciones fue de 9,3ohm.
E(x) representa la incertidumbre del parámetro X.

Y el gráfico asociado a la tabla es el siguiente:


Para las mediciones donde la tensión RMS sobre la carga era 6,5 y 7V se midió la corriente utilizando el display de la fuente de la laboratorio (UNI-T  UTP3315TFL) ya que los multímetros reportaban valores medios de corriente que derivaban en que la eficiencia calculada fuera superior al 80% y 90% en cada caso respectivamente; lo que no tenía sentido ya que la eficiencia máxima que se puede alcanzar en un clase B (que es como se comporta el amplificador al no estar conmutando, como con 6,5V y 7V RMS a la salida) es 78%. El hecho de utilizar el display de la fuente incrementó considerablemente la incertidumbre. Sin embargo, da una noción de como la eficiencia del amplificador aumenta a medida que la amplitud de salida se acerca hacia el umbral de conmutación (carca de 7V RMS), para luego disminuir por la activación de las fuente de 30V. A continuación, a medida que se sigue aumentando la tensión de salida, la eficiencia vuelve a aumentar, ya que la corriente que proveen las fuentes de 12V comienza a ser despreciable frente a las de 30V, y la eficiencia se comienza a asemejar a la de un clase B nuevamente.

Se ve que la eficiencia máxima que alcanza el amplificador es 77%, ocurriendo para la máxima excursión de salida como es de esperarse.

La eficiencia por debajo de la conmutación resulta ser menor al 60%, lo cual no es de esperarse dado que en este modo de operacaión el amplificador se asemeja a un clase B. Dos aspectos que podrían haber afectado son, la incertidumbre mencionada anteriormente para este rango de excursión, y la corriente consumida por el circuito de relé, la cual llega hasta 30mA aproxidamente.

Finalmente, para todas las mediciones de corriente mayores a 0,1A se asumió que la incertidumbre de las mediciones era de 0,05A producto de las incertidumbre de utilizar la escala de 10A del los multímetros. Para menores valores de corriente se despreció la incertidumbre porque predominaba la de la corriente de la otra fuente. Con este criterio se calculó la incertidumbre de la potencia provista por las fuentes.

#### PSNR
Para la medir la PSNR del amplificador se utilizò la documentación recomendada: [Medición de Rechazo de Ruido de la Fuente](mediciones_finales/Medición_de_Rechazo_de_Ruido_de_la_Fuente.pdf). La idea es colocar un generador de _ripple_ y sumarlo a la alimentación positiva del amplificador. El circuito se observa a continuación:
 
De esta manera se tiene una alimentación de +30V con rizado. 
En la siguiente figura se observa el resultado de la medición:
 
Ambos canales son acoplados en alterna. La amplitud de rizado máxima lograda es de 1Vpp a 10Hz, debido a los capacitores de _bypass_ del circuito del amplificador.  Debido a esto, la amplitud en la salida es de menos de 1mVpp. El rango minimo del oscilloscopio usado (Siglent SDS 1102CML) es de 2mV. Por ende, el valor calculado cuanta con mucha dispersión, pero sirve para marcar una cota. 
Según lo medido, se calcula la PSNR como:

Con esto se obtiene:

Esto es màs bien una cota inferior de la PSNR, ya que con mejores instrumentos se podría medir con mas detalle el valor del _ripple_ a la salida.

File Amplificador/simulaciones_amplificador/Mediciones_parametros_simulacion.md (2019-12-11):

## Mediciones de parámetros

En este archivo se presentan los valores/caracterización de los siguientes parámetros del amplificador obtenidos mediante la simulación por LTSpice:

- Valores de reposo
- Resistencia de entrada
- Resistencia de salida/ factor de amortiguamiento
- Ganancia de lazo/Margen de fase
- Respuesta en frecuencia (ancho de banda y ganancia a lazo cerrado)
- Limitación de corriente
- Protección contra DC
- Ancho de banda de potencia/"slew rate": este parámetro no se puede medir por seguridad ya que la conmutación de la llaves en la etapa de salida incrementa la distorsión a frecuencias mucho menores a aquellas a las que deberían verse los efectos de una limitada velocidad de crecimiento. Sin embargo, se proveen los cálculos teóricos para realizar una estimación del "slew rate" y el ancho de banda de potencia.
- PSNR
- Tensiones máximas a la salida para cargas de 4 y 8ohm.
- Corriente máxima a la salida para una carga de 4 ohm.
- Máxima potencia disipada en los transistores.
- Eficiencia máxima

En cada sección se incluye una imagen del circuito utilizado en el simulador para obtener los parámetros. Para poder observar los esquema con mayor resolución, puede hacerse clic en ellos y ser redireccionado al archivo en tamaño original alojado en este repositorio. 

##### Valores de reposo
A continuación se realiza una comparación entre los valores teóricos supuestos para las corrientes y tensiones más relevantes del circuito, y aquellos obtenidos por simulación. 

###### Corrientes
| Referencia | Valor teórico [mA] | Valor simulado [mA] |
| ---- | ---- | ---- |
| Ivas/Icq17  | 10,2 | 9,5 |
| Icola/Icq19 | 1 | 0,98 |
| Icq1 | 0,5 | 0,49 |
| Icq2 | 0,5 | 0,49 |
| Icq3 | 0,5 | 0,49 |
| Icq4 | 0,5 | 0,48 |
| Icq18 | 1,4 | 1,4 |
| Ieq7 | 0,3 | 0,34 |
| Ir14 | 1 | 1,1 |
| IcU1 | 10 | 9,4 |
| IcU3 | 10 | 9,4 |

Nota: en realidad, en la simulación, Icq1-Icq2 = 1uA.

###### Tensiones
| Referencia | Valor teórico [V] | Valor simulado [V] |
| ---- | ---- | ---- |
| Vo | 0 | 0,2m |
| VbeQ18 | -0,7 | -0,64 |
| VbeQ17 | -0,7 | -0,62 |
| VbeQ19 | -0,7 | 0,6 |
| VbeQ7 | 0,7 | 0,59 |
| VbeQ8 | 0,7 | 0,63 |
| VbeQ10 | 0,7 | 0,63 |
| VbeQ12 | 0,65 | 0,57 |
| VbeQ11 | -0,65 | -0,57 |
| VbeU1 | 0,5 | 0,56 |
| VbeU3 | -0,5 | 0,54 |

##### Resistencia de entrada



Se observa que la resistencia de entrada supera en todo el rango de frecuencias medias al valor de 25kohm, que el establecido como especificación para el amplificador.

El circuito utilizado para llevar a cabo la simulación fue:



##### Resistencia de salida

Resistencia de salida con carga de 8ohm*



Factor de amortiguamiento máximo: 8ohm/22mohm = 363.

*Resistencia de salida con carga de 4ohm* 



Factor de amortiguamiento máximo: 4ohm/22mohm = 181.

El circuito utilizado para llevar a cabo la simulación fue:



##### Ganancia de lazo/Margen de fase

Medición con carga de 8ohm



Frecuencia de corte a lazo abierto: 17Hz.

Ganancia a lazo abierto: 57,4K.

Margen de fase: 81°.



El circuito empleado para llevar a cabo la simulación fue:



##### Respuesta en frecuencia



Ganancia a lazo cerrado: 22,8.



Frecuencia de corte inferior: 830mHz.



Frecuencia de corte superior: 1,46MHz.

El circuito utilizado para la medición fue:



##### Limitación de corriente

En base a la simulación "test_proteccion_sobrecorriente.asc" se obtuvieron las combinaciones de tensiones y corrientes a la salida para las cuales actúa la protección de sobrecorriente.  A continuación se muestra una imagen del circuito utilizado:



*Semiciclo positivo*

El análisis realizado en esta subsección es solamente válido para el semiciclo positivo de señal ya que, como se verá luego, las condiciones de activación de la protección para el semiciclo negativo son distintas.

En la imagen previa, V1 representa la diferencia de potencial colector-emisor del transistor de potencia de salida, mientras que IR es equivalente a la corriente de colector de dicho transistor. Se variaron los valores de IR y V1 con el fin de obtener la recta IR-V1 para la cual se produce la activación de los limitadores por sobrecorriente. Los resultados presentan en una tabla a continuación. En dicha tabla, Iactivacion representa la corriente por R4 (el resistor de linealización de emisor de la etapa de salida) para la cual se da la activación total de  la protección, es decir, por el colector de Q1 circulan 10mA (la corriente de reposo de la VAS), estando este transistor en modo activo directo. Por otra parte, Iincipiente representa la corriente que debe circular por R4 para que la protección comience a activarse (a conducir). Como criterio para esto último se ha adoptado que la corriente de colector de Q1 sea de 100uA (dos órdenes menor a la corriente de reposo de la VAS) para asegurarse de que no se produzcan activaciones inesperadas en la práctica. En la tabla a continuacion se presentan los resultados simulados:

| V1[V] | Iactivacion[A] | Iincipiente[A] |
| ----- | --- | --- |
| 2 | 11.5 | 8.9 |
| 5 | 10.8 | 8.1 |
| 10 | 9.6 | 7.5 |
| 15 | 8.3 | 5.6 |
| 20 | 7.1 | 4.3 |
| 25 | 5.8 | 3 |
| 30 | 4.7 | 2 |

Por otra parte, se realizó un gráfico donde se observa que las rectas de tanto Iactivacion vs V1 como Iincipiente vs V1 quedan comprendidas dentro de la SOA (para valores de DC, es decir, no pulsados) del transistor de potencia, como a su vez por encima de la recta de corriente consumida por una carga de 3ohm dependiendo de la excursión de salida según simulación. Se ha considerado una carga de 3ohm ya que uno de los objetivos de diseño ha sido preparar al amplificador para tolerar a esta como la carga máxima. A continuación se muestra el gráfico:



Se puede observar que la curva de acticación total limita con el extremo de la región de la SOA para tensiones Vce mayores a los 20V. Sin embargo, debido a que el transistor de potencia conectado a Vmin por su colector se enciende para tensiones de salida menores de 12V y aquel conectado a Vmax lo hace para tensiones de salida mayores a 12V, la Vce del primero estando activado nunca será mayor a 12V, mientras que la Vce del segundo nunca superará los 18V. En consecuencia, la región en el limite de la SOA nunca será alcanzada. De todos modos, para evitar un mayor estrés en los transistores por corrientes demasiado altas para bajas Vce, se decidió no incrementar la recta de activación (que se hubiera realizado variando R1, R2 y R3). Por otra parte, se observa que la recta de activación incipiente cruza la recta de la corriente consumida por una carga de 3ohm para valores de excursión superiores a los 25V. Esto implica que los limitadores se activarán ligeramente para esta circunstancia. A continuación se muestra una simulación para este caso:



La señal blanca representa la tensión de salida, mientras que I(D21) es la corriente en el diodo (que se ha incluido en el amplificador final) que se encuentra conectado al colector del transitor de la protección.

Se puede observar como se producen picos de corriente de aproximadamente 150uA en el semiciclo positivo de saldia para esta situación. De todos modos, estos picos de corriente resultan ser mucho menores a la corriente requerida por la VAS para alimentar a los drivers (del orden de 1mA). Por lo tanto, estos picos no afectan al correcto funcionamiento del amplificador. 

Finalmente, con la resistencia R1 es posible regular la pendiente de la recta de activación de la protección, conservando su ordenada al origen. A menor valor de R1, mayor será la pendiente. Haciendo uso de esta propiedad, se podría haber variado esta resistencia para reducir las corrientes máximas a la salida en la región donde Vce es mayor a 15V. Sim embargo, para excursiones de salida mayores a los 12V, las conmutaciones de la etapa de salida producen picos de tensión que derivan en diferencias de potencial Vbe y Vce de Q1 mayores a las esperardas en un amplificador ideal. Dichas diferencias inducen la activación de la protección por cortos períodos de tiempo y no pueden ser eliminadas. Empero, a menor umbral de activación de la protección (menor recta de activación) dichos picos de corriente serán mayores. En consecuencia, al disminuir R1 se reducen las corrientes máxima obtenibles a la salida (protegiendo aun más a los transistores de saldida), pero se generan mayores picos de consumo de la corriente de la VAS. En esta línea, en la anterior imagen presentada se puede ver como, independientemente de los incrementos de corriente de forma cuasi-senoidal en el semiciclo positivo (relacionados con el umbral de activación incipiente de los limitadores como se presentó previamente), existen picos de duranción de microsegundos de mayor valor. Para esta configuración de los limitadores, a máxima excursión de salida, con 3ohm de carga y una frecuencia de 20kHz, dichos picos alcanzan el valor de 270uA. Fue entonces que, para evitar el aumento de dichos picos, se decidió no reducir R1. A continuación se incluye una captura de la simulación de este último caso:



*Semiciclo negativo*

Como se describe en [descripcion_detallada_amplificador.md](descripcion_detallada_amplificador.md), en el semiciclo negativo, al activarse la protección de Q22, circula por su colector una corriente del orden de los 100mA debido a que esta es incorporada por la VAS. La limitación para la corriente que esta puede incorporar está dada por R44, que para dada corriente activa a Q25, quien a su vez le quita corriente a la entrada de la VAS y limita la excursión de salida.

En la simulación, si se coloca una carga de 1ohm y se introduce a la entrada del amplificador una señal de 1,1V se obtiene una señal cuadrada en el nodo de salida cuyos extremos están dados por las corrientes a las que actuan los limitadores. Con R44 = 5ohm se obtiene a la salida:



Con lo que la limitación de corriente para el semiciclo negativo de encuentra en los 9,5A. Este valor es mayor que para el semicilo positivo, que ronda los 6A. Empero, debido a lo mismo que se expuso para el semiciclo positivo, como los transistores de potencia de salida tendrán una no mayor en módulo a 20V (porque solo actuan para una región de la excursión de salida), una corriente de 9,5A se encuentra dentro de la SOA, aunque en su límite. Por esto es que se decidió no alterar los valores de las resistencias que se conectan a la base de Q22. 

##### Protección contra DC
El circuito utilizado para llevar a cabo la caracterización de la protección contra DC fue el siguiente:



Vale tener en cuenta que todas las pruebas fueron realizadas con una tensión de DC > 0, salvo que se aclare lo contrario.

*Velocidad de respuesta medida con una tensión a la salida de 25V*



Tiempo hasta que se abre el relé: 27ms.

*Velocidad de respuesta medida con una tensión a la salida de 5V*



Tiempo hasta que se abre el relé: 120ms.

*Mínima tensión a la que actúa la llave*



Mínima tensión medida: 0,9V de continua a la salida.

*Frecuencia a partir de la cual se activa la llave*

Dado que el filtro pasa bajos de la llave deja de atenuar a frecuencias bajas, esto conllevará que esta se active a partir de una dada frecuencia de señal de entrada (lo cual también ocurrirá para todas las frecuencias menores a esta). Es consecuentemente de interés que dicha frecuencia se encuentre por debajo del espectro audible para no correr el riesgo de que se produzca la activación de la llave cuando el dispositivo se encuentra reproduciendo música.

Se realizaron simulaciones para determinar la frecuencia antes mencionada con dos valores distintos de amplitud a la salida 12V (excursión media) y 28V (excursión completa). Es esperable que la frecuencia de corte sea más alta cuanto mayor la amplitud de salida, ya que, para un dado porcentaje de atenuación creado por el filtro, en un caso llegará una mayor tensión a los transistores que deciden la activación de la protección que en el otro. Por lo tanto, el relé se activará a una frecuencia mayor con 28V de ammplitud que con 12V.

Los resultados de las simulaciones fueron los siguientes:

- Frecuencia de corte de la llave para una componente de DC de 12V:



Donde Vout es la tensión en la salida del amplificador (pero la entrada de la protección) y V(n001) la tensión en el nodo de al carga.

La frecuencia de V(n001) es de 6Hz, de modo que se puede ver que la frecuencia de corte tiene aproximadamente este valor. Esto se sabe porque el nodo de la resistencia de carga se encuentra puesto a tierra después de un transitorio inicial, es decir, no circula corriente por la carga; mientras que el nodo que conecta a las resistencias R28 y R27 sí posee tensión. A frecuencias mayores, Vout efectivamente presentaba la tensión, denotando que la protección no se activaba:



Esta última simulación se corresponde con una frecuencia de 7Hz, donde se ve que la protección no actúa.

- Frecuencia de corte de la llave para una componente de DC de 28V:



Se observa que, para una amplitud de 30V, la protección actua con una frecuencia de 15Hz aproximadamente. Sin embargo, con una de 16Hz ya no lo hace:



En consecuencia, las protección de DC actúa a frecuencias no audibles, lo que se considerá que no afectará el normal funcionamiento del amplificador.

*Mínima tensión de continua negativa con la que actua la protección*

Por último, se repitió la simulación de la mínima tensión a la que actua la protección pero con una tensión de DC negativa. El resultado fue que esta se activa para tensiones de entrada mayores a los 0,67V, como se puede ver a continuación: 



Se introdujo un pulso de tensión negativa a la entrada (Vout) y se observó que la tensión en la carga (Vcarga) caía antes de que el pulso a la entrada finalizara. 

Esto da como resultado que el umbral de activación para el caso negativo es menor que para el positivo. Dado que las contantes de tiempo del circuito son aproximadamente las mismas para el caso en el que se activa el sistema por DC negativa que aquel en el que lo hace por DC positiva, se concluye que es de esperarse que todos los otros parámetros medidos sean mejores para con DC negativa que positiva. Esto se corroboró luego en la práctica, como se puede ver en el documento [caracterizacion_proteccion_DC.md](../mediciones_amplificador/caracterizacion_proteccion_DC.md).

##### Ancho de banda de potencia/"slew rate"

La simulación de la respuesta del circuito a una señal cuadrada de entrada para la determinación de SR+ se muestra a continuación:



Se observa que la pendiente obtenida es de aproximadamente 26V/us, algo menor al calculado teóricamente, por la presencia de capacidades parásitas de los transistores. Con este valor se obtiene un ancho de banda de potencia de 150kHz.

Por otra parte, para SR-:



Donde se observa que la pendiente en la región central (no afectada ni por las conmutaciones ni por la velocidad en señal del circuito) es de aproximadamente 60V/us. De este modo, se confirma que el ancho de potencia está determinado por SR+.

El circuito utilizado para la medición fue:



##### PSNR

*Alimentación Vmax (30V)*



*Alimentación -Vmax (-30V)*



*Alimentación Vmin (12V)*



*Alimentación -Vmin (-12V)*



Para la simulación de la PSNR con respecto a las distintas fuentes de alimentación se utilizó el siguiente esquema: 



Donde se colocaron generadores sinusoidales en serie con las fuentes y se realizó la división entre la señal observada a la salida y la del generador en sí. Para la medición de la PSNR con respecto a cada fuente, solo su respectivo generador sinusoidal fue activo. En el caso de la PSNR con respecto a -Vmax (la peor al compararla con la del resto de las fuentes) se realizó una simulación extra colocando una resistencia de 1ohm en serie con el generador para representar a los cables no ideales que se conectarán a la placa en la práctica. De este modo, el capacitor de C8 (de 1000uF) actua como filtro llevando la cota superior de la PSNR de -76dB a -79dB con respecto a -Vmax.

##### Tensiones pico máximas a la salida

*Carga de 8ohm*



Vo_max =  27,8V.

*Carga de 4ohm*



Vo_max = 27,1 V.

##### Corriente pico máxima a la salida para una carga de 4 ohm



Io_max = 6,8 A.

##### Potencia máxima entregada a la carga

De los datos simulados para la máxima tensión pico obtenible a la salida se llega a que la máxima potencia entregable (no nominal) a la carga es:

- Con carga de 8ohm: 48 W.
- Con carga de 4ohm: 91 W.

##### Potencia disipada en los transistores

###### Transistores alimentados con las tensiones más altas en módulo (+30V y -30V)

Se varió la excursión de salida y se calculó la potencia media por medio de la simulación [amplificador_potencia.asc](amplificador_potencia.asc) para obtener:

| V_out [V] | Pot_transistores [W] |
| --- | --- |
| 19 | 16,7 |
| 20 | 16,9 |
| 21 | 16,8 |
| 22 | 16,6 |
| 25 | 14,9 |
| 27 | 13,9 |

Dado que esperable que la potencia disipada sea menor a valores de V_out menores a 19V (porque los transistores se encienden en una porción menor del semiciclo) y mayores a 27V (debido a que el amplificador tiende a un funcionamiento en clase B), se tiene que la potencia máxima dispada en los transistores será aproximadamente 17W.

Pot_max_alta_tension = 17 W.

###### Transistores alimentados con las tensiones más altas en módulo (+12V y -12V)

Se realizó el mismo procedimiento para los transistores alimentados con las tensiones de módulo más bajo y se obtuvieron los siguientes valores cuando la etapa de salida no conmuta (|V_out | < 12V):

| V_out [V] | Pot_transistores [W] |
| --- | --- |
| 5,5 | 3,2 |
| 6 | 3,3 |
| 7 | 3,3 |
| 7,3 | 3,3 |
| 7,6 | 3,3 |
| 9 | 3 |

Se ve que la máxima potencia disipada se alcanza para aproximadamente 7.6V de excursión, lo cual se condice con el valor de máxima potencia disipada en los transistores de un clase B alimentado con 12 V (a 64% de la excursión máxima).

Cuando la etapa de salida conmuta se tiene que los transistores alimentados con +12V y -12V disiparán menos que sin conmutar ya que se encienden durante una parte menor del semiciclo. 

En consecuencia, la potencia máxima disipada en los transistores alimentados con las tensiones más bajas es aproximadamente 3,3 W.

##### Eficiencia a máxima excursión
Se colocó una señal de entrada tal que se obtuviera la máxima excursión posible a la salida y se realizó la misma medición de las corrientes y tensiones relevantes que en las mediciones realizadas sobre el prototipo construido del amplificador (ver el archivo correspondiente de las mediciones). De esta forma, se obtuvo una eficiencia máxima de 75% a máxima excursión.

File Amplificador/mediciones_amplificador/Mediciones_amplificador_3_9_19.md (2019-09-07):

### Mediciones 19/7/19

#### Resumen

Para comenzar se realizaron mediciones de distorsión armónica con el amlpificador del mismo circuito que el de las mediciones del día 19/7/19, pero incluyendo capacitores de 330pF cortocircuitando juntura base-colector de los drivers. Esto se realizó ya que, tanto en la práctica como por simulación, este mecanismo demostró evitar oscilaciones no intencionadas en el circuito que ocurrían al entrarse en zona de conmutación de la etapa de potencia con excursiones en el nodo de salida superiores a los 20Vpp.

A continuación se muestra un esquema con dichos capacitores:



Luego, se procedió a agregar las protecciones por sobrecorriente de la etapa de salida y se realizaron nuevamente mediciones de distorsión. El esquema del circuito sobre el que se medió es:



Por último, se soldó al PCB la protección de DC y se corroboró que su funcionamiento fuera el apropiado, quedando el esquema circuital del siguiente modo:



#### Banco de trabajo

- Instrumental:
  - Osciloscopio: Siglent SDS 1102CML.
  - Fuentes de tensión: Protomax DC Power Supply HY3005D-3.
  - PC con software SprectaPLUS-SC para poder medir la distorsión a la salida del amplificador.
  - Generador de señales: se usó la salida de line-out de la propia PC.

Las mediciones de distorsión fueron realizadas enteramente con una carga de 8ohm.

Se introdujo a la entrada del amplificador la señal proveniente de la salida de line-out de la PC. Por otra parte,  la salida del amplificador fue conectada al puerto de line-in de la PC, colocó de por medio en paralelo un atenuador compuesto por un preset de 100ohm en serie con un resistor fijo de 1kohm (5% de tolerancia). La entrada de line-in fue conectada al nodo entre el preset de 100 ohm (cuyo otro terminal se encontraba puesto a tierra) y la resistencia de 1kohm. Dicho atenuador fue utilizado para que a grandes excursiones de salida no se saturase la entrada de line-in de la PC.

Se incluye una foto del amplificador durante la medición, si la protección de DC: 



Y una foto del amplificador con la protección de DC colocada:

AGREGAR_FOTO

#### Mediciones
A continuación se incluyen los resultados de las mediciones de distorsión para los casos sin limitadores y con limitadores. 

##### Sin limitadores
Los valores obtenidos fueron los más bajos que se logró conseguir luego de variar algunos valores del circuito como su compensación y los resistores que se conectan al gate de los MOSFET  M1 y M3.

Los porcentajes de "potencia a la carga" tabulados son con respecto a la potencia máxima otorgable. 

- Con una señal de 1kHz:

| Potencia a la carga | THD |
| --- | --- |
| 10% | 0.008% |
| 50% | 0.022% |
| 90% | 0.022% |

- Con una señal de 10kHz:

| Potencia a la carga | THD |
| --- | --- |
| 10% | 0.028% |
| 50% | 0.031% |
| 90% | 0.024% |
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

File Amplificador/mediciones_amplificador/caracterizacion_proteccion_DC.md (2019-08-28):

## Caracterización de la proteccion contra DC en el nodo de salida

Se procedió a caracterizar la protección contra DC en el nodo de salida.
El esquema del circuito armado fue el siguiente:



Se utilizó una resistencia de 100kohm como carga para el limitador y se colocó un diodo entre los contactos que activan/desactivan el relé para evitar sobrepicos de tensión ocasionados por el inductor de este último.
 
A continuación, se muestra una foto del circuito elaborado en una placa de prototipado:



### Banco de trabajo

- Instrumental:
 - Generador de funciones: Topward Function Generator 8140.
 - Osciloscopio: Siglent SDC1102CML.
 - Fuente de tensión: M10-380D-303E.

Se incluye una foto del banco de trabajo:


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

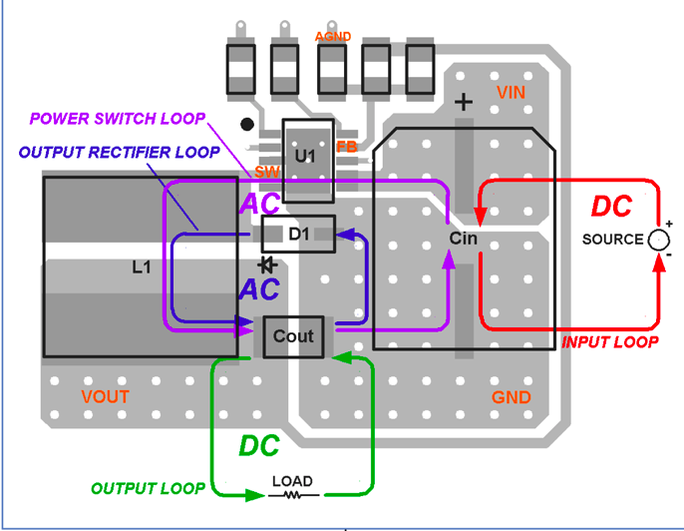
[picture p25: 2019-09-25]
DOC/Diseno_PCB_switching/ejemplo_buck_converter_PCB.png

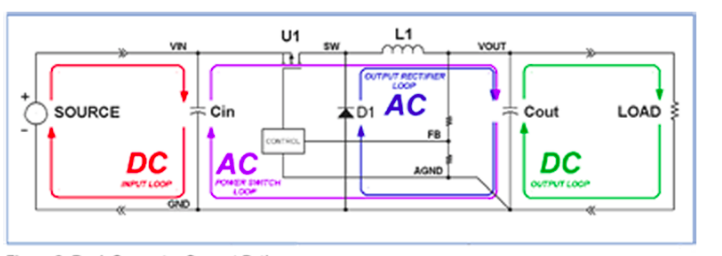
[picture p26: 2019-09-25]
DOC/Diseno_PCB_switching/loops_fuente_switching.png

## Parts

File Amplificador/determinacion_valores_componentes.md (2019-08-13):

# Determinación de los valores de los componentes
En este documento se procede a explicar los valores adoptados para los componentes utilizados. De esta forma, constituye una profundización de lo expuesto en [descripcion_detallada_amplificador.md](descripcion_detallada_amplificador.md). Algunos valores han sido determinados de forma teórica, mientras que otros han sido especificados suponiendo un valor aproximado apropiado y luego realizando un ajuste fino mediante simulación con el programa *LTSpice*.

A lo largo del archivo se irán determinando los componentes a partir las especificaciones que se deseó alcanzar, las cuales se encuentran en el archivo [Resumen_y_especificaciones.md](Resumen_y_especificaciones.md). A cada una de ellas se les ha asociado una sección correspondiente, las cuales, a medida que se las recorra, irán derivando en los valores finales.

A continuación de presenta un esquema del ampificador sin la protección de DC del parlante:



### Potencia nominal a la carga
Uno de los objetivos iniciales del proyecto fue diseñar un amplificador que pudiera entregar más de 40W a una carga de 8ohm. Con el fin de poseer un margen que permitiera cumplir con esta meta mínima en la práctica (en caso de que, una vez armado el circuito, asuntos imprevistos en la teoría redujeran la máxima potencia obtenible en la carga alterando, por ejemplo, la máxima excursión de salida real) se especificaron 45W. Sabiendo que la potencia promedio entregada a la carga para una armónica senoidal es:

 

Con una carga de 8ohm, esto implica que se requiere una máxima excursión de salida de:

 

Dado que las fuentes de laboratorio disponibles para la puesta a prueba del amplificador durante su armado pueden proveer hasta 30V, se logra (en un principio, y despreciando las caídas internas del amplificador) cumplir con la anterior excursión requerida. Debido a que el amplificador no será capaz de alcanzar una excursión de salida igual a su alimentación por los motivos que se verán a continuación, se decidió alimentar al amplificador con los 30V de la fuente.

Por otra parte, para una potencia nominal de 85W con una carga de 4ohm se requiere de una excursión máxima de:

 

Habiéndose adoptado una etapa de salida con los transistores de potencia en paralelo, drivers constituidos por solo un transistor en cada rama y una VAS donde el transistor que genera la ampificación de señal es NPN, la limitación en la excursión está dada por la saturación de Q8 en el semiciclo negativo de señal ya que, como se verá más adelante, se eligió una corriente de reposo de la VAS que fuera suficiente como para evitar la entrada en corte de este transistor para la excursión máxima de salida.

La corriente máxima a la carga (y que circulará por lo tanto por el emisor de los transistores) para el peor caso (carga de 4ohm) será, aproximando 30V de excursión máxima:

 

Observando la hoja de datos de los transistores de potencia complementarios 2SC5200 (NPN) y FJL4315 (PNP) elegidos para la etapa de salida (ver su justificación al final de [descripcion_detallada_amplificador.md](descripcion_detallada_amplificador.md)), se llega a que para esa corriente, la tensión base-emisor en módulo es aproximadamente Vbe = 0,9V.
Por otra parte, el valor de su Beta es aproximadamente Beta = 50. Entonces, la corriente pico máxima que deben proveen los drivers es aproximadamente 7,5A/50 = 150mA. Según la hoja de datos de los transistores utilizados como drivers (BD139 y BD140) esto implica una tensión base-emisor máxima en módulo de 750mV.  Además, con 7,5A de corriente a la salida y resistores de degeneración de emisor de los transistores de potencia (R27 y R28) de 0,1ohm (este valor, como se explica en [descripcion_detallada_amplificador.md](descripcion_detallada_amplificador.md), optimiza la linealidad de la etapa de salida), la caída en ellos es 750mV. Finalmente, la tensión de saturación del transistor 2SCR514P empleado para Q8 es típicamente 100mV. En consecuencia, la excursión máxima viene dada por:



Este peor caso para la excursión máxima excede los valores mínimos requeridos para alcanzar las potecias nominales con 4 y 8ohm según se determinó anteriormente. Es entonces que se conservan los 30V como la tensión de alimentación de la etapa diferencial y VAS (para poder alcanzar la amplificación deseada) y también como la alimentación alta (Vmax) de los transistores de salida (es decir, que se conecta a los colectores de U2 y U4).

Dado que se buscó diseñar un amplificador clase H, se incorporó una seguda tensión de alimentación de la etapa de salida, cuyo valor es menor que el de Vmax. Este resultó ser 12V ya que optimiza las figuras de distorsión obtenidas para el tanto el 10% como el 50% de la potencia nominal a la carga. De poseer una valor mayor, lo quiebres generados en la senoidal por las conmutaciones se dan en zonas cercanas a los picos de la señal, aumentando la distorsión para el 50% de la potencia nominal. Si se hace que la conmutación ocurra para un valor bajo de excursión, los quiebres se darán en una zona más cercana a la base de la senoidal en el 50% de la excursión, con lo que la distorsión disminuirá. Por otra parte, 12V como tensión de alimentación baja es suficiente como para que la conmutación se dé para excursiones mayores a las correspodientes a 10% de la potencia nominal a la carga, con lo que la comutación no afectará con distorsión a esta especificación.

Por otra parte, siendo la corriente pico máxima en el emisor de los drivers de 150mA, y teniendo estos un parámetro Beta para dicha corriente de Beta = 140, su corriente de base pico será Ib_max_pico = 1mA.

Dado esto, se decidió otorgarle a la VAS una corriente de polarización de aproximadamente 10mA para poder alimentar a los transistores de potencia en el caso de mayor ecursión de salida. De este modo, tal y como se supuso antes, el límite máxima excursión viene dado por la saturación de Q8, y no el su entrada en corte por limitaciones en la corriente de reposo de la VAS:

Se eligió la fuente de corriente de la siguiente imagen:

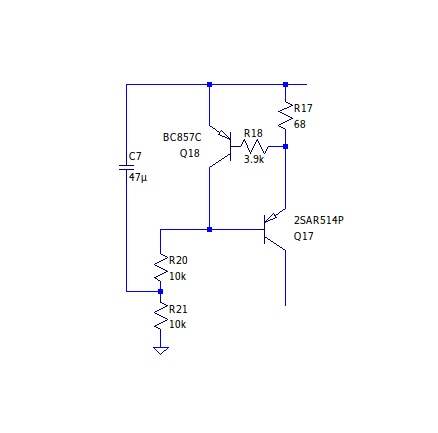
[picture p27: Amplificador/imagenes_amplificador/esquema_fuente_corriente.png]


Donde se supone que Q18 está polarizado de forma que   . Entonces, con un resistor R17 de 68ohm se consigue una corriente en la VAS de:

 

Donde, asumiendo además que  , la corriente en el colector de Q8 es:



Donde se utilizó R20 = R21 = 10kohm, de forma que Icq8 tenga un valor normal para un transistor de baja potencia con el BC860. 

En la práctica, las corrientes de base de Q17 y Q18 disminuirán el valor de Ivas, hasta hacerlo de aproximadamente 9,5mA, aunque este es un valor suficiente como para garantizar alimentar a la base de los drivers.

### Polarización y consumo sin señal
Embebido en la VAS se colocó un multipicador de Vbe, el cual se muestra a continuación:

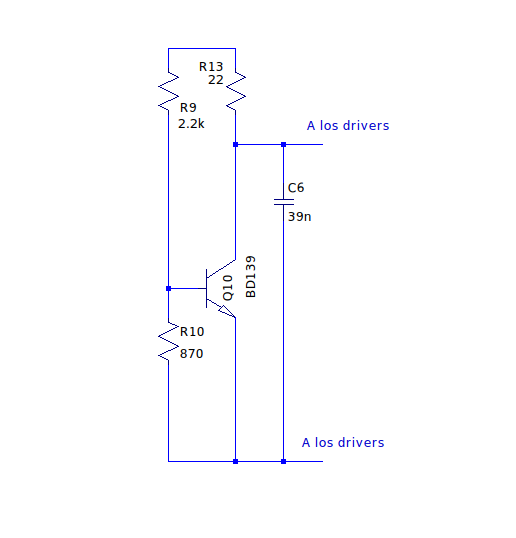
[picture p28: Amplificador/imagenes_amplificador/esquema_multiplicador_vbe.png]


El objetivo fue polarizar los transistores de potencia de salida U1 y U3 con una corriente de reposo de aproximadamente 10mA. Si bien este no es el valor óptimo para reducir la distorsión, se lo propuso ya que permite obtener un bajo consumo sin señal. 

La tensión colector-emisor del mutiplicador (sin contemplar el resistor de linealizacion R13) es:



Donde se asume Vbe = 0.7V para realizar una primera aproximación a la Vce que se obtendrá.
Deseando una corriente de colector de reposo en U1 y U3 de aproximadamente 10mA, se tiene de la hoja de datos de estos transistores que, . Además, siendo para esta corriente sw colector BetaU1 = BetaU3 = 130, se tiene que IbU1 = -IbU3 = 80uA. Eligiendo R14 = 1kohm (cuyo valor se justificará más adelante en este documento), se tiene que Ir14 = Icq12 = -Icq11 = 1mA  (ya que la corriente base de U1 y U3 es despreciable frente a Ir14). Entonces, de la hoja de datos de Q11 y Q12, . Entonces, se debe buscar que: 

Para ello, eligiendo R9 = 2,2kohm, se obtiene el valor de Vceq10 requerido con R10 = 960ohm . Entonces, colocando un preset de 2kohm en el lugar de R9 se consigue suficiente excursión como para confgurar el multiplicador en la práctica de forma que la corriente de colector de U1 y U3 sea aproximadamente 10 mA. En la simulación, se llegó a que este preset debería ser colocado con un valor de 850ohm para obtener una corriente de aproximadamente 4,8mA en R27/R28 y de 9,5mA en los emisor de U1 y U3. El hecho de que la corriente de emisor de los transistores de potencia sea mayor que la de los resistores de linealizacion reside en que los diodos conectados entre la base y el emisor de los transistores U2 y U4 (y que forman parte de los conmutadores) consumen una corriente del orden de los miliamperios. 

El resistor R13 tiene como finalidad linealizar la variación de la tensión Vce con la corriente de la VAS. Esta linealidad se manifiesta a la hora de hacer funcionar al amplificador en señal. El valor elegido para R13 fue de 22ohm ya que, según las simulaciones, optimiza dicha linealidad. A continuación se muestra una captura de Vceq10 en función de la corriente de la VAS obtenida por simulación para distintos valores de R13. La curva roja representa R13=15ohm, la curva celeste R13=22ohm, y la curva violeta R13=27ohm:

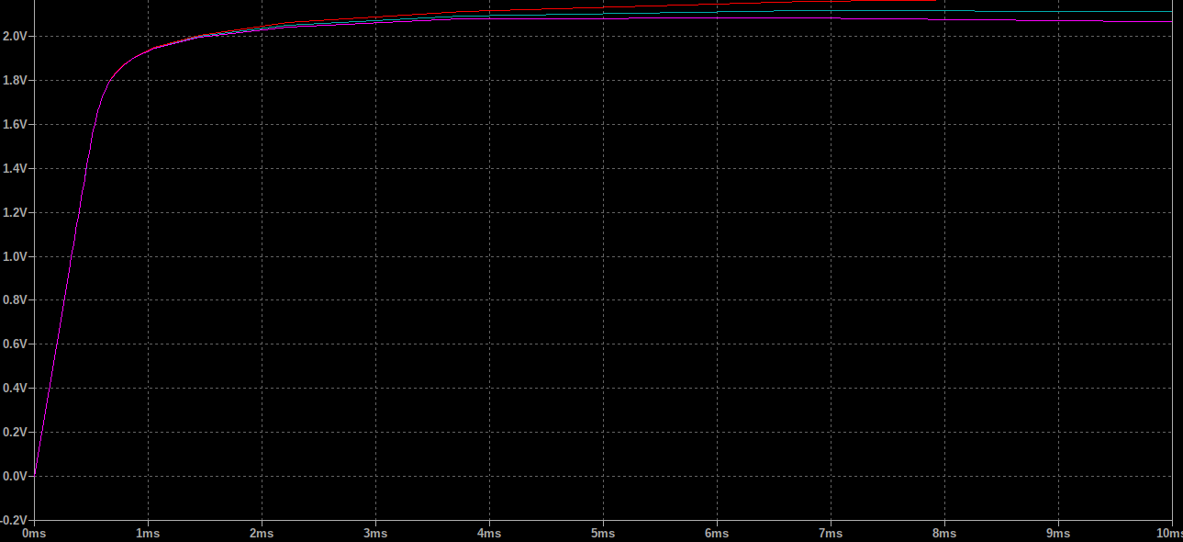
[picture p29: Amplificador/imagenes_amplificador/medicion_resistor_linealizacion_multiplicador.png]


Por otra parte, el capacitor C6 sirve para atenuar el pico que experimenta la impedancia equvalente del multiplicador para altas frecuencias ocasionado por sus comportamientos inductivos y capacitivos según el espectro. Por medio de simulaciones, se probaron distintos valores comeriales de C6 y se llegó a que el punto óptimo se encontraba en 39nF. A continuación se muestra una captura de la simulación donde se realizó un barrido en frecuencia de la impedancia equivalente del multiplicador para distintos valores de C6 (verde: 33nF, azul: 39nF, rojo: 47nF):

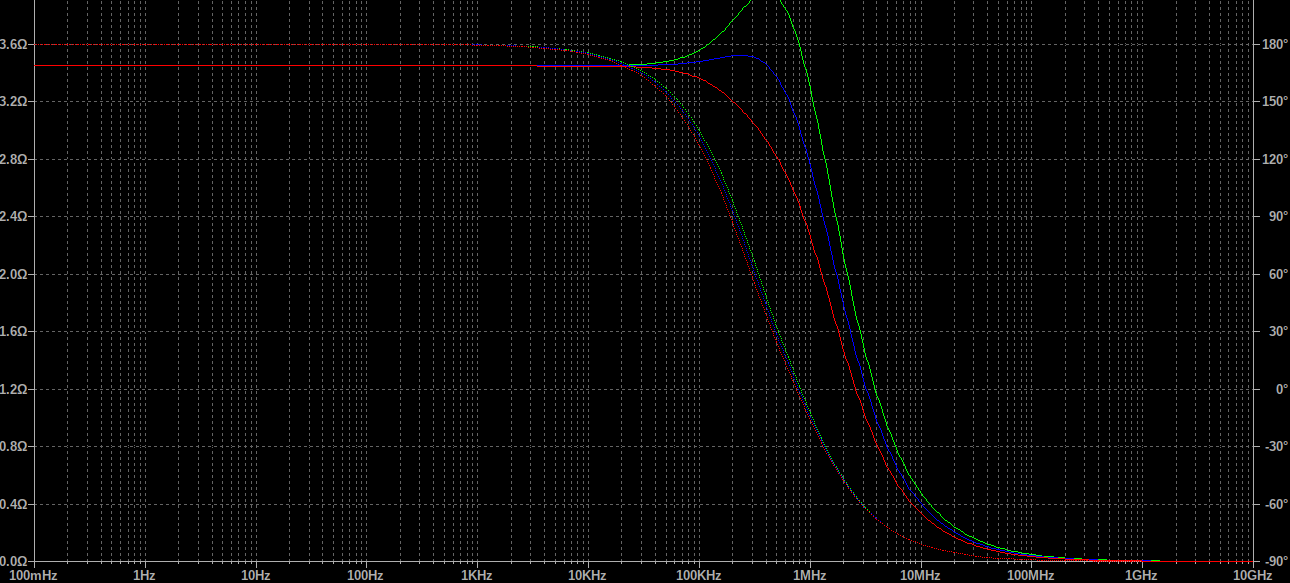
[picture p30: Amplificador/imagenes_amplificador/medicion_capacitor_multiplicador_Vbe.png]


### Ganancia a lazo abierto
Para saber la ganancia a lazo abierto apropiada se tomó como criterio aquella utilizada por Douglas Self en el diseño del amplificador clase G en base al cual se desarrolló este amplificador. Mediante esta ganancia a lazo abierto se consigue una ganancia de lazo lo suficientemente alta como para alcanzar las especificaciones de distorsión deseadas.

La ganancia a lazo abierto viene dada por el producto de las ganancias de las tres etapas del circuito: entrada diferencial, VAS y etapa de salida. Se comienza entonces con el análisis de la etapa diferencial de entrada.

#### Etapa diferencial de entrada
Se incluye a continuacioń una imagen de la etapa diferencial de entrada elegida con su copia espejo de corriente generando la corriente de cola:



La etapa diferencial constituye un ampificador de transconductancia. La corriente de salida en función de la entrada diferencial es:



Donde se ha supuesto que las corrientes de ambas ramas del par son aproximdamente iguales, así como también R1 = R2 y R3 = R4.

A R1 y R2 se les asoció el valor de 120ohm ya que este es lo suficientemente pequeño como para no reducir demasiado la amplificación de la etapa (y en consecuencia la ganancia total a lazo abierto), pero a su vez permite linealizar lo suficientemente la etapa diferencial (intoduciendo una realimentación en Q1 y Q2 que tiende a igualar la corrientes del par). R3 y R4 fueron también elegidas de forma de favorecer la igualdad de las corrientes del par, ya que en una copia espejo simple como la conformada por Q3 y Q4, al ser R3 y R4 lo suficientemente grandes se tiene que las corrientes de una y otra rama de la carga activa están aproximademente relacionadas por:



Entonces, es posible ajustar la diferencia de las corrientes del par mediante la dispersión entre R3 y R4 (cuya cota se puede determinar al comprar los componentes), en vez de dejar que esto dependa de las diferencias en los Vbe y Beta de los transistores. Se eligió R3 = R4 = 68ohm ya que permiten que esto último se cumpla si introducir demasiado ruido termico en la etapa de entrada. Esto último se incrementa cuanto mayor sea el valor de los resistores, y es indeseable ya que, por el teorema de Frii, si la primer etapa posee una ganancia lo suficientemente grande (que es el caso) el ruido introducido a la señal por todo el sistema es aproximadamente el creado por la etapa de entrada. R1 y R2 también se tomaron en el orden de los cientos de ohm y no mayores por este motivo.

Por otra parte, se decidió utilizar una corriente de cola de aproximadamente 1mA. Esto garantiza una ganancia a lazo abierto lo suficiemente grande, y a su vez reduce los ruidos introducidos en la etapa diferencial por la corriente de reposo de los transistores. Entonces, por el mismo motivo que con la carga activa, la relación entre la corriente de cola del par diferencial y la corriente de la VAS es:



De este modo, eligiendo R19 = 680ohm, se obtiene aproximadamente Icola = 1mA.

#### VAS
A continuación se muestra una imagen de la VAS:



Esta etapa posee una ganancia de transresistencia, la cual amplifica la corriente entrante a la base de Q7. Dicha ganancia viene dada aproximdamente por:



Donde Rcvas es la resistencia equivalente de carga que ve Q8.

Allí puede verse que el parámetro Beta de Q7 es directamente proporcional a la ganancia a lazo abierto. Por lo tanto, maximizarlo permite máximizar a esta última. Por ello es que se eligió un transistor BC860C para este dispositivo, ya que posee el parámetro Beta más alto dentro de la familia BC.

R44, que es el resistor de sensado del limitador de corriente definido por Q25 y R43, se mantuvo con un valor bajo (5 ohm), ya que de ser mayor reduciría considerablemente la ganancia a lazo abierto al introducir una realimentación de emisor en Q8. El mismo criterio fue tenido en cuenta para el resistor R8 del filtro pasabajos de la tensión de alimentación Vmax, cuyo valor adoptado fue 10ohm.

Debido a que la corriente en la VAS es de aproximadamente 10mA, la tensión de reposo en el emisor de Q7 es:



Entonces, siendo R7 = 2,2kohm, la corriente emisor de Q7 es IeQ7 = VbeQ7/R7 = 0,3mA. Dicha corriente es suficiente como para polarizar correctamente a Q7, manteniéndose lo suficientemente baja como para no inducir ruidos en la etapa.

Por otro lado, la resistencia de carga de la VAS, suponiendo que la excursión es lo suficientemente grande como para que la etapa de salida opere en clase B y no A, es:



Donde se ha despreciado la impedancia equivalente del multipicador de Vbe por ser del orden de las decenas de ohm y, en consecuencia, mucho menor a la resistencia de entrada de la tercer etapa y de la carga activa de la VAS. También se ha asumido que la etapa de salida actua en baja excursión y puede utilizarse el modelo linealizado para obtener su resistencia de entrada.
 
Con dicha RcVAS se obtiene:


Entonces, aproximando la ganancia de la etapa de salida en 0,99 se obtiene que la ganancia a lazo abierto de todo el sistema es:



#### Drivers



La resistencia R14 fue elegida con un valor de 1kohm debido a que este minimiza los valores simulados de distorsión. Con esta resistencia, siendo la tensión en el nodo de salida de aproximadamente 0V y las tensiones base emisor de U1 y U3 aproximadamente 0,5V, se tiene que la corriente de colector de Q11 y Q12 es 1mA.

### Ganancia a lazo cerrado
En la siguiente figura se incluye una imagen del realimentador, definido por R22 y R3 junto con el *bootstrap* a la entrada:

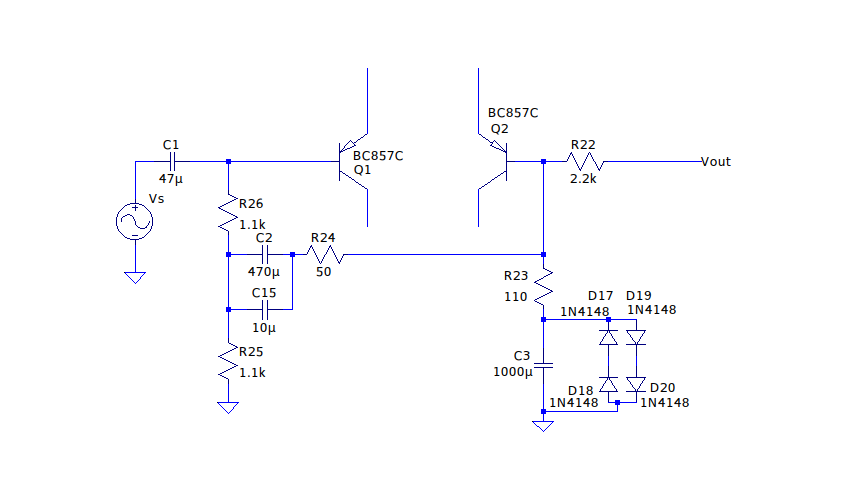
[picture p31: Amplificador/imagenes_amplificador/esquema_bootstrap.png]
 

Entonces, sin considerar el *boostrap* en la entrada, el factor de realimentación viene dado por:



Empleando R22 = 2,2kohm y R23 = 110 se obtiene f = 0,048. De esta forma, sabiendo del apartado anterior que a >>1 se llega a que la ganancia a lazo cerrado es:



Este valor es menor al objetivo de las especificaciones, que es 23. Sin embargo, al actuar el *boostrap* en señal, R25 queda en paralelo con R23, teniéndose entonces:



De modo que:



Obteniéndose el valor deseado.

Por otra parte, el orden de lo resistores R22 y R23 pudiera ser aumentado o reducido ya que el divisor resistivo queda definido por la relación entre ellos. Empero, de ser aumentados, el ruido térmico creado en la realimentación se ve incrementado. Por otra parte, de ser reducidos los valores de R22 y R23, la impedancia de entrada en señal de verá reducida. Lo que es más, de por sí R22 y R23 son lo suficientemente pequeños como para requerir un boostrap para lograr que la impedancia de entrada sea del orden de las decenas de kiloohm, de forma que R22 y R23 no deberían ser reducidos aun más.

### Estabilidad
Por medio de simulación se determinó que, siendo C4 = 33p, el margen de fase es 81°. El resultado se muestra a continuación:

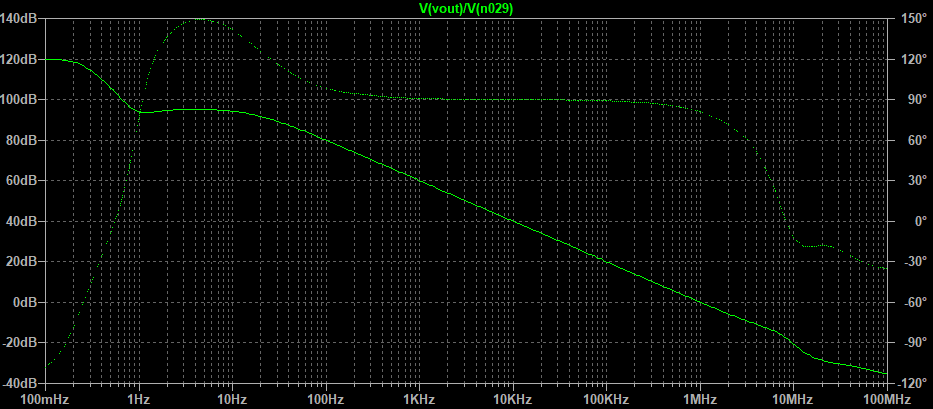
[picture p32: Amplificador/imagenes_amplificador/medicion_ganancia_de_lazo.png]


Si bien, en un principio, dicho margen de fase se asociaría con un sistema sobrecompensado (lo optimo sería 60°), se ha decidido utilizar C4 = 33nF para atenuar las oscilaciones que podrían originarse en la práctica en el amplificador producto de las conmutaciones.

### Slew rate
En el semiciclo positivo de señal se tiene que la velocidad de crecimiento viene dada por (despreciando las capacidades parásitas sobre todo de Q7):



Donde  Icola es la corriente por R19.

Por otra parte, dada la topología del circuito, se espera que la velocidad de decrecimiento (SR-) sea similar o superior a la de crecimiento. De esta forma, el ancho de banda potencia es:



donde se tomó Vomax = 27,8.

Las simulaciones realizadas e incluidas en [Mediciones_parametros_simulacion.md](simulaciones_amplificador/Mediciones_parametros_simulacion.md) demuestran este razonamiento.

El valor de ancho de banda de potencia obtenido para este caso es mucho mayor al mínimo requerido por el circuito para poder funcionar a máxima excursión de salida dentro de la banda de frecuencias audibles sin distorsionar por limitaciones en la velocidad de crecimiento.

### Ancho de banda
La frecuencia de corte superior de la ganancia a lazo cerrado está dada por la frecuencia de corte determinada por el polo introducido por el capacitor de compensación, multiplicada por el factor (1 + af). Entonces, el polo dominante en altas frecuencias a lazo cerrado es:



Donde el polo a lazo abierto es:



Donde Rout1 es la resistencia de salida de la etapa diferencial:


Y Rin2 es la resistencia de entrada de la VAS vista desde la base de Q7:


Siendo entonces:


De forma que la frecuencia de corte superior es:


De la simulación fue posible obtener el siguiente resultado en pequeña señal:
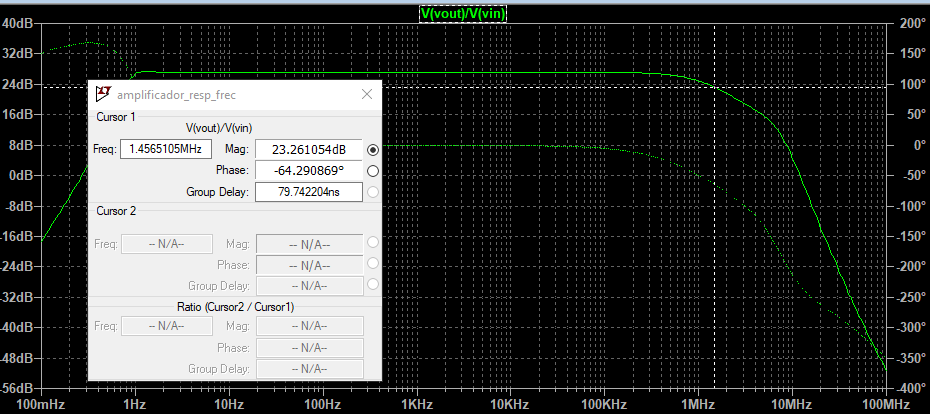
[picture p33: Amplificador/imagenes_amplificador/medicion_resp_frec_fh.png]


Por lo tanto, la frecuencia de corte superior resultó ser aproximadamente una década superior a la estimada teóricamente. La causa podría encontrarse en la influencia del capacitor de compensación, que crea un lazo de realimentación dentro de la VAS que afecta su impedacia de entrada y su ganancia. Sin embargo, el ancho de banda obtenido en un principio por medio de la teoría resulta ser suficiente para el amplificador en cuestión debido a que se se extiende por encima de las frecuencias de audio. 

Por otra parte, se busca que la frecuencia de corte inferior a lazo cerrado, determinada por aquella en la que la realimentación comienza a volverse unitaria, no afecte a las frecuencias audibles ya que se convierte en una fuente de distorsión. Suponiendo que el polo del capacitor de entrada C1 es mucho menor al de C3, la base de Q1 se encuentra aproximadamente puesta a tierra en la frecuencia de corte del segundo. Entonces, por la realimentación la base de Q2 también lo está. De esta forma, la resistencia vista por el capacitor C3 es aproximadamente R23. En consecuencia, la frecuencia de corte asociada a C3 (suponiendo que C2//C15 es un corto en dicha frecuencia) es:



Sin embargo, el capacitor C15 es del mismo orden que C3. Por lo que el boostrap influye en la frecuencia de corte antes mencionada. Es entonces que en la simulación la frecuencia de corte es 0,8Hz, según puede verse en la siguiente imagen:

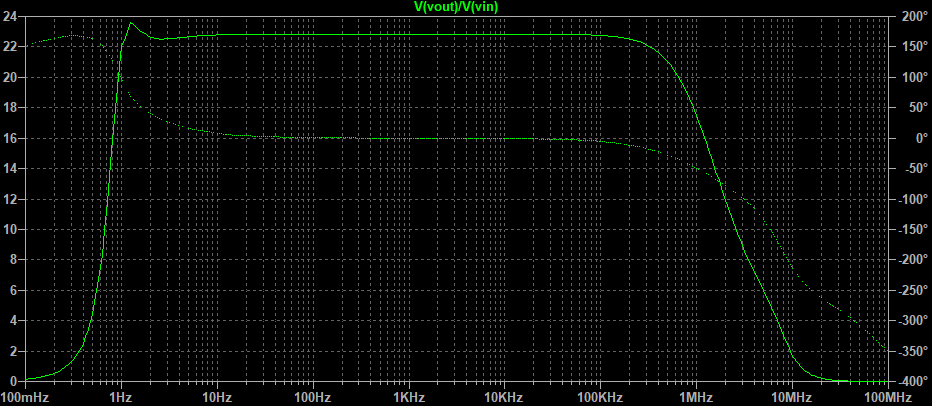
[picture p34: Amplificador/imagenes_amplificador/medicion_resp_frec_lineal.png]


Con una frecuencia de corte inferior en el orden del Hertz, se garantiza que el giro de fase creado por el polo asociado a este termine de darse en el orden de los 10Hz. De esta forma, dicho giro de fase no afecta a las frecuencias audibles.

Por otra parte, el capacitor de entrada C1 posee un valor de 47uF, ya que de esta forma el polo creado por este se halla en el orden del Hertz y coincide con un cero creado por el boostrap en dicha frecuencia. De este modo, la frecuencia de corte inferior resulta ser aproximadamente la de la realimentación.

### Impedancia de entrada
Los resistores R25 y R26 valen 1,1kohm para poder igualar las corrientes de base de Q1 y Q2 en continua y evitar desapareamientos en el punto de reposo. Debido a esto, de no utilizarse el *boostrap* se tendría una impedancia de entrada del orden de los kiloohms (debido a que la impedancia de entrada del par diferencial en el sistema a lazo cerrado es mucho mayor a ese orden y se encuentra en paralelo a (R25+R26), si despreciamos la resistencia del generador de señal solo para fines de analizar la situación cualitativamente). 
El *boostrap*, en un principio, aprovecha el hecho de que la realimentación hace que la tensión en la base de Q2 sea ligeramente menor a la de Q1 ya que:



Y entonces:


En consecuencia, al convertirse (C2//C15) en un corto en señal, se fuerza una diferencia de potencial pequeña entre los extremos de R25,  teniendo esta una resistencia equivalente mucho mayor a su valor real.

El valor de (C2//C15) determina la frecuencia inferior a partir de la cual actuará el *bootstrap*. 

Por otro lado, en la práctica, de no colocarse R24, el *bootstrap* tendrá un Q que hará que la resistencia de entrada alcance un pico para una frecuencia dada, y luego decaiga para valores inferiores y superiores de frecuencia. Cuanto mayor es R24, menor es la resistencia equivalente que crea el *boostrap*. Sin embargo, al crecer, R24 convierte el pico antes mencionado en una zona de frecuencias medias para la cual la impedancia de entrada tiene un valor constante, que es lo deseado. 

Es entonces que utilizando C2//C15 = 470uF y R24 = 50ohm se obtiene la respuesta en frecuecia deseada según las especificaciones para la impedacia, tal como se muestra en la siguiente figura:



Por último, vale aclarar que se han utilizado dos capacitores en paralelo (C2 y C15), ya que C2, al ser cerámico, no ve deteriorado su valor al aumentar la frecuencia tanto como el electrolítico (C15).

### Impedancia de salida
La impedancia de salida a lazo abierto viene dada por (suponiendo que solamente se activa una rama de las de salida, funcionando el amplificador en clase B):



Entonces, la ganancia a lazo cerrado es:



Este valor es mucho menor al mínimo requerido por las especificaciones (20mohm). Sin embargo, en la simulación se observa que los valores de impedancia son mucho mayores y del orden de los 20ohm, tal y como se puede ver en la siguiente imagen para una carga de 8ohm por ejemplo:



Es posible que esto se deba al hecho de que la ganancia de lazo experimenta cambios de ordenes de mágnitud a frecuencias bajas, de forma que la impedancia de entrada se ve afectada por este comportamiento y sufre variaciones imprevistas en los cálculos teóricos realizados. 

### PSNR
#### Vmax
El capacitor C7 fue agregado con el fin de mejorar la PSNR en bajas frecuencias, tal y como se adelantó en [descripcion_detallada_amplificador.md](descripcion_detallada_amplificador.md). Se eligió su valor deseando obtener una PSNR menor a -100dB con respecto a Vmax en todo el rango de frecuencias audibles. 
A continuación se muestra ua imagen de la PSNR sin C7:


Y otra con C7:


Por otro lado, C9 y R6 constituye un filtro pasabajos para remover componentes de alta frecuencias del ruido de la fuente de alimentación. Si bien este filtro no es del todo necesario para esta fuente ya que el rechazo de ruido propio del circuito con C7 incluido ya es mayor a los -100dB, se ha decidido incluir a C9 y R6 por motivos de simetría con el filtro de -Vmax, el cual sí es relevante para la PSNR.

#### -Vmax
El filtro compuesto por R8 y C5 fue determinado suponiendo que los cables de alimentación cuentan con una resistencia propia de aproximadamente 1ohm, de modo que el capacitor C8 de 1000u actúa como un filtro en sí (aunque ese no sea su fin inicial). Esto peritió reducir el valor de C5 a 100uF, así como también de R8 a 10ohm para evitar una reducción no despreciable en la máxima excursión de salida.

Bajo la suposición anterior de los cables de alimentación, la PSNR con respecto a -Vmax sin el filtro obtenida por simulación sería:


Y con el filtro:


#### -Vmin
En un principio no resulta de interés filtrar Vmin y -Vmin ya que estas solamente alimentan a la etapa de salida para bajas excursiones. Además, el ripple en estas alimentaciones puede ser controlado por medio del diseño de las fuentes de swiching; mientras que el ruido será filtrado por los capacitores de  C16 y C17 y las resistencia de los cables que comunican la fuente de switching con el amplificador. 

Sin embargo, un buen filtrado es de interés para -Vin, ya que esta polariza el cascode de la etapa diferencial. Para ello se ha armado un filtro entre el resistor de base R5 = 15kohm (cuya funcionalidad es también limitar la corriente por la base de Q5 y Q6 en caso de problemas con las fuentes o fallas en el circuito) y el capacitor C11. Se eligió C11 de 1uF para que pudiera ser cerámico, con una consiguiente mejor respuesta en frecuencia.

A continuación se muestra una imagen de la PSNR con respecto a -Vmin sin el filtro:



Y con el filtro:


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

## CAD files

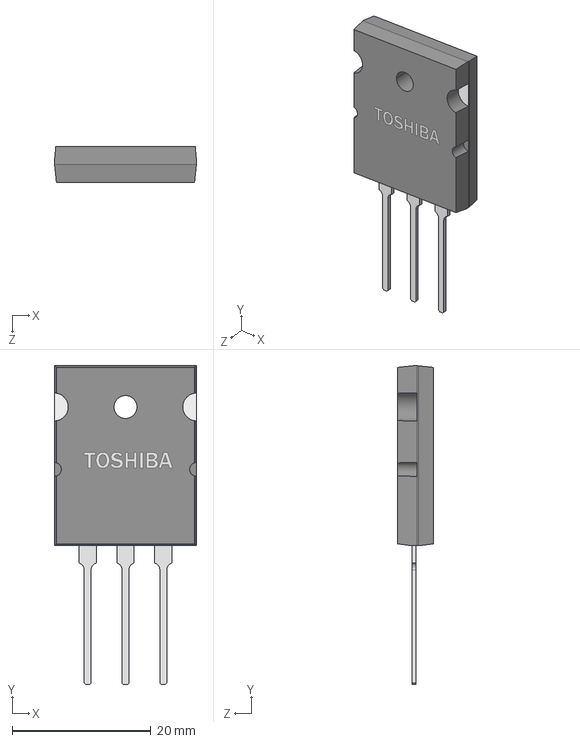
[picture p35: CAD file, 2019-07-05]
Amplificador/pcb_amplificador/proyecto_kicad_actualizado/librerias/footprints/to264.step
20.5 x 46.0 x 5.20 mm

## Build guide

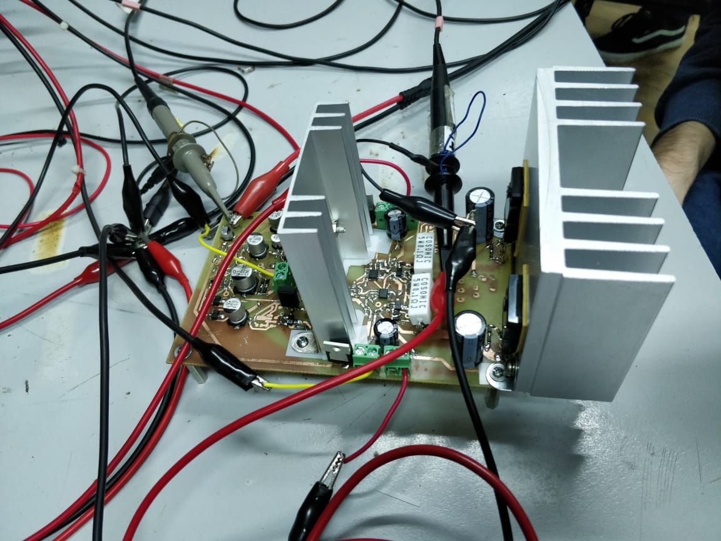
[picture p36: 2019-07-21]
Amplificador/mediciones_amplificador/fotos_mediciones_19_7_19/circuito_armado_19_7_19.jpeg

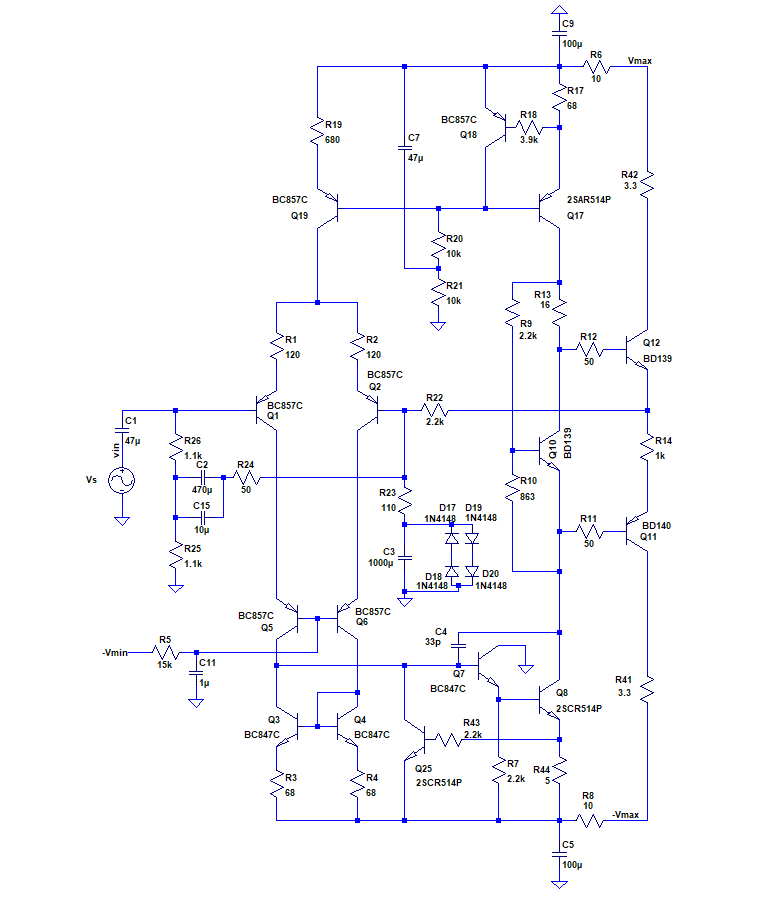
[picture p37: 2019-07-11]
Amplificador/imagenes_amplificador/mediciones_amplificador/fotos_mediciones_10_7_19/esquema_circuito_armado_10_7_19.png

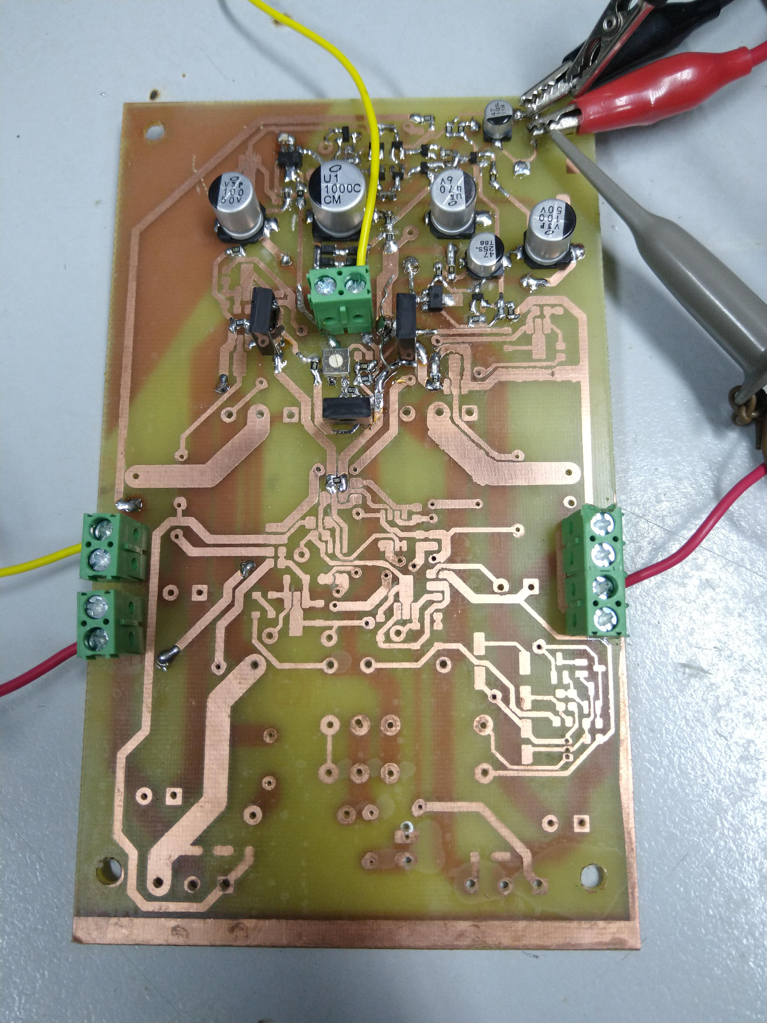
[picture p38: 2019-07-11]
Amplificador/mediciones_amplificador/fotos_mediciones_10_7_19/circuito_armado_10_7_19.jpg

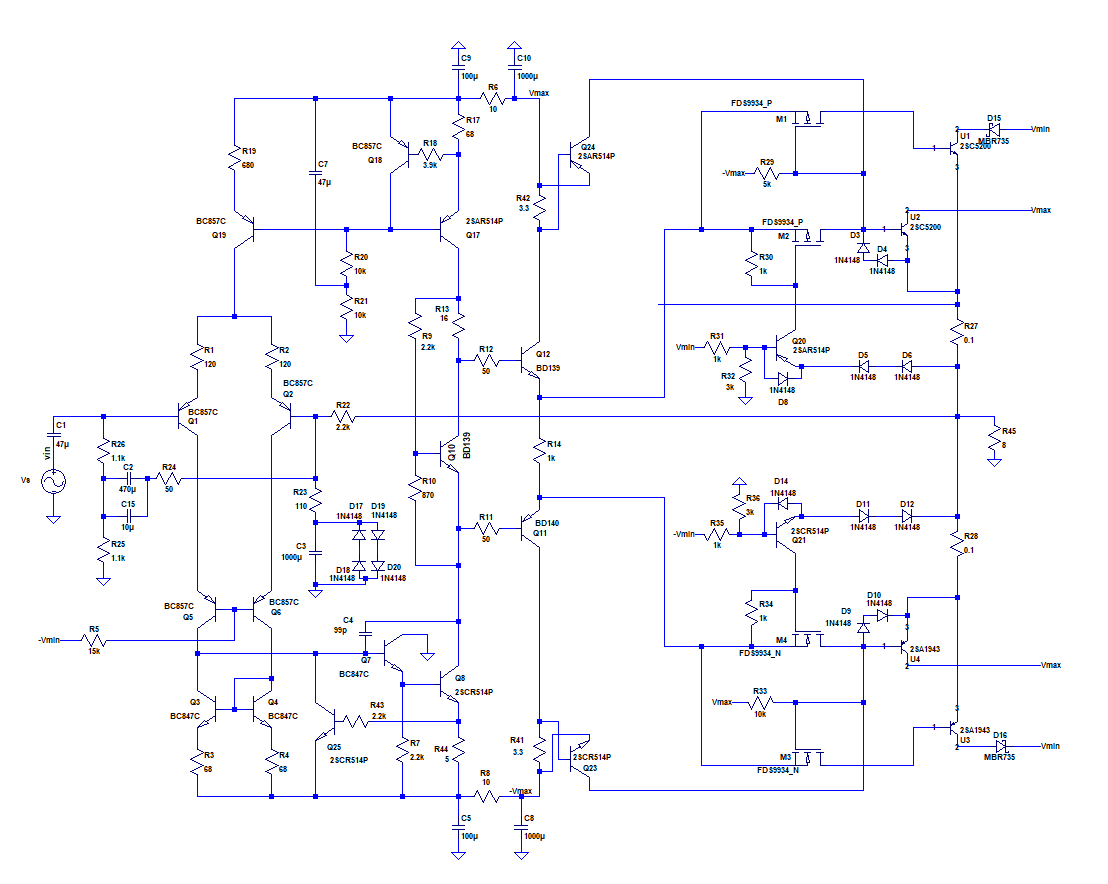
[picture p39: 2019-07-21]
Amplificador/imagenes_amplificador/mediciones_amplificador/fotos_mediciones_19_7_19/esquema_circuito_armado_19_7_19.png

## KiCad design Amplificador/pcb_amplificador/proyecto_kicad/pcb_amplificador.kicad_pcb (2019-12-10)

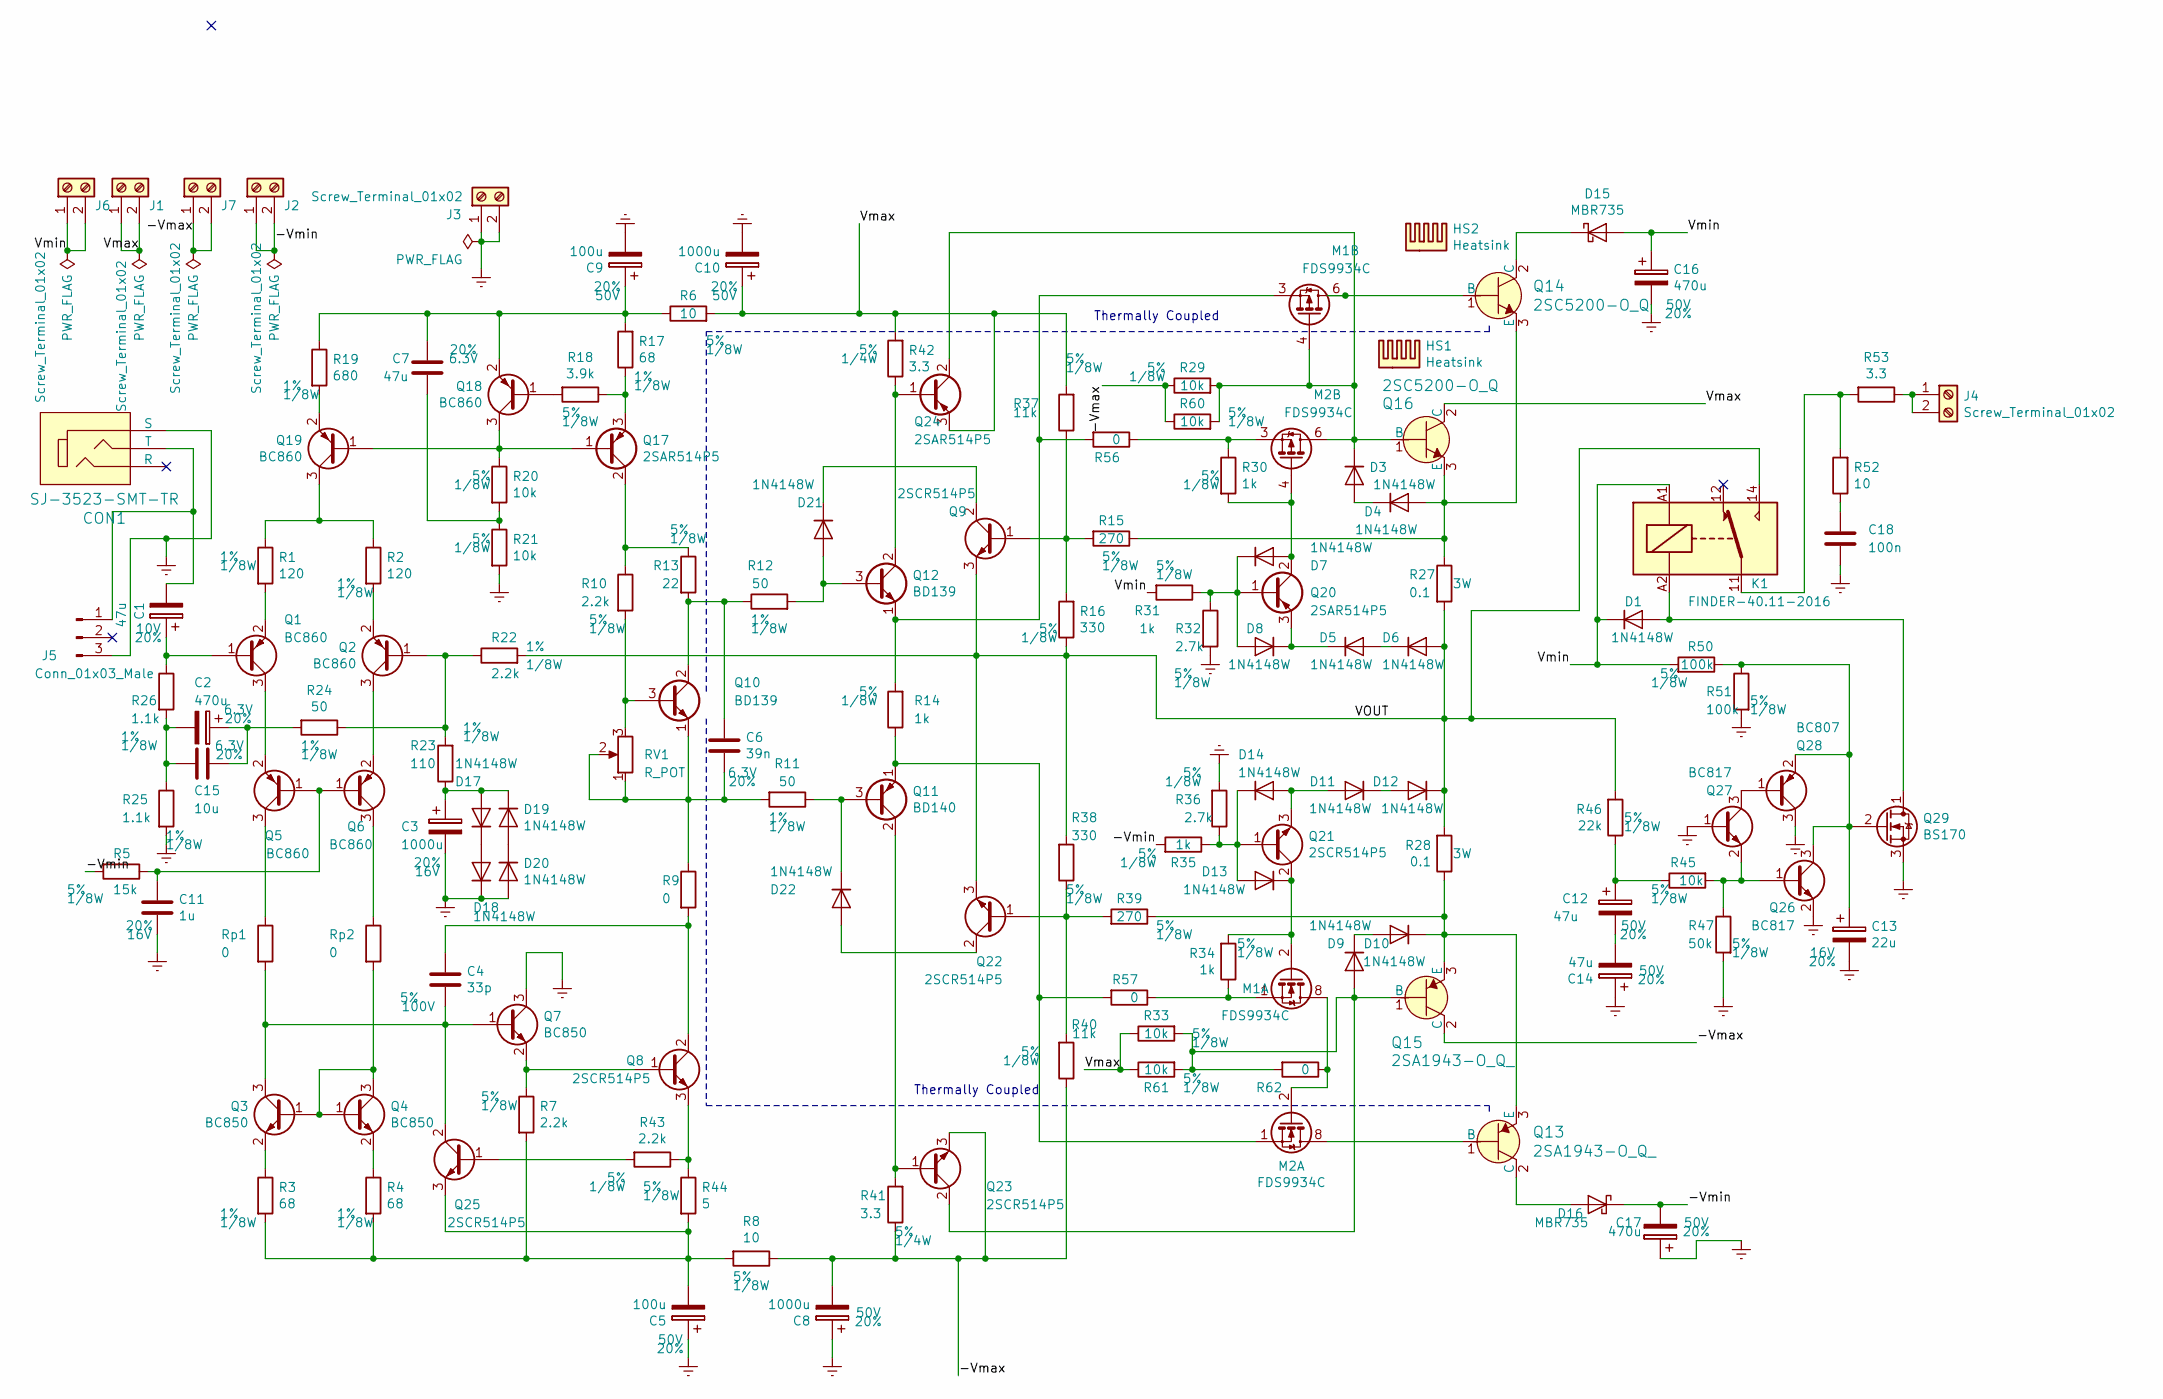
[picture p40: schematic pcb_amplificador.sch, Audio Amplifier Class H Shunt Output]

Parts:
C1: 47u; CP_Elec_5x5.4; Voltage 10V; Tolerance 20%
C2: 470u; CP_Elec_8x10.5; Voltage 6.3V; Tolerance 20%
C3: 1000u; CP_Elec_10x10.5; Voltage 16V; Tolerance 20%
C4: 33p; C_0805_2012Metric_Pad1.15x1.40mm_HandSolder; Tolerance 5%; Voltage 100V
C5, C9: 100u; CP_Elec_8x10.5; Voltage 50V; Tolerance 20%
C6: 39n; C_0805_2012Metric_Pad1.15x1.40mm_HandSolder; Voltage 6.3V; Tolerance 20%
C7: 47u; CP_Elec_6.3x5.4; Voltage 6.3V; Tolerance 20%
C8, C10: 1000u; CP_Radial_D12.5mm_P5.00mm; Voltage 50V; Tolerance 20%
C11: 1u; C_0805_2012Metric_Pad1.15x1.40mm_HandSolder; Tolerance 20%; Voltage 16V
C12, C14: 47u; CP_Elec_6.3x5.4; Voltage 50V; Tolerance 20%
C13: 22u; CP_Elec_5x5.4; Voltage 16V; Tolerance 20%
C15: 10u; C_0805_2012Metric_Pad1.15x1.40mm_HandSolder; Voltage 6.3V; Tolerance 20%
C16, C17: 470u; CP_Radial_D12.5mm_P5.00mm; Voltage 50V; Tolerance 20%
C18: 100n; C_Disc_D7.5mm_W5.0mm_P7.50mm
CON1: SJ-3523-SMT-TR; Switch_Slide_11.6x4mm_SJ-3523-SMT; MPN SJ-3523-SMT-TR; Digi-Key_PN CP-3523SJCT-ND
D1, D3, D4, D5, D6, D7, D8, D9, D10, D11, D12, D13, D14, D17, D18, D19, D20, D21, D22: 1N4148W; D_SOD-123
D15, D16: MBR735; TO-220-2_Vertical
HS1: Heatsink; disipador_1.8C
HS2: Heatsink; disipador_5.1C
J1, J2, J3, J4, J6, J7: Screw_Terminal_01x02; PhoenixContact_MCV_1,5_2-G-3.5_1x02_P3.50mm_Vertical
J5: Conn_01x03_Male; PinHeader_1x03_P2.54mm_Vertical
K1: FINDER-40.11-2016; Relay_SPDT_Schrack-RP-II-1-16A-FormC_RM5mm
M1, M2: FDS9934C; SOIC-8_3.9x4.9mm_P1.27mm
Q1, Q2, Q5, Q6, Q18, Q19: BC860; SOT-23_Handsoldering
Q3, Q4, Q7: BC850; SOT-23_Handsoldering
Q8, Q9, Q21, Q22, Q23, Q25: 2SCR514P5; SOT-89-3_Handsoldering
Q10, Q12: BD139; TO-126-3_Vertical
Q11: BD140; TO-126-3_Vertical
Q13, Q15: 2SA1943-O_Q_; TO-3P-5; MPN 2SA1943-O(Q); Digi-Key_PN 2SA1943-OQ-ND
Q14, Q16: 2SC5200-O_Q; TO-3P-5; MPN 2SC5200-O(Q); Digi-Key_PN 2SC5200-OQ-ND
Q17, Q20, Q24: 2SAR514P5; SOT-89-3_Handsoldering
Q26, Q27: BC817; SOT-23_Handsoldering
Q28: BC807; SOT-23_Handsoldering
Q29: BS170; TO-92_Inline
R1, R2: 120; R_0805_2012Metric_Pad1.15x1.40mm_HandSolder; Tolerance 1%
R3, R4, R17: 68; R_0805_2012Metric_Pad1.15x1.40mm_HandSolder; Tolerance 1%
R5: 15k; R_0805_2012Metric_Pad1.15x1.40mm_HandSolder; Tolerance 5%
R6, R8: 10; R_0805_2012Metric_Pad1.15x1.40mm_HandSolder; Tolerance 5%
R7, R10, R43: 2.2k; R_0805_2012Metric_Pad1.15x1.40mm_HandSolder; Tolerance 5%
R9, R56, R57, R62: 0; R_1206_3216Metric_Pad1.42x1.75mm_HandSolder
R11, R12, R24: 50; R_0805_2012Metric_Pad1.15x1.40mm_HandSolder; Tolerance 1%
R13: 22; R_0805_2012Metric_Pad1.15x1.40mm_HandSolder; Tolerance 5%
R14, R30, R31, R34, R35: 1k; R_0805_2012Metric_Pad1.15x1.40mm_HandSolder; Tolerance 5%
R15, R39: 270; R_0805_2012Metric_Pad1.15x1.40mm_HandSolder; Tolerance 5%
R16, R38: 330; R_0805_2012Metric_Pad1.15x1.40mm_HandSolder; Tolerance 5%
R18: 3.9k; R_0805_2012Metric_Pad1.15x1.40mm_HandSolder; Tolerance 5%
R19: 680; R_0805_2012Metric_Pad1.15x1.40mm_HandSolder; Tolerance 1%
R20, R21, R29, R33, R45, R60, R61: 10k; R_0805_2012Metric_Pad1.15x1.40mm_HandSolder; Tolerance 5%
R22: 2.2k; R_0805_2012Metric_Pad1.15x1.40mm_HandSolder; Tolerance 1%
R23: 110; R_0805_2012Metric_Pad1.15x1.40mm_HandSolder; Tolerance 1%
R25, R26: 1.1k; R_0805_2012Metric_Pad1.15x1.40mm_HandSolder; Tolerance 1%
R27, R28: 0.1; R_Axial_DIN0411_L9.9mm_D3.6mm_P12.70mm_Horizontal
R32, R36: 2.7k; R_0805_2012Metric_Pad1.15x1.40mm_HandSolder; Tolerance 5%
R37, R40: 11k; R_0805_2012Metric_Pad1.15x1.40mm_HandSolder; Tolerance 5%
R41, R42: 3.3; R_0805_2012Metric_Pad1.15x1.40mm_HandSolder; Tolerance 5%
R44: 5; R_0805_2012Metric_Pad1.15x1.40mm_HandSolder; Tolerance 5%
R46: 22k; R_0805_2012Metric_Pad1.15x1.40mm_HandSolder; Tolerance 5%
R47: 50k; R_0805_2012Metric_Pad1.15x1.40mm_HandSolder; Tolerance 5%
R50, R51: 100k; R_0805_2012Metric_Pad1.15x1.40mm_HandSolder; Tolerance 5%
R52: 10; R_Axial_DIN0614_L14.3mm_D5.7mm_P15.24mm_Horizontal
R53: 3.3; R_Axial_DIN0207_L6.3mm_D2.5mm_P7.62mm_Horizontal
RV1: R_POT; Potentiometer_Bourns_3314G_Vertical
Rp1, Rp2: 0; R_0805_2012Metric_Pad1.15x1.40mm_HandSolder

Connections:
/-Vmax: C8.2, J7.1, J7.2, Q15.2 (C), Q23.3 (E), R8.1, R29.1, R40.1, R41.1, R60.1
/-Vmin: C17.2, D16.1 (K), J2.1, J2.2, R5.2, R35.2
/VOUT: D6.2 (A), D12.1 (K), K1.14, Q9.3 (E), Q22.3 (E), R16.1, R22.2, R27.2, R28.2, R38.2, R46.2
/Vmax: C10.1, J1.1, J1.2, Q16.2 (C), Q24.3 (E), R6.2, R33.1, R37.2, R42.2, R61.1
/Vmin: C16.1, D1.1 (K), D15.2 (A), J6.1, J6.2, K1.A1, R31.2, R50.2
Earth: C3.2, C5.1, C8.1, C9.2, C10.2, C11.2, C13.2, C14.1, C16.2, C17.1, C18.1, CON1.1 (S), D18.1 (K), D20.2 (A), J3.1, J3.2, J5.3, Q7.3 (C), Q26.2 (E), Q27.1 (B), Q28.3 (C), Q29.3 (S), R21.2, R25.2, R32.2, R36.2, R47.2, R51.2
unnamed: C1.1, Q1.1 (B), R26.1
unnamed: C1.2, CON1.2 (T), J5.1
unnamed: C3.1, D17.2 (A), D19.1 (K), R23.1
unnamed: C4.1, Q8.2 (C), R9.2
unnamed: C4.2, Q3.3 (C), Q7.1 (B), Q25.2 (C), Rp1.2
unnamed: C5.2, Q25.3 (E), R3.2, R4.2, R7.2, R8.2, R44.2
unnamed: C6.1, Q10.1 (E), R9.1, R11.2, RV1.1, RV1.2
unnamed: C6.2, Q10.2 (C), R12.1, R13.2
unnamed: C7.1, R20.2, R21.1
unnamed: C7.2, C9.1, Q18.2 (E), R6.1, R17.2, R19.1
unnamed: C11.1, Q5.1 (B), Q6.1 (B), R5.1
unnamed: C12.1, R45.1, R46.1
unnamed: C12.2, C14.2
unnamed: C13.1, Q26.3 (C), Q28.2 (E), Q29.2 (G), R50.1, R51.1
unnamed: C2.1, C15.1, R24.2
unnamed: C2.2, C15.2, R25.1, R26.2
unnamed: C18.2, R52.1
unnamed: D1.2 (A), K1.A2, Q29.1 (D)
unnamed: D3.1 (K), M1.4 (G), M2.5 (D), M2.6 (D), Q16.1 (B), Q24.2 (C), R29.2, R60.2
unnamed: D3.2 (A), D4.1 (K)
unnamed: D4.2 (A), Q14.3 (E), Q16.3 (E), R15.1, R27.1
unnamed: D5.1 (K), D8.1 (K), Q20.3 (E)
unnamed: D5.2 (A), D6.1 (K)
unnamed: D7.1 (K), D8.2 (A), Q20.1 (B), R31.1, R32.1
unnamed: D7.2 (A), M2.4 (G), Q20.2 (C), R30.2
unnamed: D9.2 (A), Q15.1 (B), Q23.2 (C), R33.2, R61.2, R62.2
unnamed: D10.1 (K), Q13.3 (E), Q15.3 (E), R28.1, R39.1
unnamed: D9.1 (K), D10.2 (A)
unnamed: D11.1 (K), D12.2 (A)
unnamed: D11.2 (A), D14.2 (A), Q21.3 (E)
unnamed: D13.1 (K), M1.2 (G), Q21.2 (C), R34.2
unnamed: D13.2 (A), D14.1 (K), Q21.1 (B), R35.1, R36.1
unnamed: D15.1 (K), Q14.2 (C)
unnamed: D16.2 (A), Q13.2 (C)
unnamed: D17.1 (K), D18.2 (A)
unnamed: D19.2 (A), D20.1 (K)
unnamed: D21.1 (K), Q9.2 (C)
unnamed: D21.2 (A), Q12.3 (B), R12.2
unnamed: D22.1 (K), Q11.3 (B), R11.1
unnamed: D22.2 (A), Q22.2 (C)
unnamed: J4.1, J4.2, R53.1
unnamed: K1.11, R52.2, R53.2
unnamed: M1.1 (S), R34.1, R57.1
unnamed: M1.3 (1), Q12.1 (E), R14.2, R56.2
unnamed: M1.5 (D), M1.6 (D), Q14.1 (B)
unnamed: M1.7 (D), M1.8 (D), M2.2 (G), R62.1
unnamed: M2.1 (S), Q11.1 (E), R14.1, R57.2
unnamed: M2.3 (1), R30.1, R56.1
unnamed: M2.7 (D), M2.8 (D), Q13.1 (B)
unnamed: Q1.2 (E), R1.2
unnamed: Q1.3 (C), Q5.2 (E)
unnamed: Q2.1 (B), R22.1, R23.2, R24.1
unnamed: Q2.2 (E), R2.2
unnamed: Q2.3 (C), Q6.2 (E)
unnamed: Q3.1 (B), Q4.1 (B), Q4.3 (C), Rp2.2
unnamed: Q3.2 (E), R3.1
unnamed: Q4.2 (E), R4.1
unnamed: Q5.3 (C), Rp1.1
unnamed: Q6.3 (C), Rp2.1
unnamed: Q7.2 (E), Q8.1 (B), R7.1
unnamed: Q8.3 (E), R43.1, R44.1
unnamed: Q9.1 (B), R15.2, R16.2, R37.1
unnamed: Q10.3 (B), R10.2, RV1.3
unnamed: Q11.2 (C), Q23.1 (B), R41.2
unnamed: Q12.2 (C), Q24.1 (B), R42.1
unnamed: Q17.1 (B), Q18.3 (C), Q19.1 (B), R20.1
unnamed: Q17.2 (C), R10.1, R13.1
unnamed: Q17.3 (E), R17.1, R18.1
unnamed: Q18.1 (B), R18.2
unnamed: Q19.2 (E), R19.2
unnamed: Q19.3 (C), R1.1, R2.1
unnamed: Q22.1 (B), R38.1, R39.2, R40.2
unnamed: Q25.1 (B), R43.2
unnamed: Q26.1 (B), Q27.2 (E), R45.2, R47.1
unnamed: Q27.3 (C), Q28.1 (B)

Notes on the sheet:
Thermally Coupled

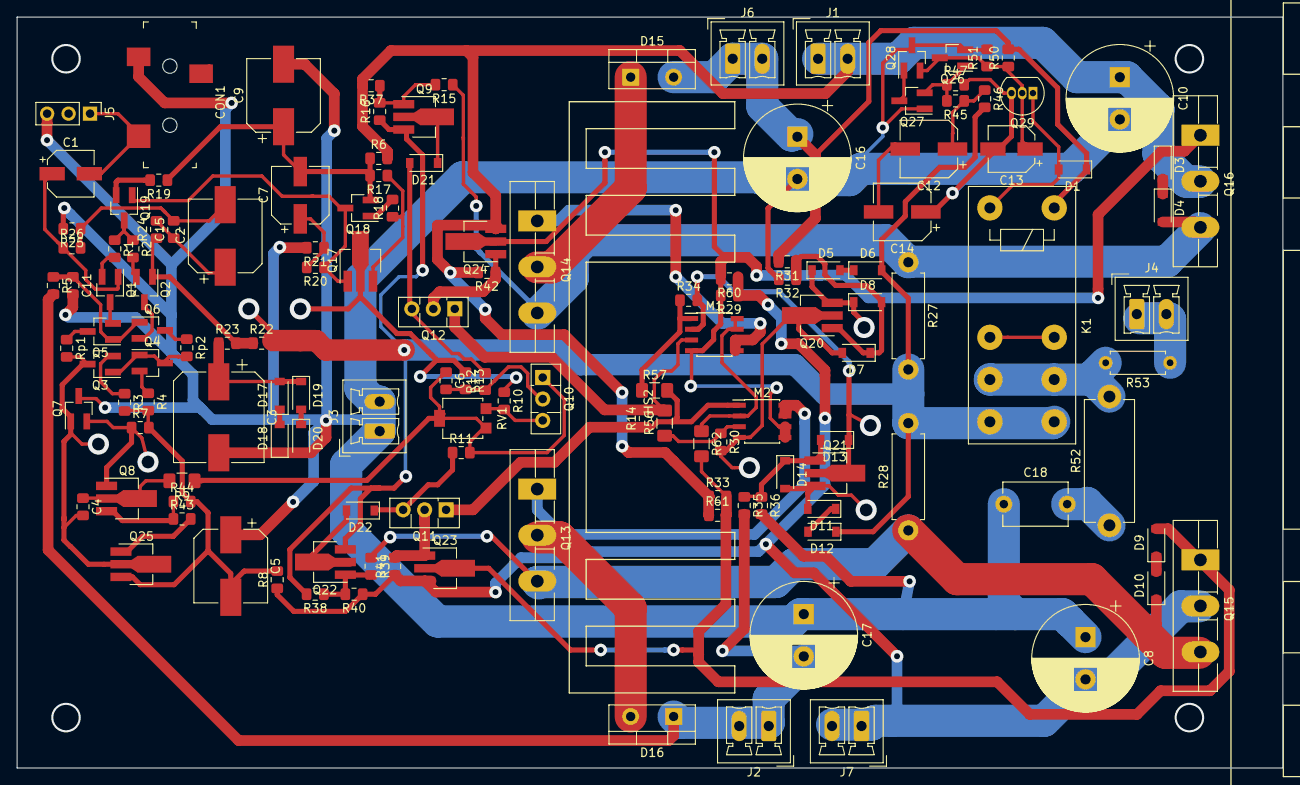
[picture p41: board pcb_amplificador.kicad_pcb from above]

Board: 2 copper layers, 149.9 x 88.9 mm, 140 parts (0 on the bottom side), 81 nets.

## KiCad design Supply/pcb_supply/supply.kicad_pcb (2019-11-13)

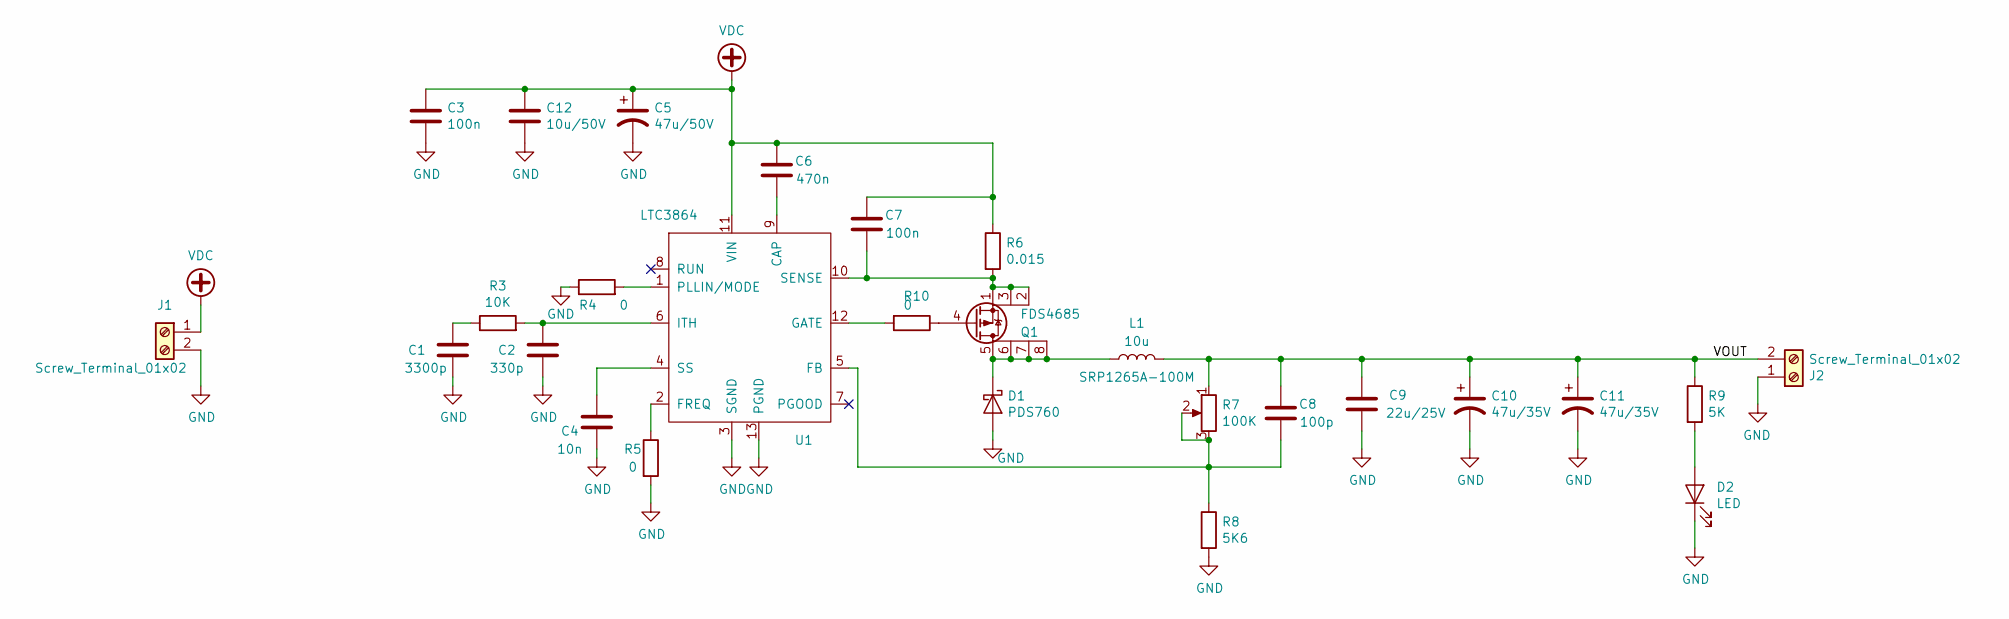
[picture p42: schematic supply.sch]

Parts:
C1: 3300p; C_0805_2012Metric
C2: 330p; C_0805_2012Metric
C3, C7: 100n; C_0805_2012Metric
C4: 10n; C_0805_2012Metric
C5: 47u/50V; CP_Elec_6.3x7.7
C6: 470n; C_0805_2012Metric
C8: 100p; C_0805_2012Metric
C9: 22u/25V; C_0805_2012Metric
C10, C11: 47u/35V; CP_Elec_6.3x5.8
C12: 10u/50V; C_0805_2012Metric
D1: PDS760; D_PowerDI-5
D2: LED; LED_0805_2012Metric
J1, J2: Screw_Terminal_01x02; 691102710002
L1: 10u; L_Bourns_SRP1245A
Q1: FDS4685; SOIC-8_3.9x4.9mm_P1.27mm
R3: 10K; R_0805_2012Metric
R4, R5, R10: 0; R_0805_2012Metric
R6: 0.015; R_2512_6332Metric
R7: 100K; Potentiometer_Bourns_3314J_Vertical
R8: 5K6; R_0805_2012Metric
R9: 5K; R_0805_2012Metric
U1: LTC3864; MSOP-12-1EP_3x4mm_P0.65mm_EP1.65x2.85mm

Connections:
/VOUT: C8.1, C9.1, C10.1, C11.1, J2.2, L1.2, R7.1, R9.1
GND: C1.2, C2.2, C3.2, C4.2, C5.2, C9.2, C10.2, C11.2, C12.2, D1.2 (A), D2.1 (K), J1.2, J2.1, R4.1, R5.2, R8.2, U1.3 (SGND), U1.13 (PGND)
unnamed: C1.1, R3.1
unnamed: C2.1, R3.2, U1.6 (ITH)
unnamed: C4.1, U1.4 (SS)
unnamed: C6.2, U1.9 (CAP)
unnamed: C7.2, Q1.1 (S), Q1.2 (S), Q1.3 (S), R6.2, U1.10 (SENSE)
unnamed: C8.2, R7.2, R7.3, R8.1, U1.5 (FB)
unnamed: D1.1 (K), L1.1, Q1.5 (D), Q1.6 (D), Q1.7 (D), Q1.8 (D)
unnamed: D2.2 (A), R9.2
unnamed: Q1.4 (G), R10.1
unnamed: R4.2, U1.1 (PLLIN/MODE)
unnamed: R5.1, U1.2 (FREQ)
unnamed: R10.2, U1.12 (GATE)
VDC: C3.1, C5.1, C6.1, C7.1, C12.1, J1.1, R6.1, U1.11 (VIN)

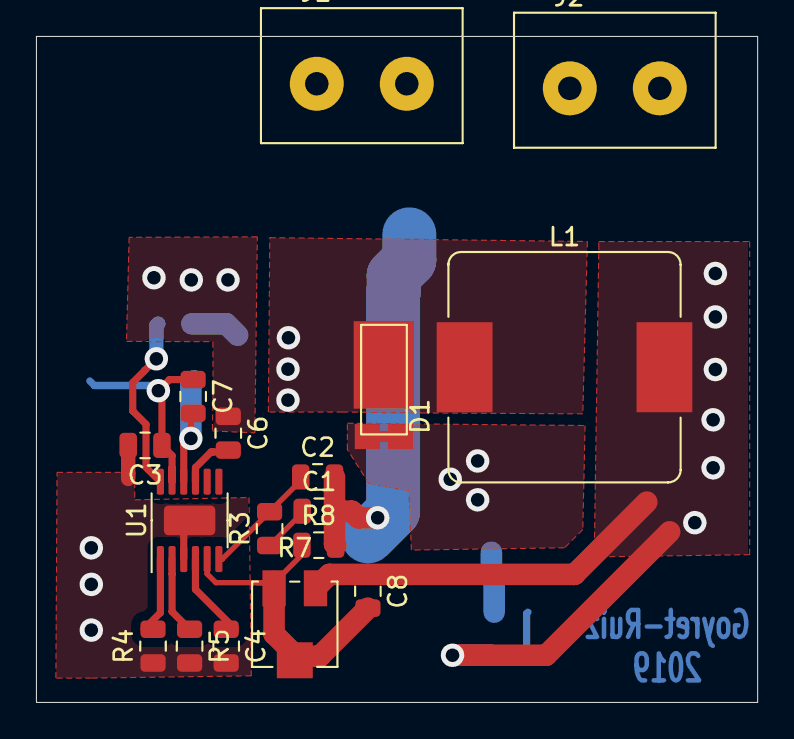
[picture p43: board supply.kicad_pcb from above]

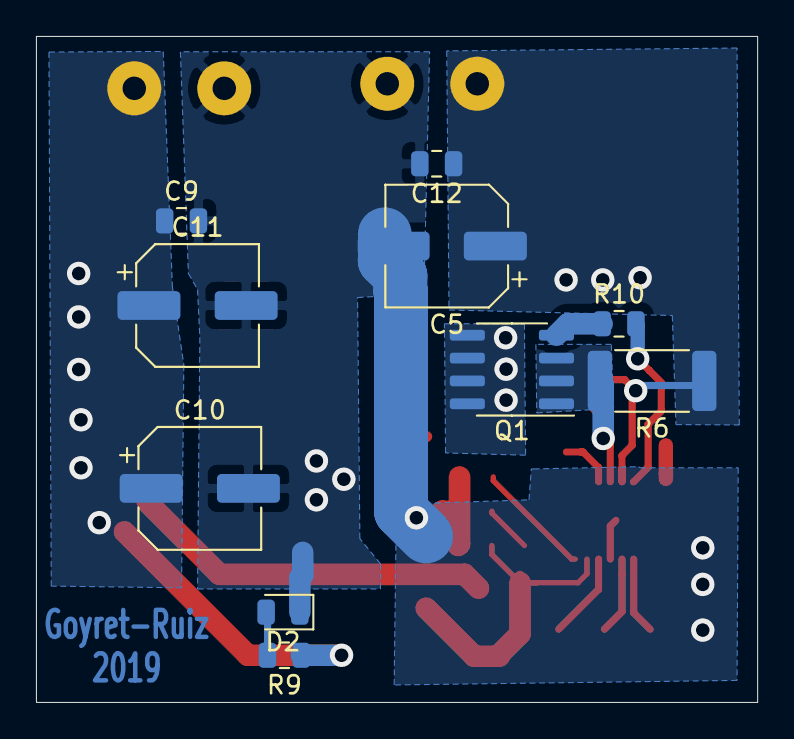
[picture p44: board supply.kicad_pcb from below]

Board: 2 copper layers, 40.1 x 37.0 mm, 27 parts (10 on the bottom side), 15 nets.

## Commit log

2019-05-19 Agregado de hojas de datos de amplificadores comerciales y documentos útiles sobre amplificadores G y H.
    [comparacion_amplificadores_comerciales.xlsx]
2019-05-19 Archivos ordenados en carpeta DOC
    [comparacion_amplificadores_comerciales.xlsx]
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2019-05-20 Corrección de errores en el boceto
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2019-05-26 Agregado de las simulación de las llaves de conmutación para la etapa de potencia en paralelo
2019-05-27 Correción sobre los comentarios en la simulación de la llave de conmutación.
2019-05-27 Correción sobre los comentarios en la simulación de la llave de conmutación(2).
2019-05-27 Agregado de simulación del THD del amplificador con etapa de salida en paralelo.
2019-05-27 Agregado de simulación del THD del amplificador con etapa de salida en paralelo.(2)
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2019-06-08 Actualización del circuito amplificador intregando protecciones por sobrecorriente y modificando la alimentación del par diferencial cascode para reducir la distorsión.
2019-06-11 Agregado de limitación de corriente para la VAS; cambio en la ubicación del potenciómetro en la VAS.
2019-06-11 Agregado del esquematico del amplificador (falta la protección contra tensión de DC en la salida)
    [pcb_amplificador.kicad_pcb, pcb_amplificador.sch]
2019-06-12 Agregado de la protección contra DC del amplificador en la simulación del LTSpice
2019-06-12 Actualizacion del esquematico del amplificador
    [pcb_amplificador.sch]
2019-06-13 Actualizacion del esquematico del amplificador(2)
    [pcb_amplificador.sch]
2019-06-15 Comienzo del diseño del PCB del amplificador
    [pcb_amplificador.sch]
2019-06-15 Avance con el PCB
    [pcb_amplificador.kicad_pcb, pcb_amplificador.sch]
2019-06-15 Avance con el PCB (2)
    [pcb_amplificador.sch]
2019-06-18 Avance PCB
    [pcb_amplificador.kicad_pcb, pcb_amplificador.sch]
2019-06-20 Modificacion del modelo de los transistores de salida y cambios a algunos capacitores de filtrado del circuito; actualización de las especificaciones y agregado de diagramas.
    [pcb_amplificador.sch]
2019-06-20 Modificacion del modelo de los transistores de salida y cambios a algunos capacitores de filtrado del circuito; actualización de las especificaciones y agregado de diagramas.(2)
2019-06-20 Modificacion del modelo de los transistores de salida y cambios a algunos capacitores de filtrado del circuito; actualización de las especificaciones y agregado de diagramas.(3)
2019-06-20 PCB y simulación de fuente switching
    [supply.kicad_pcb, supply.sch]
2019-06-22 Cambios en el esquematico del PCB
    [pcb_amplificador.sch]
2019-06-25 Primer diseño completo de todo el PCB del amplificador
    [pcb_amplificador.kicad_pcb, pcb_amplificador.sch]
2019-06-25 Actualización de la documentación
    [pcb_amplificador.kicad_pcb]
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2019-06-29 Emprolijado directorio PCB
    [supply.kicad_pcb, supply.sch]
2019-07-02 PCB supply arreglos menores
    [supply.kicad_pcb]
2019-07-05 Se mueve el contenido sobre PCB de la rama PCB_review a develop
    [pcb_amplificador-B.Mask.gbr, pcb_amplificador-B.Paste.gbr, pcb_amplificador-B.SilkS.gbr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]
2019-07-05 Cambios en la documentación en la carpeta del amplificador y en DOC
2019-07-05 Cambio documentacion Supply
    [supply.kicad_pcb, supply.sch]
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2019-07-26 Actualización de las especificaciones del amplificador
    [_saved_pcb_amplificador.sch, pcb_amplificador.kicad_pcb, pcb_amplificador.sch]
2019-07-26 Nuevos cambios en las especificaciones y ampliación de la documentación del amplificador
    [pcb_amplificador-B.Mask.gbr, pcb_amplificador-B.Paste.gbr, pcb_amplificador-B.SilkS.gbr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]
2019-07-26 Mediciones supply agregadas
    [supply.kicad_pcb, supply.sch]
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2019-08-01 Cambios varios en la documentación del amplificador; agregado de ecuaciones en latex y gráficos al archivo que explica como se hallaron los valores de los componentes; agregado de documento que expli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
    [pcb_amplificador.sch]
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2019-08-13 Agregado de datos extra de los componentes en el esquemático del amplificador y cambios menores
    [pcb_amplificador.kicad_pcb, pcb_amplificador.sch]
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2019-08-27 Agregado de los resultados de la medicion de la proteccion de DC
    [pcb_amplificador.kicad_pcb, pcb_amplificador.sch]
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2019-09-07 Agregado de los resultados de las mediciones de THD con las protecciones y desarrollo de la explicación del comportamiento de los limitadores de corriente en el semicilo negativo
    [pcb_amplificador-B.Mask.gbr, pcb_amplificador-B.Paste.gbr, pcb_amplificador-B.SilkS.gbr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]
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2019-09-24 Revision PCB supply
    [supply.kicad_pcb, supply.sch]
2019-09-24 Comienzo con la 3ra revisión de la fuente de switching
    [supply.kicad_pcb, supply.sch]
2019-09-25 Comienzo con la 3ra revisión de la fuente de switching(2)
    [supply.kicad_pcb, supply.sch]
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2019-11-05 Agregado de conexión Kelvin a la fuente de switching rediseñada
    [supply.kicad_pcb]
2019-11-13 2da version de la placa de la fuente de switching para mandar a hacer
    [supply.kicad_pcb]
2019-12-10 Agregado de las mediciones finales y algunos cambios menores
    [pcb_amplificador.kicad_pcb]
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
